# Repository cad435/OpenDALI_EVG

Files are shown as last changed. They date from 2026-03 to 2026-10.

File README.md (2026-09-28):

# OpenDALI_EVG

A completely open-source Proof of concept for a ultra low standby current **DALI-2-compatible** Electronic Control Gear (ECG/EVG) for controlling LEDs. Built around the **CH32V003** RISC-V microcontroller. Implements IEC 62386 — not certified by, affiliated with, or endorsed by the DALI Alliance (DiiA).

> [!WARNING]
> This project is a work in progress and not yet ready for production use. Hardware designs and firmware are subject to change.

> [!NOTE]
> **Trademark notice:** *DALI*, *DALI-2*, *D4i*, *DALI+* and *DiiA* are trademarks of the Digital Illumination Interface Alliance (DiiA). This project is an independent open-source implementation and compatible with the IEC 62386 standard. It is referred to as *DALI-2-compatible*, it has not undergone DiiA certification and may not be marketed as a DALI product.
> Use for educational purposes only!

<p align="center">
  WhatsApp Image 2026-07-07 at 23 02 12
</p>
<p align="center">
  WhatsApp Image 2026-07-07 at 23 02 12 (1)
</p>
<p align="center">
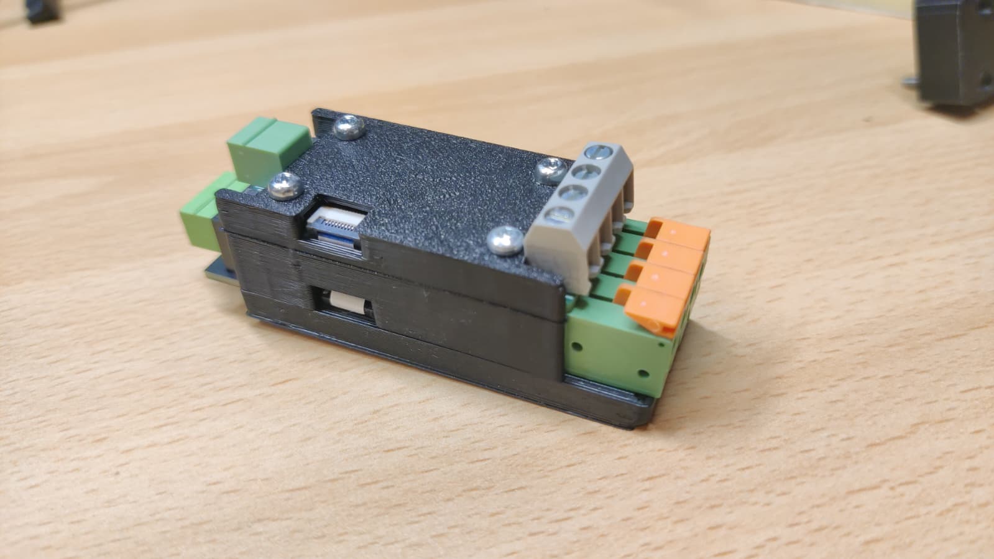
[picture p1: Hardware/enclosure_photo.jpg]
Assembled unit in its printed enclosure
  
</p>

## Overview

This project implements a DALI-2-compatible control gear device per **IEC 62386-101** (bus/protocol) and **IEC 62386-102** (control gear commands), including **DT8 colour control** (IEC 62386-209) for RGBW and colour temperature mixing.

Key highlights:
- Full DALI-2-compatible protocol stack in bare-metal C
- 4-channel PWM output (RGBW) at 20 kHz with 2400-step resolution
- WS2812/SK6812 addressable LED strip support (SPI+DMA, up to ~300 LEDs)
- Logarithmic dimming curve per IEC 62386-102
- 16 scenes, 16 groups, fade engine with configurable fade time/rate
- Full commissioning support (INITIALISE, RANDOMISE, SEARCHADDR, PROGRAM SHORT) — incl. spec-conformant DTR roles for memory bank reads (FW v0.3+)
- All configuration persisted to AT24C256 EEPROM (deferred-write, 5 s debounce)
- Bus-powered: the MCU runs entirely from the DALI bus (< 2 mA quiescent)
- Over-the-air firmware updates via DALI bus (IEC 62386-105 bootloader with Fletcher-16 payload check, auto-resume on fault)
- Verified interop with Mi-Boxer DALI controllers and OpenKNX GW-REG1-Dali gateway

## Project Structure

```
OpenDALI_EVG/
├── Firmware/           CH32V003 DALI slave firmware (PlatformIO project)
├── Bootloader/         IEC 62386-105 compatible DALI bootloader (1908 / 1920 B, I2C EEPROM staging)
├── EVG-Updater/        C# Avalonia tool (.NET 8) — GUI + CLI for firmware flash and bus scan
├── EVG-Flasher/        C# Avalonia app — first-time provisioning of blank chips via WCH-LinkE
├── Hardware/           PCB schematics, Gerbers, JLCPCB BOM/CPL (Controller V0.3 + two LoadBoards V0.1)
└── Simulations/        LTspice PHY and power supply simulations
```

### Firmware

The firmware is a standalone PlatformIO project targeting the CH32V003F4U6, built on [ch32v003fun](https://github.com/cnlohr/ch32v003fun). Supports 8 LED output modes selected via a single `EVG_MODE_xxx` define:

- **ONOFF**: PSU_CTRL switching only — no PWM, no timers
- **PWM modes**: SINGLE (1ch), CCT (2ch), RGB (3ch), RGBW (4ch) — TIM1 at 20 kHz, 2400-step resolution
- **Digital LED modes**: WS2812, SK6812_RGB, SK6812_RGBW — SPI1+DMA on PC6

See [Firmware/README.md](Firmware/README.md) for architecture, commands, and test documentation.

### Bootloader

IEC 62386-105 compatible firmware-over-DALI-bus bootloader (1908 / 1920 bytes, 99.4% of the CH32V003 boot area). Uses 32-bit forward frames for bulk data transfer (3 bytes/frame, ~2.5 min for a full firmware image). Firmware is staged in AT24C256 I2C EEPROM before committing to flash. Validates Block 0 GTIN + EVG mode ID, and verifies the Block 1 firmware payload with a Fletcher-16 checksum at FINISH. On checksum mismatch the BL auto-resumes the previous user firmware (no manual recovery needed). See [Bootloader/README.md](Bootloader/README.md).

### EVG-Updater

C# Avalonia application (.NET 8) — GUI + CLI for both **firmware flashing** (`flash <bin>`) and **bus discovery** (`scan`). The canonical update client. Talks to the OpenKNX GW-REG1-Dali gateway via WebSocket. See [EVG-Updater/README.md](EVG-Updater/README.md).

### EVG-Flasher

Avalonia desktop app for **blank** CH32V003 boards: bootloader to the boot area, option bytes, firmware, then a read-back check of the option bytes — in a loop, one chip after another. The configuration dropdown is fed from `Firmware/platformio.ini`, so a new `[env:...]` section appears without touching the app, and the strip modes get an extra LED-count field. See [EVG-Flasher/README.md](EVG-Flasher/README.md).

### Hardware

PCB designs (schematics, Gerbers, JLCPCB assembly files). See [Hardware/README.md](Hardware/README.md) for board descriptions and details.

- **Controller** — DALI-compatible PHY + CH32V003 MCU board
- **LoadBoard 250W RGBW** — 4-channel PWM LED driver + AC mains switching (ACST410 triac, MOC3043)
- **LoadBoard 250W Digital LED** — isolated single-wire output for WS2812/SK6812 strips, same AC mains switching

**Design goals:**
- **Ultra-low standby (~30 mW):** When LEDs are off, the triac disconnects the external PSU entirely from mains — eliminating its standby consumption. The Controller remains fully operational, powered solely from the DALI bus (< 2 mA).
- **Modular architecture:** The Controller is a standalone unit handling all communication and signal generation. LoadBoards are interchangeable and connect via a standardized FFC interface — swap them to match different power classes without changing the Controller.

### Simulations

LTspice simulations for the DALI-compatible PHY layer:
- **Phy_Non-Isolated.asc** — Bus-powered PHY with direct MCU connection
- **Phy_Isolated.asc** — Optocoupler-isolated PHY variant

## Hardware Platform

| Parameter | Value |
|---|---|
| MCU | CH32V003F4U6 (RISC-V, 48 MHz, 16 KB Flash, 2 KB RAM) |
| DALI-compatible Interface | Via PHY transceiver (PC3 RX, PC4 TX) |
| PWM Channels | 4 (RGBW via TIM1, partial remap 1) |
| Digital LED | WS2812/SK6812 via SPI1+DMA (same pin as PWM CH1, compile-time select) |
| Supply | Bus-powered from the DALI bus only (DC-DC converter) — MCU is always bus-powered |

See [Hardware/README.md](Hardware/README.md) for the full pin assignment table and board details.

## Status

Firmware is functional and verified with the **OpenKNX GW-REG1-Dali gateway** end-to-end. Tested operations include addressing (INITIALISE/RANDOMISE/COMPARE/PROGRAM SHORT), all 16-bit forward commands (level control, scenes, groups, fade), DT8 colour control (RGBW + Tc), bank 0 memory reads, and IEC 62386-105 firmware updates over the bus (with Fletcher-16 integrity check and auto-resume on fault).

Multi-vendor coexistence verified with Mi-Boxer DALI controllers on the same bus (2026-05-17).

## License

MIT

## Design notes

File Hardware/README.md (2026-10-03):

# Hardware

PCB designs for the OpenDALI_EVG project.

> Trademark notice — see [root README](../README.md): *DALI*, *DALI-2* etc. are DiiA trademarks; this project is an independent IEC 62386 implementation, not DiiA-certified.

## Boards

| Board | Description |
|---|---|
| [Controller](Controller/Readme.md) | DALI PHY + CH32V003, bus-powered. Pin assignment, J4 load-board interface, hardware validation. |
| [LoadBoard 250W RGBW](DALI_Load_250W_RGBW/Readme.md) | Mains switching and 4-channel PWM LED driver. Work in progress. |
| [LoadBoard 250W Digital LED](DALI_Load_250W_DigitalLED/Readme.md) | Mains switching and isolated single-wire output for WS2812/SK6812 strips. Work in progress. |

## Enclosure

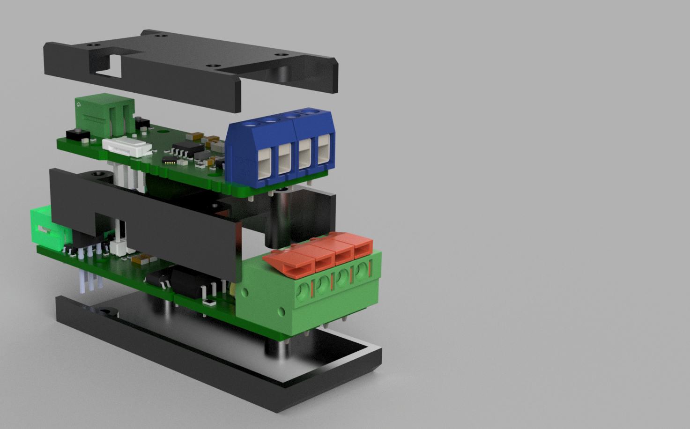
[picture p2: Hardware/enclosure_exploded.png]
Exploded view of the enclosure


3D-printable housing, as a Fusion 360 archive (`DALI_EVG.f3z`) and as a neutral
STEP export (`DALI_EVG.step`). One enclosure covers the Controller together with
any of the load boards above.

Ready-to-print parts are in [`stl/`](stl/) — the housing is a three-part
stack: `Bot`, `Mid` and `Top`.

Eight **M2.5 x 10 mm** screws hold the stack together, four from each side.

> **⚠ Mains safety:** fit the screws on the load-board side only with the
> enclosure part in place, so the plastic sits between screw head and board
> and only the thread passes through the PCB. A screw head resting directly on
> the load board brings an accessible metal part too close to the mains copper:
> the reinforced insulation required by IEC 60664-1 is then no longer met.

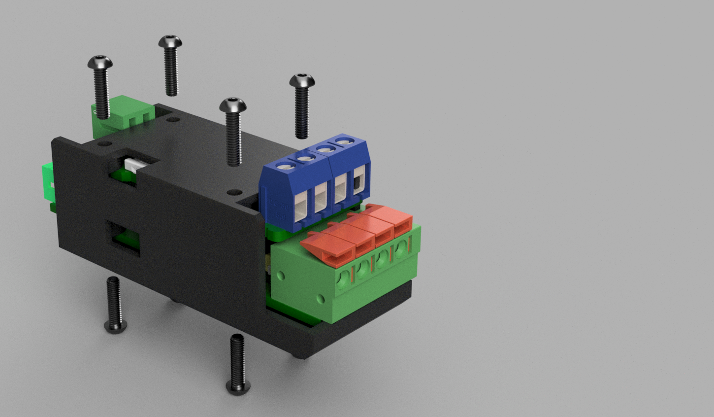
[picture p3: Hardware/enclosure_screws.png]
Screw positions on the assembled enclosure


Assembled unit in its printed enclosure

Controller and load board are linked by a **10-pin FFC, 0.5 mm pitch, 25-50 mm,
reverse** — contacts on opposite sides at the two ends. A same-side cable
does not work: at one end its contacts face away from the connector and
never touch it.

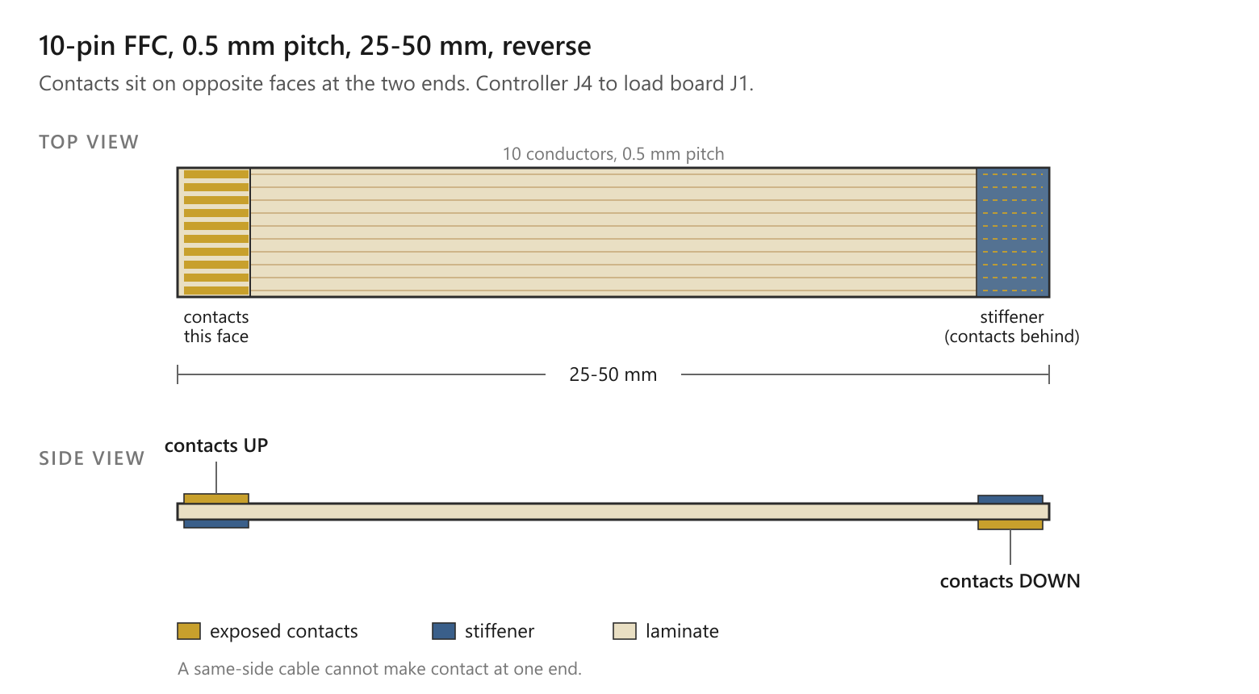
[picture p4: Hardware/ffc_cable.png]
10-pin reverse FFC cable


## Manufacturing

The Gerber files are ready for upload to any PCB manufacturer. The JLCPCB files (BOM + CPL) allow direct ordering with SMT assembly through [JLCPCB](https://jlcpcb.com/).

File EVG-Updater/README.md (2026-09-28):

# DALI-bus Firmware Updater

<p align="center">

</p>

C# desktop application ([Avalonia](https://avaloniaui.net/)) for updating and inspecting OpenDALI EVG devices via the DALI bus, using an OpenKNX GW-REG1-Dali gateway.

Run without arguments for the GUI; every subcommand below also works headless, so scripted flashing is unaffected by the UI.

Implements the IEC 62386-105 firmware update protocol over 32-bit DALI forward frames, plus a read-only bus scan that probes shorts 0..63 and reads bank 0 identity.

> Trademark notice — see [root README](../README.md): *DALI*, *DALI-2* etc. are DiiA trademarks; this project is an independent IEC 62386 implementation, not DiiA-certified. Educational purposes only

## Requirements

- .NET 8.0 SDK
- OpenKNX GW-REG1-Dali gateway on the network
- Target device running OpenDALI EVG firmware with IEC 62386-105 bootloader in boot area

## Build

```bash
dotnet build EVG_Updater.slnx
```

## Usage

```
EVG_Updater <command> [options]
```

Commands:

| Command | Purpose |
|---|---|
| `flash <firmware.bin>` | Flash a firmware image to an EVG via DALI bus |
| `scan` | Probe the DALI bus and list discovered gear |
| *(no args)* | Launch the graphical interface |

Run `EVG_Updater <command> --help` for per-command details.

### GUI Mode

Run without arguments to launch the graphical interface:

```bash
EVG_Updater.exe
```

The GUI provides:
- Gateway IP configuration (default: 192.168.178.131)
- Bus scan with sortable device grid (Short / Random / GTIN / Mode / DT / FW / HW / Updatable)
- Firmware .bin file selection
- DALI short address (0-63)
- GTIN and EVG Mode ID for Block 0 validation
- **Override mode check** — announces the mode the device currently reports,
  taken from the scan, instead of the Mode ID field. This is what lets one of
  our EVGs be reflashed to a *different* mode: the bootloader validates against
  the mode the running firmware wrote, and the new firmware writes its own on
  first boot. "Update All" already works this way and ignores the setting.
- Progress bar and scrollable log output

### `flash` — Firmware Update

```bash
EVG_Updater.exe flash firmware.bin [options]
```

Options:

| Option | Default | Description |
|---|---|---|
| `--ip <address>` | 192.168.178.131 | Gateway IP address |
| `--addr <0-63>` | 0 | DALI short address of target device |
| `--gtin <hex>` | 3452334E0CAD | 6-byte GTIN in hex (must match device EEPROM) |
| `--mode <1-8>` | 5 (RGBW) | EVG mode ID (must match device EEPROM) |
| `--help`, `-h` | | Show usage help |

Exit codes:
- `0` — Success
- `1` — Argument or connection error
- `2` — Firmware update failed

Examples:

```bash
# Update device at address 0 with default settings
EVG_Updater.exe flash firmware.bin

# Update device at address 5, RGB mode
EVG_Updater.exe flash firmware.bin --addr 5 --mode 4

# Use a different gateway
EVG_Updater.exe flash firmware.bin --ip 10.0.0.50

# Build and flash in one command (from Firmware/ directory)
pio run && ../EVG-Updater/EVG_Updater.exe flash .pio/build/EVG_RGBW/firmware.bin
```

### `scan` — Bus Discovery

Probes every short address 0..63 with `QUERY GEAR PRESENT`, then for each
responding gear reads bank 0 (GTIN, FW/HW versions, EVG mode via serial
field) and the 24-bit random address. Read-only — never modifies addressing
or any persistent state.

```bash
EVG_Updater.exe scan [options]
```

Options:

| Option | Default | Description |
|---|---|---|
| `--ip <address>` | 192.168.178.131 | Gateway IP address |
| `--ours-gtin <hex>` | 3452334E0CAD | GTIN to flag as updatable in the Updatable column |
| `--quiet`, `-q` | | Suppress progress log, print only the result table |
| `--help`, `-h` | | Show usage help |

Output mirrors the GUI grid columns: **Short, Random, GTIN, Mode, DT, FW, HW, Updatable**.

Example (quiet mode for scripting):

```bash
$ EVG_Updater.exe scan --quiet
Short  Random    GTIN          Mode  DT     FW   HW   Updatable
-----  --------  ------------  ----  -----  ---  ---  ---------
0      0xCAF8CB  3452334E0CAD  RGBW  DT8    0.2  0.1  yes
1      0x93D441  3452334E0CAD  RGBW  DT8    0.2  0.1  yes
2      0xFE7CCA  —             ?     multi  —    —    no
```

Underlying DALI sequence (IEC 62386-102 Ed 2.0 §11.x cmd 197): `QUERY GEAR PRESENT`
on each short, then once globally `DTR1 ← 0` (bank 0) and `DTR0 ← 0x03` (GTIN start)
via the special commands `0xC3` / `0xA3`, then per gear 18× `READ MEMORY LOCATION`
to walk bank 0 offsets 0x03..0x14 (post-increment of DTR0 is gear-local, so back-to-back
reads on the same gear walk the bank without re-setting DTR0), plus `QUERY DEVICE TYPE`
and `QUERY RANDOM ADDRESS (H/M/L)` per gear.

Devices that don't implement bank 0 (some non-conformant third-party gear like Mi-Boxer)
appear with `—` / `?` in the bank-0-derived columns but still get their `Random` and
device-type info from the dedicated queries.

`DaliBusScanner.cs` has a `READ_INTER_FRAME_DELAY_MS` constant (default `0`, well-tested
since the FW back-to-back-drop fix). Bump it to 100 ms as a workaround if you somehow
encounter a regression where scan results look shifted.

## EVG Mode IDs

| ID | Mode | Description |
|----|---|---|
| 1 | ONOFF | Relay/switch output |
| 2 | SINGLE | Single-channel PWM |
| 3 | CCT | 2-channel warm/cool white |
| 4 | RGB | 3-channel RGB PWM |
| 5 | RGBW | 4-channel RGBW PWM |
| 6 | WS2812 | Addressable LED strip (GRB) |
| 7 | SK6812_RGB | Addressable LED strip (GRB) |
| 8 | SK6812_RGBW | Addressable LED strip (GRBW) |

## Update Protocol (IEC 62386-105)

The update runs in 4 phases:

1. **Enter Bootloader** — Send QUERY FW UPDATE FEATURES (verify device supports updates), then START FW TRANSFER (config repeat, 2× within 100 ms). Device responds YES and resets into bootloader.

2. **Block 0 Validation** — Send BEGIN BLOCK 0 followed by TRANSFER BLOCK DATA frames containing GTIN, device key (EVG mode ID), and the pre-computed Fletcher-16 of the firmware payload at offsets `0x2C` / `0x2D`. The bootloader validates GTIN + mode against EEPROM identity. Updater polls `QUERY BLOCK FAULT` once at the end of this phase — that's the only window where the BL's `blockFault` flag can reflect a Block-0 fault (BEGIN BLOCK 1 wipes it).

3. **Firmware Transfer** — Send BEGIN BLOCK 1, then TRANSFER BLOCK DATA frames (3 firmware bytes per frame, ~3,600 frames for ~11 KB firmware). Data is staged in AT24C256 EEPROM (starting at 0x0080). **No mid-transfer polls** — they're structurally dead (BL's `blockFault` flag can only be set during Block-0 reception or at FINISH, never during Block-1 reception; payload integrity is verified inside the FINISH handler).

4. **Commit** — Send FINISH FW UPDATE (config repeat). The bootloader compares its accumulated Fletcher-16 against the expected value from Block 0:
   - Match: `flush_to_eeprom()` + `copy_eeprom_to_flash()` + auto-reboot into new firmware. Bus stays silent → updater sees `null` timeout → `SUCCESS`.
   - Mismatch: BL sends `0xFF` (= YES, "not done"), then auto-reboots into the existing firmware (flash untouched). Updater receives `0xFF` → reports `FAILED: Fletcher mismatch, re-run flash`.

## Project Structure

```
EVG-Updater/
├── EVG_Updater.slnx             Solution file (open in Visual Studio)
├── README.md                     This file
└── EVG_Updater/
    ├── EVG_Updater.csproj       .NET 8.0 Avalonia project
    ├── Program.cs                Entry point — subcommand dispatch (GUI / flash / scan)
    ├── App.axaml(.cs)            Avalonia application, themes, DataGrid style
    ├── Views/MainWindow.axaml    GUI layout
    ├── ViewModels/MainViewModel  GUI state, commands, bus orchestration
    ├── Models/DeviceRow.cs       one scan result as a grid row
    ├── DaliGateway.cs            WebSocket client (background reader + in-flight pacing semaphore)
    ├── DaliBootloader.cs         IEC 62386-105 protocol state machine (4-phase update)
    └── DaliBusScanner.cs         Read-only bus scan (shorts 0..63, bank 0, random address)
```

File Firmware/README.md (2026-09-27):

# DALI-2-compatible EVG Firmware

DALI-2-compatible control gear (slave) firmware for the **CH32V003F4U6** RISC-V microcontroller, built on [cnlohr's ch32fun](https://github.com/cnlohr/ch32v003fun) framework. Drives up to 4 PWM channels (RGBW) with full IEC 62386 protocol support, DT8 colour control, and EEPROM persistence.

> Trademark notice — see [root README](../README.md): *DALI*, *DALI-2* etc. are DiiA trademarks; this project is an independent IEC 62386 implementation, not DiiA-certified.

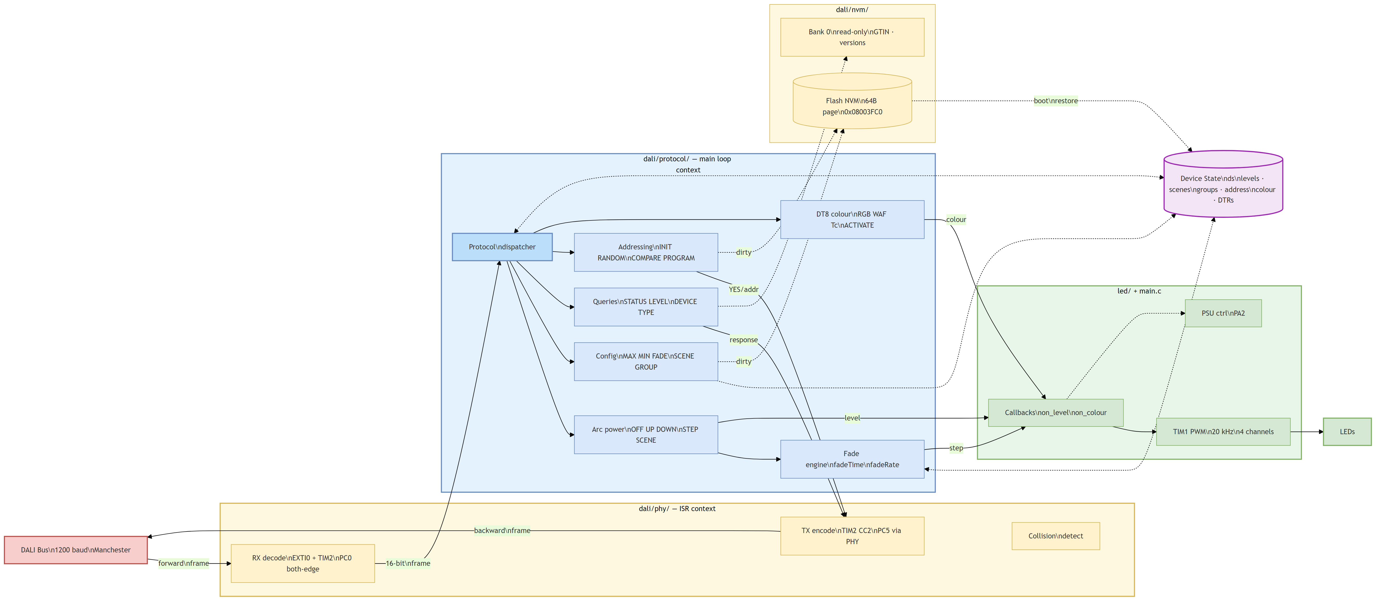
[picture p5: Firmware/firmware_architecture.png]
Firmware Architecture


## EVG Modes

The firmware supports 8 LED output modes, selected via a single `EVG_MODE_xxx` define in `hardware.h` (or `-DEVG_MODE_xxx` compiler flag). All internal configuration (DALI device type, channel count, driver, DT8 features) is derived automatically.

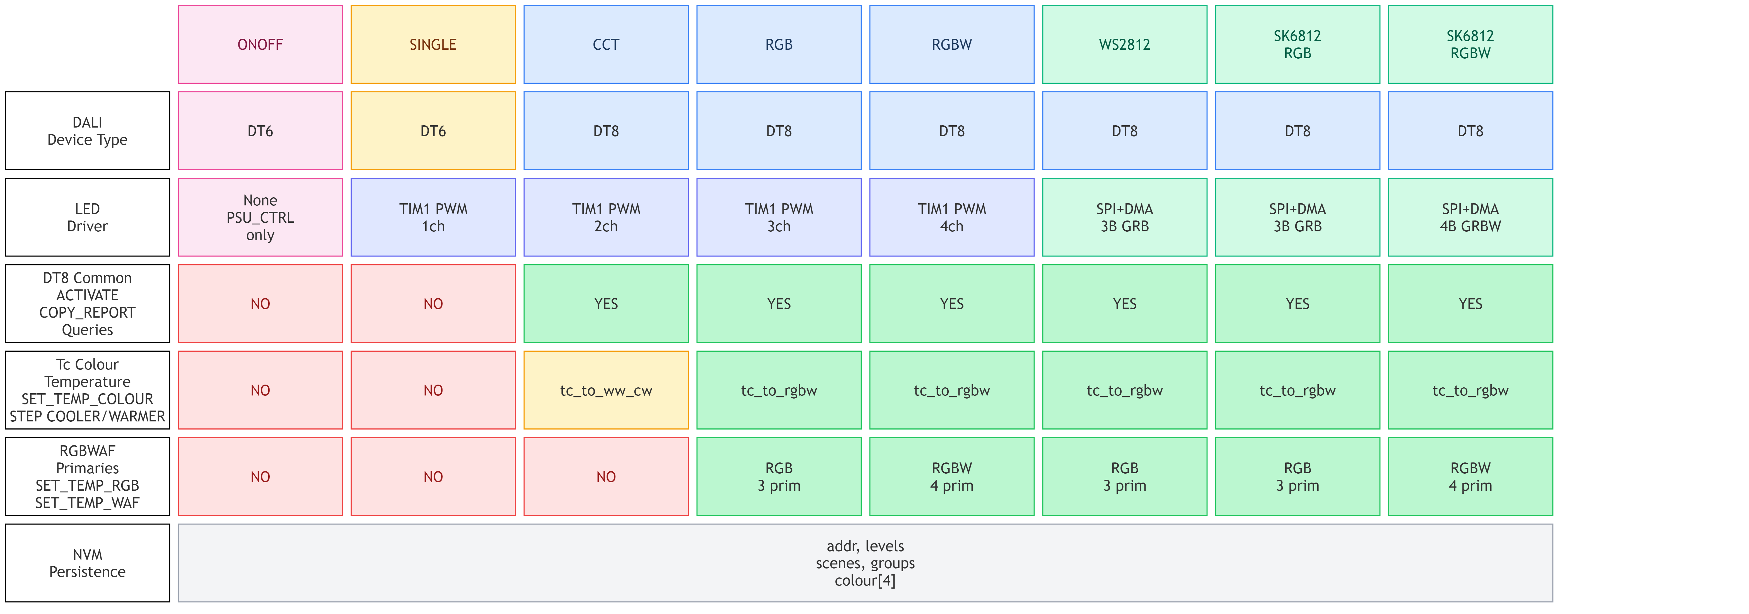
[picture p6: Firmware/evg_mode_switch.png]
EVG Mode Feature Matrix


| Mode | DT | Channels | Driver | Tc | Primary |
|---|-----|---|---|-----|---|
| `EVG_MODE_ONOFF` | 6 | 0 | PSU_CTRL only | - | - |
| `EVG_MODE_SINGLE` | 6 | 1 PWM | TIM1 | - | - |
| `EVG_MODE_CCT` | 8 | 2 PWM | TIM1 | yes | no |
| `EVG_MODE_RGB` | 8 | 3 PWM | TIM1 | yes | yes |
| `EVG_MODE_RGBW` | 8 | 4 PWM | TIM1 | yes | yes |
| `EVG_MODE_WS2812` | 8 | 3 (GRB) | SPI+DMA | yes | yes |
| `EVG_MODE_SK6812_RGB` | 8 | 3 (GRB) | SPI+DMA | yes | yes |
| `EVG_MODE_SK6812_RGBW` | 8 | 4 (GRBW) | SPI+DMA | yes | yes |

Default: `EVG_MODE_RGBW`. ONOFF mode compiles out all LED drivers, log table, and TIM1 — only PSU_CTRL (PA2) switches on/off. PHY_MIN = 254 (any non-zero arc level → full on). SINGLE mode compiles out all DT8 code.

## Features

- **IEC 62386-101** — Manchester-encoded physical layer at 1200 baud with DALI PHY transceiver, bus collision detection
- **IEC 62386-102** — Full DALI protocol: addressing, arc power, fading, scenes, groups, configuration
- **IEC 62386-209 (DT8)** — RGBW colour control with colour temperature (Tc) support
- **Logarithmic dimming** — IEC 62386-102 compliant 254-step lookup table
- **Flash persistence** — All configuration survives power cycles (deferred write with 5s debounce)
- **On/off mode** — PSU_CTRL-only relay/switch output, no timers or PWM
- **20 kHz PWM** — 4 channels via TIM1 with 2400-step resolution (11.2 bit); dynamic frequency shift to 6.67 kHz at deep dimming levels (keeps every pulse ≥ 250 ns for the isolator/gate-driver chain, duty unchanged; engages only while every channel is ≤ 3.75 % duty to avoid audible MLCC whine) plus a 250 ns minimum-pulse failsafe clamp
- **WS2812/SK6812 support** — Alternative digital LED output via SPI1+DMA on PC6. The core must not sleep during a transfer (`__WFI()` stalls SPI/DMA on this part), so `led_driver_busy()` guards the sleep condition; strip data is re-sent every `LED_REFRESH_MS` (default 1 s) purely as glitch recovery.

## What Works

| Area | Status |
|---|---|
| Forward frame RX (16-bit and 32-bit Manchester decode) | Working |
| Backward frame TX (8-bit Manchester encode) | Working |
| Short address, group, and broadcast addressing | Working |
| Full addressing protocol (INITIALISE, RANDOMISE, SEARCHADDR, PROGRAM) | Working |
| Arc power commands (DAPC, OFF, UP/DOWN, STEP, RECALL, SCENE) | Working |
| Fade engine (fadeTime + fadeRate + extended fade time) | Working |
| Configuration commands (42-128) with config repeat validation | Working |
| All standard queries (144-199) | Working |
| READ MEMORY LOCATION (cmd 197) → Memory Bank 0 (read-only gear info) | Working — spec-conformant DTR roles since v0.3 (DTR1=bank, DTR0=offset post-inc, DTR2=look-ahead) per IEC 62386-102:2009 §11.x cmd 197 |
| Structured frame type (`dali_frame_t` with FORWARD/BACKWARD/ERROR/COLLISION/ECHO flags) | Working |
| TX echo / collision detection (via DALI PHY) | Working |
| Status byte (resetState, powerCycleSeen, lampOn, fadeRunning) | Working |
| 16 scenes, 16 groups | Working |
| DT8 RGBW colour control (SET TEMP RGB/WAF, ACTIVATE) | Working |
| DT8 colour temperature with Tc-to-RGBW conversion (2700K-6500K) | Working |
| DT8 queries (247-252) | Working |
| NVM persistence via I2C EEPROM (AT24C256, all config + colour + identity) | Working |
| PSU control output (PA2, auto on/off) | Working |
| WS2812/SK6812 digital LED strip output (SPI1+DMA) | Working — verified on hardware with a logic analyser (bit-exact frames on the wire) |
| DALI PHY transceiver mode (TX/RX with collision detection) | Working |
| IEC 62386-105 START FW TRANSFER (32-bit frame) → bootloader entry | Working |

## What Doesn't Work / Not Implemented

| Area | Reason |
|---|---|
| Memory bank 1 + write access | Read-only bank 0 only; writable banks not implemented |
| DALI-2 diagnostic queries (166-175) | Require hardware monitoring circuitry (current/voltage sensing) |
| CIE xy chromaticity | Requires per-LED spectral calibration |
| ENABLE DAPC SEQUENCE (cmd 9) | Rarely used, complex timing |
| Tc temperature limits (store/query) | Not yet implemented |
| controlGearFailure / lampFailure status bits | Require hardware monitoring (I2C ADC planned) |

## Hardware

CH32V003F4U6 (QFN20, 48 MHz, 16 KB Flash, 2 KB RAM) with DALI PHY transceiver. TIM1 Partial Remap 1 (`RM=01`) enables PC6 dual-use for both PWM and WS2812.

| Pin | Function | Peripheral | Notes |
|-----|---|---|---|
| PA1 | Boot button | GPIO input | Active low at reset → enter DALI bootloader (firmware also reroutes into BL when PA1 is held during NRST/SYSRESETREQ) |
| PA2 | PSU Control | GPIO output | HIGH = external PSU on, LOW = off |
| PC0 | LED3 / Blue PWM | TIM1_CH3 | 20 kHz, 2400-step |
| PC1 | I2C SDA | I2C1 | Reserved for AT24C256C EEPROM |
| PC2 | I2C SCL | I2C1 | Reserved for AT24C256C EEPROM |
| PC3 | DALI RX | EXTI3 | From PHY RX_OUT, both-edge interrupt |
| PC4 | DALI TX | GPIO output | To PHY TX_IN, Manchester encode |
| PC5 | SPI1 SCK → J4.3 | SPI1 | SPI clock to the load board (ribbon J4 pin 3); unused in direct-PWM modes |
| PC6 | LED1 / Red PWM **or** WS2812 | TIM1_CH1 / SPI1_MOSI | Dual-use: PWM or SPI+DMA (compile-time) |
| PC7 | LED2 / Green PWM | TIM1_CH2 | 20 kHz, 2400-step |
| PD0 | *(spare)* | — | Free GPIO (was USB D+ pull-up in old USB-BL prototype; current BL is DALI-only) |
| PD1 | SWDIO | SWD | Single-wire debug |
| PD2 | *(spare)* | — | Free GPIO |
| PD3 | LED4 / White PWM | TIM1_CH4 | 20 kHz, 2400-step |
| PD4 | *(spare)* | — | Free GPIO |
| PD5 | Debug UART TX | USART1_TX | 115200 baud |
| PD6 | Debug UART RX | USART1_RX | 115200 baud |
| PD7 | NRST | Reset | Hardware reset |

See [Hardware/README.md](../Hardware/README.md) for full board details.

## Build & Flash

```bash
pio run                    # Build
pio run -t upload          # Flash via PlatformIO
# or directly:
wlink flash .pio/build/EVG_RGBW/firmware.bin
```

## Provisioning Blank EVGs

First-time programming of a blank chip — bootloader, option bytes and firmware —
is done with [EVG-Flasher](../EVG-Flasher/README.md). It runs the four-step
sequence in a loop and picks the configuration from a dropdown that is fed by
this `platformio.ini`, so a new `[env:...]` section shows up there by itself.

Updating an **already commissioned** EVG happens over the DALI bus with
[EVG-Updater](../EVG-Updater/README.md) instead.

## Documentation

- [Commands_Implemented.md](Commands_Implemented.md) — Full command-by-command status table
- [firmware_architecture.mmd](firmware_architecture.mmd) — Mermaid source for architecture diagram
- [evg_mode_switch.mmd](evg_mode_switch.mmd) — Mermaid source for EVG mode feature matrix
- [test/](test/) — HIL test setup and test scripts

## License

MIT

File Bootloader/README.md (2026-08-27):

# DALI-bus Bootloader for CH32V003 — IEC 62386-105 Compatible

Firmware-over-DALI-bus bootloader using 32-bit forward frames as specified in IEC 62386-105:2020. Fits in the 1920-byte boot area. Receives firmware via the DALI bus protocol, stages it in an external I2C EEPROM, validates device identity via Block 0, then copies to internal flash.

**1,908 / 1,920 bytes (99.4%)** (PlatformIO build, optimised version adopted 2026-08-15) — interoperates with IEC 62386-105 compatible firmware-update masters.

> Trademark notice — see [root README](../README.md): *DALI*, *DALI-2* etc. are DiiA trademarks; this project is an independent IEC 62386 implementation, not DiiA-certified.

## How It Works

- 32-bit forward frame decoder at 1200 baud (IEC 62386-101, 7.4.3)
- Accepts IEC 62386-105 commands: START FW TRANSFER, BEGIN BLOCK, TRANSFER BLOCK DATA, FINISH FW UPDATE, RESTART FW, QUERY BLOCK FAULT, QUERY FW UPDATE RUNNING
- **Block 0 validation**: GTIN (6 bytes) and Device key byte 0 (EVG mode ID) are compared against values stored in EEPROM by the firmware. Mismatch → QUERY BLOCK FAULT returns YES → master aborts
- **Fletcher-16 integrity check**: Block 0 also carries a 2-byte Fletcher-16 of the firmware payload at positions `0x2C`/`0x2D`. The bootloader accumulates `fa`/`fb` over every received Block 1 firmware byte and compares against the expected value at FINISH. Mismatch → flash commit aborted, master sees BLOCK FAULT
- Block 1..n firmware data is extracted from the block structure (headers and trailing CRC skipped) and streamed to the I2C EEPROM staging area
- On FINISH FW UPDATE (no fault): EEPROM contents are copied to internal flash, then device auto-reboots into the new firmware (silent on the bus — master sees timeout)
- On FINISH FW UPDATE (Fletcher mismatch): BL sends `0xFF` (= YES, "not done") as an explicit fault signal, then auto-resumes the **existing** user firmware that's still untouched in flash. Master can detect the explicit fault and report `UPDATE FAILED` to the user. Added 2026-05-17 to eliminate the previous failure mode where the EVG appeared "dead" until manual power-cycle.
- Other DALI devices on the bus are **not affected** — 32-bit frames are silently ignored per IEC 62386-101

## Speed

3 firmware bytes per 32-bit frame (vs 1 byte per 2 frames in the original bootloader). Expected transfer time for 10 KB firmware: **~2.5 minutes**.

## Boot Entry

Two ways to enter bootloader mode:

1. **Software**: Firmware receives START FW TRANSFER (32-bit, device-addressed), responds YES, sets `FLASH->STATR` bit 14 via the WCH `SystemReset_StartMode` sequence, and resets. The bootloader checks bit 14 on startup and enters update mode if set. Bit 14 is cleared immediately after reading (one-shot).
2. **Hardware**: Hold **PA1 low** during reset. The bootloader enters update mode and responds YES to any subsequent START FW TRANSFER from the master.

If neither condition is met, the bootloader jumps directly to user code.

**Note**: RAM magic words do NOT survive PFIC system reset on CH32V003. The `FLASH->STATR` bit 14 approach is used.

## Protocol

Bootloader Protocol

### Phase 1 — Enter Bootloader (handled by firmware)

| Frame | Direction | Description |
|---|---|---|
| `[addr] [0xFB] [0x05] [0x00]` | Master → Device | QUERY FW UPDATE FEATURES (firmware responds 0x00) |
| `[addr] [0xFB] [0x00] [0x00]` ×2 | Master → Device | START FW TRANSFER (config repeat) |
| `0xFF` | Device → Master | YES — firmware ACKs, then resets into bootloader |

### Phase 2 — Block 0 Validation (handled by bootloader)

| Frame | Direction | Description |
|---|---|---|
| `[0xCB] [0x00] [0x00] [0x00]` | Master → Bootloader | BEGIN BLOCK 0 (info block) |
| `[0xBD] [d0] [d1] [d2]` ×21 | Master → Bootloader | Block 0 data — GTIN at pos 5-10, Device key at pos 0x2B validated against EEPROM; Fletcher-16 expected stored from pos 0x2C/0x2D |
| `[0xBF] [0xFB] [0x08] [0x00]` | Master → Bootloader | QUERY BLOCK FAULT — silence = OK, YES = GTIN/mode mismatch |

### Phase 3 — Firmware Data Transfer

| Frame | Direction | Description |
|---|---|---|
| `[0xCB] [blk_h] [blk_m] [blk_l]` | Master → Bootloader | BEGIN BLOCK 1..n (resets `blockFault` and Fletcher accumulator) |
| `[0xBD] [d0] [d1] [d2]` | Master → Bootloader | TRANSFER BLOCK DATA — 3 firmware bytes per frame, no response. Each firmware byte feeds `fa += d; fb += fa;` |
| `[0xBF] [0xFB] [0x08] [0x00]` | Master → Bootloader | QUERY BLOCK FAULT — silence = no fault |

Block 1..n: bytes 0-1 = data size (s), bytes 2-14 = header (skipped), bytes 15..s+14 = firmware data (stored to EEPROM staging area at 0x0080+), bytes s+15..s+16 = trailing CRC (skipped, bootloader uses Fletcher-16 over the firmware payload instead).

### Phase 4 — Commit

| Frame | Direction | Description |
|---|---|---|
| `[0xBF] [0xFB] [0x03] [0x00]` ×2 | Master → Bootloader | FINISH FW UPDATE (config repeat) — bootloader compares accumulated `fa`/`fb` against expected and rejects a zero-length transfer. If everything matches and no prior fault: erases the full 16 KB of user flash, copies EEPROM → flash (vector page last), re-computes Fletcher-16 **over the flash contents**, and auto-reboots. Any mismatch sets BLOCK FAULT and aborts without committing. |
| `[addr] [0xFB] [0x01] [0x00]` | Master → Bootloader | RESTART FW (if needed) — responds YES, reboots |

## Firmware Storage Path

CH32V003 flash cannot be erased and written while code is executing from the same flash region. The bootloader sits in the boot area at `0x1FFFF000`, so it can write to user-flash at `0x08000000` — but the incoming firmware bytes have to be buffered somewhere while we're still receiving them. RAM is only 2 KB, far too small for a 10 KB firmware image. Solution: stage everything in the external **AT24C256 I2C EEPROM** (32 KB), then commit to user-flash in one pass at the end.

```mermaid
%%{init: {'theme': 'base', 'themeVariables': {
  'primaryColor': '#dbeafe', 'primaryTextColor': '#1e3a5f', 'primaryBorderColor': '#3b82f6',
  'lineColor': '#1d4ed8', 'fontSize': '14px'
}}}%%
flowchart LR
    M[DALI Master] -- "DALI<br/>3 B/frame" --> BL["Bootloader<br/>page_buf 64 B RAM"]
    BL -- "I2C write<br/>every 64 B" --> EE[("AT24C256<br/>EEPROM staging<br/>0x0080+")]
    EE -- "I2C read +<br/>flash write<br/>(on FINISH)" --> UF[("User Flash<br/>0x08000000")]
```

**Power-loss robustness.** Up until `FINISH FW UPDATE` succeeds and `copy_eeprom_to_flash()` starts erasing pages, user flash is untouched — losing power simply means the existing firmware boots normally on the next power cycle and the master can retry.

The erase + copy phase is not atomic, but it is **guarded by a commit marker**: the vector page at offset 0 is written **last**, and boot only jumps to user code when `*(uint32_t*)0x08000000 != 0xFFFFFFFF`. A power loss anywhere mid-commit therefore leaves the vector page erased, and the next power-on lands back in the bootloader with the EEPROM staging still intact — re-run the update over the bus. No WCH-Link needed.

**Three safeguards on the commit path** (all added after the initial release):

1. **Read-back verify.** Fletcher-16 originally covered only the *received* DALI bytes; the EEPROM → I²C read-back → flash write path was unverified, so an I²C glitch or a failed write still produced a valid-looking commit marker and a device booting corrupt code. The checksum is now recomputed over the actual flash contents after the copy. On mismatch the vector page is erased again, `0xFF` is sent, and the device resets back into the bootloader for an immediate retry.
2. **Full 16 KB erase.** `NUM_PAGES` used to subtract the bootloader size from the user flash even though the bootloader lives in the *separate* boot area, so only the first 14,464 B were erased. Anything larger was programmed into pages that were never erased — silent corruption, with no warning from either side.
3. **Empty-update rejection.** `START` followed by `FINISH` with no data blocks passed the Fletcher check (0 == 0) and wiped the flash. `fw_total_size == 0` is now a fault.

**Why Fletcher-16 instead of full CRC.** Fletcher fits in ~12 bytes of code (two `uint8_t` accumulators with rolling sum-of-sums) and matches CRC-16-CCITT in detection probability for the random-error and burst-error patterns seen on a DALI bus. Real CRC-16/32 with table-free implementation costs ~50-70 bytes — too expensive for the 1920-byte boot area when it has to coexist with the existing GTIN/mode validation, EEPROM driver, flash programming, and Manchester RX/TX.

## EEPROM Layout

The AT24C256 EEPROM serves as both persistent config storage and firmware staging area. Layout is shared between firmware and bootloader (defined in `Firmware/src/eeprom/eeprom_layout.h`).

```
AT24C256 (32 KB = 0x0000–0x7FFF)
├── 0x0000–0x003F  Device identity (64 B)
│   ├── 0x0000  magic (4 B, "DALI" = 0x44414C49)
│   ├── 0x0004  GTIN (6 B, MSB first)
│   ├── 0x000A  EVG mode ID (1 B)
│   ├── 0x000B  HW version major/minor (2 B)
│   ├── 0x000D  FW version major/minor (2 B)
│   └── 0x000F  short_address (1 B)
├── 0x0040–0x007F  DALI config (64 B, same struct as dali_nvm_t)
└── 0x0080–0x7FFF  Firmware staging area (32,640 B)
```

The identity block is written by the firmware at every boot. The bootloader reads it to:
1. Determine the device's DALI short address (for START FW TRANSFER addressing)
2. Validate Block 0 GTIN and Device key against the device's identity

## Pin Usage

| Pin | Function | Notes |
|-----|---|---|
| PC1 | I2C SDA | AT24C256 EEPROM |
| PC2 | I2C SCL | AT24C256 EEPROM |
| PC3 | DALI RX | Input, floating (from PHY RX_OUT) |
| PC4 | DALI TX | Output, push-pull (to PHY TX_IN) |
| PA1 | Boot button | Input, pull-up, active low at reset |

## Prerequisites

The CH32V003 option bytes must be configured to boot from the bootloader area. Flash `configurebootloader.bin` once per chip using a WCH-LinkE programmer:

```
wlink flash configurebootloader.bin
```

## Testing & End-to-End Verification

The full chain — KNX bus → Gateway → DALI bus → bootloader → I2C EEPROM staging → user-flash commit → reboot — can be exercised and verified independently.

Brief recipe of the actual run that proved every step:

 - Pushed the new `firmware.bin` over DALI. The Uploader computes Fletcher-16 once on the host and embeds it in Block 0, then transfers ~3 600 BLOCK_DATA frames in ~2.5 minutes.
 - Flashed firmware came online (verified via boot-banner `Build:` timestamp on UART).
 - Dumped AT24C256 over UART, checked against the FW-Binary byte-for-byte. All ~11 KB firmware bytes matched, trailing region clean.

### Driving an update from a host PC

The `EVG-Updater` C# application is the canonical update client. It implements the full IEC 62386-105 sequence and pushes a `firmware.bin` over the gateway WebSocket API:

1. Pre-computes Fletcher-16 over the firmware payload and embeds it in Block 0 at positions `0x2C` / `0x2D`
2. Sends START FW TRANSFER → Block 0 (with GTIN, mode, Fletcher-expected) → polls QUERY BLOCK FAULT (catches GTIN/mode mismatch before pumping ~11 KB of payload) → Block 1 firmware bytes → FINISH FW UPDATE
3. Checks FINISH response — `0xFF` = explicit Fletcher fault from BL (commit aborted, EVG auto-resumed previous FW), `null`/timeout = success (EVG silently rebooted into new FW)

## Build

Requires PlatformIO's RISC-V toolchain (`riscv-wch-elf-gcc`). All dependencies (`ch32v003fun.h`, `libgcc.a`) are included in the `ch32v003fun/` subfolder.

Two equivalent build paths are supported:

**PlatformIO (recommended):**
```
pio run
```
Output: `.pio/build/dali_bootloader/firmware.bin`

The build uses no PIO framework — only the platform's bare-metal flag set (`_bare.py` auto-load). `src/bootloader.ld` and `src/startup.S` override PIO's defaults via `board_build.ldscript` and `build_src_filter`; `trim_link_flags.py` (a PIO `post:` hook) appends `-flto` and `-Wl,--print-memory-usage` to the link line and links the vendored `ch32v003fun/libgcc.a`.

**Legacy raw-GCC:**
Double-click `build.bat` or run from command line. Output: `dali_bootloader.bin` at the project root.

Both paths use the same toolchain, same sources, same linker script, same vendored libgcc.a. The PIO output is currently smaller than the build.bat output due to `-msmall-data-limit=0` (PIO default for CH32V0) vs `=8` (build.bat). Current PIO size: **1908 B of 1920 B** (99.4 %).

## Flash

`flash.bat` automatically picks up the PIO output if present, otherwise falls back to the legacy `dali_bootloader.bin`.

Or manually:
```
wlink flash --address 0x1FFFF000 .pio/build/dali_bootloader/firmware.bin
```

NOTE: `pio run -t upload` is **not** wired up — PIO's stock wch-link upload writes to the application area (0x08000000), not the bootloader area (0x1FFFF000). Use `flash.bat` or the manual `wlink` invocation above instead.

## Resource Usage

| Resource | Value |
|---|---|
| Flash | **1,908 B / 1,920 B (99.4%)** (PIO build, 2026-08-15; legacy build.bat numbers are stale until rebuilt) |
| RAM | ~150 B (stack + variables) |
| I2C | I2C1, 100 kHz, AT24C256 at address 0x50 |

## Important: TX Polarity (PHY Mode)

With a DALI PHY transceiver: **TX HIGH = bus active (mark), TX LOW = bus idle (space)**. The bootloader must initialize PC4 to LOW (idle) and use the correct Manchester encoding:
- `tx_active()` = GPIO HIGH = PHY pulls bus to 0V
- `tx_idle()` = GPIO LOW = PHY releases bus

The firmware's `dali_phy.c` uses the same convention (`BSHR` = active, `BCR` = idle).

## Files

Directory layout follows the PlatformIO convention (`src/` for compiled sources, `include/` for headers).

| File | Description |
|---|---|
| `platformio.ini` | PIO build config (no framework; uses `_bare.py` auto-load) |
| `trim_link_flags.py` | PIO `post:` hook — adds `-flto`, `-Wl,--print-memory-usage`, vendored libgcc to link |
| `build.bat` | Legacy raw-GCC build script (parallel path, kept for reference) |
| `flash.bat` | Flash bootloader to boot area via WCH-LinkE (picks PIO or legacy `.bin`) |
| `src/dali_bootloader.c` | Main bootloader source |
| `src/startup.S` | Minimal startup (vector table, stack init, BSS zero) |
| `src/bootloader.ld` | Linker script (boot area: 0x00000000, 1920 bytes) |
| `include/funconfig.h` | ch32v003fun config |
| `ch32v003fun/` | Vendored dependencies: `ch32v003fun.h` + `libgcc.a` |
| `dali_bootloader.bin` | Pre-built binary from build.bat (1,896 bytes) |
| `.pio/build/dali_bootloader/firmware.bin` | PIO build output (1,908 bytes, after `pio run`) |
| `configurebootloader.bin` | Option bytes configurator (run once per chip) |
| `bootloader_protocol.mmd` | Protocol sequence diagram (Mermaid source) |
| `bootloader_protocol.png` | Rendered protocol diagram |
| `archive/` | Backup of the verified-working production BL (source + binary) |

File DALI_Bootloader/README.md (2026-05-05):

# DALI Bootloader for CH32V003 — IEC 62386-105 Compatible

Firmware-over-DALI-bus bootloader using 32-bit forward frames as specified in IEC 62386-105:2020. Fits in the 1920-byte boot area. Receives firmware via standard DALI protocol, stages it in an external I2C EEPROM, validates device identity via Block 0, then copies to internal flash.

**~1876 / 1920 bytes (97.7%)** — compatible with standard DALI firmware update masters.

## How It Works

- 32-bit forward frame decoder at 1200 baud (IEC 62386-101, 7.4.3)
- Accepts IEC 62386-105 commands: START FW TRANSFER, BEGIN BLOCK, TRANSFER BLOCK DATA, FINISH FW UPDATE, RESTART FW, QUERY BLOCK FAULT, QUERY FW UPDATE RUNNING
- **Block 0 validation**: GTIN (6 bytes) and Device key byte 0 (EVG mode ID) are compared against values stored in EEPROM by the firmware. Mismatch → QUERY BLOCK FAULT returns YES → master aborts
- **Fletcher-16 integrity check**: Block 0 also carries a 2-byte Fletcher-16 of the firmware payload at positions `0x2C`/`0x2D`. The bootloader accumulates `fa`/`fb` over every received Block 1 firmware byte and compares against the expected value at FINISH. Mismatch → flash commit aborted, master sees BLOCK FAULT
- Block 1..n firmware data is extracted from the block structure (headers and trailing CRC skipped) and streamed to the I2C EEPROM staging area
- On FINISH FW UPDATE (if no fault): EEPROM contents are copied to internal flash, then device auto-reboots
- Other DALI devices on the bus are **not affected** — 32-bit frames are silently ignored per IEC 62386-101

## Speed

3 firmware bytes per 32-bit frame (vs 1 byte per 2 frames in the original bootloader). Expected transfer time for 10 KB firmware: **~2.5 minutes**.

## Boot Entry

Two ways to enter bootloader mode:

1. **Software**: Firmware receives START FW TRANSFER (32-bit, device-addressed), responds YES, sets `FLASH->STATR` bit 14 via the WCH `SystemReset_StartMode` sequence, and resets. The bootloader checks bit 14 on startup and enters update mode if set. Bit 14 is cleared immediately after reading (one-shot).
2. **Hardware**: Hold **PA1 low** during reset. The bootloader enters update mode and responds YES to any subsequent START FW TRANSFER from the master.

If neither condition is met, the bootloader jumps directly to user code.

**Note**: RAM magic words do NOT survive PFIC system reset on CH32V003. The `FLASH->STATR` bit 14 approach is used.

## Protocol

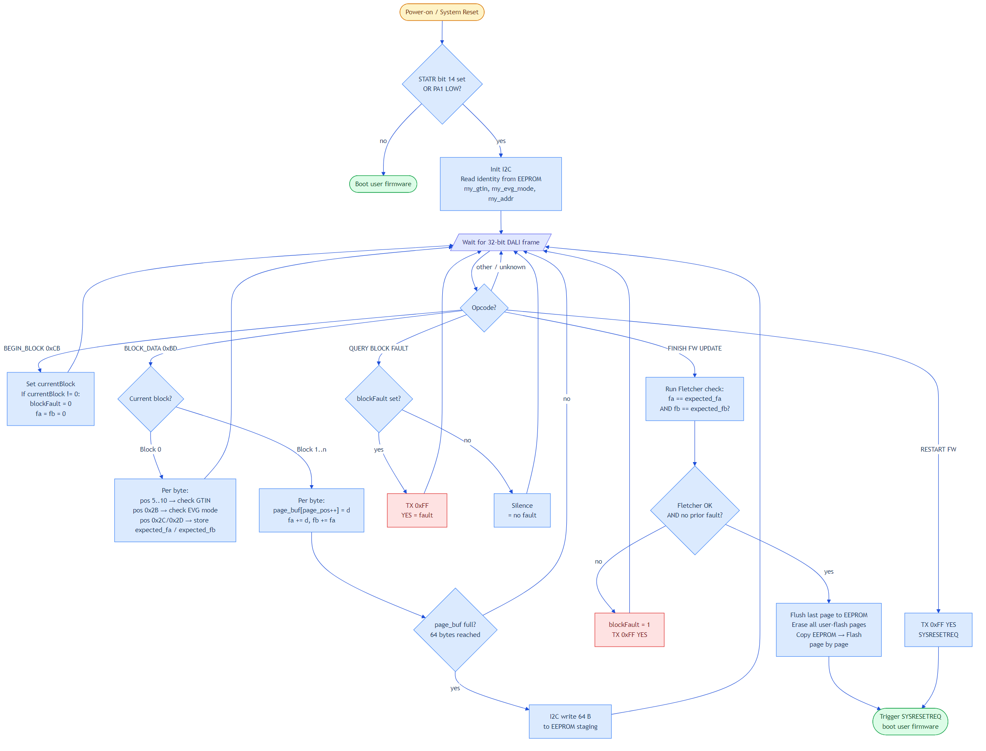
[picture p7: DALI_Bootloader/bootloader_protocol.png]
Bootloader Protocol


### Phase 1 — Enter Bootloader (handled by firmware)

| Frame | Direction | Description |
|---|---|---|
| `[addr] [0xFB] [0x05] [0x00]` | Master → Device | QUERY FW UPDATE FEATURES (firmware responds 0x00) |
| `[addr] [0xFB] [0x00] [0x00]` ×2 | Master → Device | START FW TRANSFER (config repeat) |
| `0xFF` | Device → Master | YES — firmware ACKs, then resets into bootloader |

### Phase 2 — Block 0 Validation (handled by bootloader)

| Frame | Direction | Description |
|---|---|---|
| `[0xCB] [0x00] [0x00] [0x00]` | Master → Bootloader | BEGIN BLOCK 0 (info block) |
| `[0xBD] [d0] [d1] [d2]` ×21 | Master → Bootloader | Block 0 data — GTIN at pos 5-10, Device key at pos 0x2B validated against EEPROM; Fletcher-16 expected stored from pos 0x2C/0x2D |
| `[0xBF] [0xFB] [0x08] [0x00]` | Master → Bootloader | QUERY BLOCK FAULT — silence = OK, YES = GTIN/mode mismatch |

### Phase 3 — Firmware Data Transfer

| Frame | Direction | Description |
|---|---|---|
| `[0xCB] [blk_h] [blk_m] [blk_l]` | Master → Bootloader | BEGIN BLOCK 1..n (resets `blockFault` and Fletcher accumulator) |
| `[0xBD] [d0] [d1] [d2]` | Master → Bootloader | TRANSFER BLOCK DATA — 3 firmware bytes per frame, no response. Each firmware byte feeds `fa += d; fb += fa;` |
| `[0xBF] [0xFB] [0x08] [0x00]` | Master → Bootloader | QUERY BLOCK FAULT — silence = no fault |

Block 1..n: bytes 0-1 = data size (s), bytes 2-14 = header (skipped), bytes 15..s+14 = firmware data (stored to EEPROM staging area at 0x0080+), bytes s+15..s+16 = trailing CRC (skipped, bootloader uses Fletcher-16 over the firmware payload instead).

### Phase 4 — Commit

| Frame | Direction | Description |
|---|---|---|
| `[0xBF] [0xFB] [0x03] [0x00]` ×2 | Master → Bootloader | FINISH FW UPDATE (config repeat) — bootloader compares accumulated `fa`/`fb` against expected. If both match and no prior fault: erases user-flash pages, copies EEPROM → flash, auto-reboots. Mismatch sets BLOCK FAULT and aborts. |
| `[addr] [0xFB] [0x01] [0x00]` | Master → Bootloader | RESTART FW (if needed) — responds YES, reboots |

## Firmware Storage Path

CH32V003 flash cannot be erased and written while code is executing from the same flash region. The bootloader sits in the boot area at `0x1FFFF000`, so it can write to user-flash at `0x08000000` — but the incoming firmware bytes have to be buffered somewhere while we're still receiving them. RAM is only 2 KB, far too small for a 10 KB firmware image. Solution: stage everything in the external **AT24C256 I2C EEPROM** (32 KB), then commit to user-flash in one pass at the end.

```mermaid
%%{init: {'theme': 'base', 'themeVariables': {
  'primaryColor': '#dbeafe', 'primaryTextColor': '#1e3a5f', 'primaryBorderColor': '#3b82f6',
  'lineColor': '#1d4ed8', 'fontSize': '14px'
}}}%%
flowchart LR
    M[DALI Master] -- "DALI<br/>3 B/frame" --> BL["Bootloader<br/>page_buf 64 B RAM"]
    BL -- "I2C write<br/>every 64 B" --> EE[("AT24C256<br/>EEPROM staging<br/>0x0080+")]
    EE -- "I2C read +<br/>flash write<br/>(on FINISH)" --> UF[("User Flash<br/>0x08000000")]
```

**Power-loss robustness.** Up until `FINISH FW UPDATE` succeeds and `copy_eeprom_to_flash()` starts erasing pages, user flash is untouched — losing power simply means the existing firmware boots normally on the next power cycle and the master can retry. The erase + copy phase is **not** atomic: a power loss during this window can leave user flash partially erased and the device unbootable, requiring re-flashing via WCH-Link. Master operations (sending Block 0 + Block 1 + final QUERY BLOCK FAULT) finish before any flash erase, so the at-risk window is limited to the final ~1-2 seconds of the update.

**Why Fletcher-16 instead of full CRC.** Fletcher fits in ~12 bytes of code (two `uint8_t` accumulators with rolling sum-of-sums) and matches CRC-16-CCITT in detection probability for the random-error and burst-error patterns seen on a DALI bus. Real CRC-16/32 with table-free implementation costs ~50-70 bytes — too expensive for the 1920-byte boot area when it has to coexist with the existing GTIN/mode validation, EEPROM driver, flash programming, and Manchester RX/TX.

## EEPROM Layout

The AT24C256 EEPROM serves as both persistent config storage and firmware staging area. Layout is shared between firmware and bootloader (defined in `Firmware/src/eeprom/eeprom_layout.h`).

```
AT24C256 (32 KB = 0x0000–0x7FFF)
├── 0x0000–0x003F  Device identity (64 B)
│   ├── 0x0000  magic (4 B, "DALI" = 0x44414C49)
│   ├── 0x0004  GTIN (6 B, MSB first)
│   ├── 0x000A  EVG mode ID (1 B)
│   ├── 0x000B  HW version major/minor (2 B)
│   ├── 0x000D  FW version major/minor (2 B)
│   └── 0x000F  short_address (1 B)
├── 0x0040–0x007F  DALI config (64 B, same struct as dali_nvm_t)
└── 0x0080–0x7FFF  Firmware staging area (32,640 B)
```

The identity block is written by the firmware at every boot. The bootloader reads it to:
1. Determine the device's DALI short address (for START FW TRANSFER addressing)
2. Validate Block 0 GTIN and Device key against the device's identity

## Pin Usage

| Pin | Function | Notes |
|-----|---|---|
| PC1 | I2C SDA | AT24C256 EEPROM |
| PC2 | I2C SCL | AT24C256 EEPROM |
| PC3 | DALI RX | Input, floating (from PHY RX_OUT) |
| PC4 | DALI TX | Output, push-pull (to PHY TX_IN) |
| PA1 | Boot button | Input, pull-up, active low at reset |

## Prerequisites

The CH32V003 option bytes must be configured to boot from the bootloader area. Flash `configurebootloader.bin` once per chip using a WCH-LinkE programmer:

```
wlink flash configurebootloader.bin
```

## Testing & End-to-End Verification

The full chain — KNX bus → Gateway → DALI bus → bootloader → I2C EEPROM staging → user-flash commit → reboot — can be exercised and verified independently.

Brief recipe of the actual run that proved every step:

 - Pushed the new `firmware.bin` over DALI. The Uploader computes Fletcher-16 once on the host and embeds it in Block 0, then transfers ~3 600 BLOCK_DATA frames in ~3 minutes. Mid-transfer health-check via QUERY BLOCK FAULT every 500 frames.
 - Flashed Firmware came online.
 - Dumped AT24C256 over UART, checked against the FW-Binary byte-for-byte. All 10 772 firmware bytes matched, trailing region clean.

### Driving an update from a host PC

The Host-Updater Application implements the full IEC 62386-105 sequence and pushes a `firmware.bin` over the gateway WebSocket API:

1. Pre-computes Fletcher-16 over the firmware payload and embeds it in Block 0 at positions `0x2C`/`0x2D`
2. Sends START FW TRANSFER → Block 0 (with GTIN, mode, Fletcher-expected) → Block 1 firmware bytes → FINISH
3. **Polls QUERY BLOCK FAULT every 500 frames** during Phase C — if the bootloader reports a fault mid-transfer, the script aborts early instead of pumping bytes into a doomed transfer

After a successful run, the device auto-reboots into the new firmware.

## Build

Requires PlatformIO's RISC-V toolchain (`riscv-wch-elf-gcc`). All dependencies (`ch32v003fun.h`, `libgcc.a`) are included in the `ch32v003fun/` subfolder.

Double-click `build.bat` or run from command line.

## Flash

```
wlink flash --address 0x1FFFF000 dali_bootloader.bin
```

## Resource Usage

| Resource | Value |
|---|---|
| Flash | 1,908 B / 1,920 B (99.4%) |
| RAM | ~150 B (stack + variables) |
| I2C | I2C1, 100 kHz, AT24C256 at address 0x50 |

## Important: TX Polarity (PHY Mode)

With a DALI PHY transceiver: **TX HIGH = bus active (mark), TX LOW = bus idle (space)**. The bootloader must initialize PC4 to LOW (idle) and use the correct Manchester encoding:
- `tx_active()` = GPIO HIGH = PHY pulls bus to 0V
- `tx_idle()` = GPIO LOW = PHY releases bus

The firmware's `dali_phy.c` uses the same convention (`BSHR` = active, `BCR` = idle).

## Files

| File | Description |
|---|---|
| `dali_bootloader.c` | Main bootloader source |
| `startup.S` | Minimal startup (vector table, stack init, BSS zero) |
| `funconfig.h` | ch32v003fun config |
| `build.bat` | Build script using PlatformIO toolchain |
| `bootloader.ld` | Linker script (boot area: 0x00000000, 1920 bytes) |
| `ch32v003fun/` | Dependencies: `ch32v003fun.h` + `libgcc.a` |
| `dali_bootloader.bin` | Pre-built binary (~1876 bytes) |
| `configurebootloader.bin` | Option bytes configurator (run once per chip) |
| `flash.bat` | Flash bootloader to boot area via WCH-LinkE |
| `bootloader_protocol.mmd` | Protocol sequence diagram (Mermaid source) |
| `bootloader_protocol.png` | Rendered protocol diagram |

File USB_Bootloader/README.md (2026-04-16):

# USB Bootloader

> **WARNING: Do NOT connect USB while the EVG is connected to a DALI bus or mains power.**
> The USB data lines share GPIO pins with the microcontroller and are not galvanically isolated.
> Only use USB for firmware updates on a standalone board that is not integrated into a system.
> Connecting USB while the EVG is on a DALI bus risks damage to both the USB host and the EVG.

USB HID bootloader for the CH32V003, based on [cnlohr's ch32v003fun-usb-bootloader](https://github.com/cnlohr/ch32v003fun/tree/master/bootloader). Allows firmware updates over USB without a dedicated programmer after initial setup.

The bootloader source (`src/`) is not included in this repository. Clone it from cnlohr's repo if you need to rebuild.

## Pin Configuration

| Function | Pin | Notes |
|---|-----|---|
| USB D+ | PD4 | |
| USB D- | PD2 | |
| USB D+ Pull-Up (DPU) | PD0 | Directly driven by bootloader |
| Boot Button | PA1 | Pull low during reset to enter bootloader |

## Boot Behaviour

- On power-up, the chip enters the bootloader (option bytes set to boot-from-bootloader)
- If the boot button (PA1) is **not** held low, the bootloader immediately jumps to user code
- If the boot button **is** held low, the bootloader stays active and enumerates as USB HID device (`VID:1209 PID:B003`)

## Initial Setup (requires WCH-LinkE programmer)

This only needs to be done once per chip.

1. Connect the WCH-LinkE programmer
2. Run `flash.bat`

This flashes two things in sequence:
1. **configurebootloader.bin** — a small program that sets the option bytes to boot-from-bootloader mode, then halts
2. **bootloader.bin** — the actual USB bootloader, written to the 1920-byte boot area at `0x1FFFF000`

## Rebuilding (optional)

Build with `src/bootloader/make_win.bat`. The key configuration:

<bootloader.c>
```
#define DISABLE_BOOTLOAD

#define BOOTLOADER_BTN_PORT A
#define BOOTLOADER_BTN_PIN 1
#define BOOTLOADER_BTN_TRIG_LEVEL 0

#define BOOTLOADER_TIMEOUT_PWR 0
```

<usb_config.h>
```
#define USB_PORT D
#define USB_PIN_DP 4
#define USB_PIN_DM 2

#define USB_PIN_DPU 0
```

Size: 1908 / 1920 bytes (99.38%).

## Flashing User Firmware via USB

After the bootloader is installed, firmware updates no longer require a programmer:

1. Hold the boot button and power-cycle (or reset) the device
2. The device enumerates as USB HID
3. Flash using [minichlink](https://github.com/cnlohr/ch32v003fun/tree/master/minichlink): `minichlink -w firmware.bin flash`

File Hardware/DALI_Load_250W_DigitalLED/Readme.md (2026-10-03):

# LoadBoard 250W Digital LED



Addressable-LED driver and AC power switching board for WS2812 / SK6812 strips. Connects to the Controller via a 10-pin FFC cable (0.5 mm pitch, 25-50 mm, reverse) and provides:
- Mains switching for controlling the LED AC/DC power supply
- Power limits for the connected PSU: **max 1.2 A continuous** (without airflow), **max 3 A continuous** (with active airflow over the triac)
- One galvanically isolated single-wire data output
- **Strip supply 5 V … 24 V**, passed through from the PSU

Same AC stage as the [LoadBoard 250W RGBW](../DALI_Load_250W_RGBW/Readme.md). Firmware side: `EVG_MODE_WS2812`, `EVG_MODE_SK6812_RGB` or `EVG_MODE_SK6812_RGBW`.

## Controller signals

**Only `PWM_CH1` carries payload** — it is the single-wire data line (`PWM_CH1/D_LED/MOSI`, J4 pin 10, Controller PC6). Apart from that the board taps just `GND` (pin 1), `+3V3-PRI` (pin 2, supplies the isolator's input side) and `PSU-CTRL` (pin 6, switches the mains stage).

The remaining six — `SCK`, `SDA`, `SCL` and `PWM_CH2` … `PWM_CH4` — reach the connector but are left unconnected on this board. They stay available for a future revision.

## Connectors

| Ref | Type | Function |
|-----|---|---|
| J1 | FFC 0.5 mm, 10-pin | Controller interface (Controller J4). `+3V3-PRI` here is the Controller's `+3V3-D`; `GND` is common to both. |
| P1 | KF142R-5.08, 4-pin | Mains in / switched mains out to the LED PSU |
| P7 | 1x4 header | DC input from the LED PSU (`PSU+` / `GND-SEC`) |
| P2 | KF2EDGR-3.81, 3-pin | LED strip: `PSU+`, `DATA`, `GND-SEC` |

> **⚠ Mains safety:** only screw this board into the enclosure with the housing part in place — the screw head must rest on plastic, never directly on the PCB. See [Enclosure](../README.md#enclosure).

## Top label

Print [`DALI_LOAD_DigitalLED_V0.1-TopLabel.png`](DALI_LOAD_DigitalLED_V0.1-TopLabel.png) at 100 %, cut on the marks and clamp the 40 x 24 mm plate under the four M2.5 screws on the enclosure top — the hole pattern is 33.15 x 17 mm.

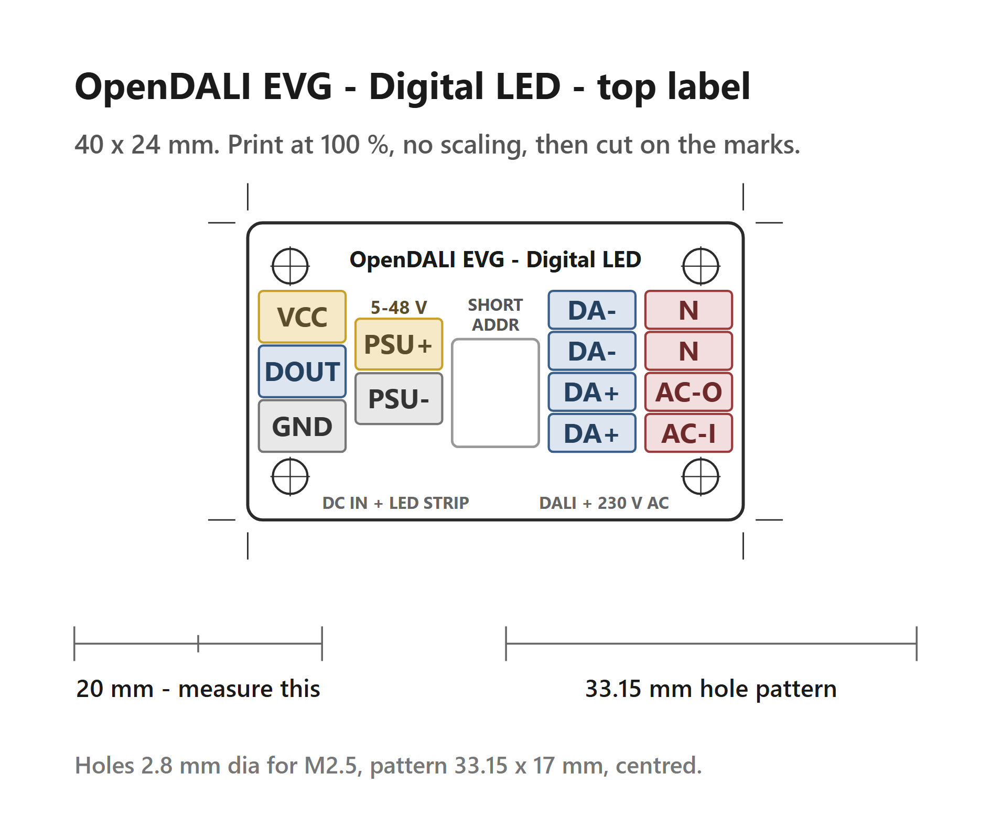
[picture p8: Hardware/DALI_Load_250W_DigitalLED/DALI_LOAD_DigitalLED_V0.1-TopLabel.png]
Top label


## Strip supply

> ## `PSU+` = 5 V … 24 V
>
> `PSU+` is passed straight through from P7 to the strip connector, so **the strip runs at the PSU voltage — pick the PSU to match the strip.**

A local buck (ME3116) derives the 5 V that supplies the isolator's output side. It
still starts at `PSU+` = 5 V and delivers 4.44 V there — above the 3.5 V the strip
needs on its data line, so the whole input range is covered without an assembly
variant.

## Isolation

The data line crosses the barrier through a π110M30 single-channel digital isolator (3 kVrms) — input side powered from the controller's 3.3 V rail, output side from the local 5 V. Neither I²C nor a reverse channel crosses the barrier.

With the LED PSU off, the isolator's output side is unpowered and its output goes high-impedance. The π110M30 is the **Default Low** variant, so an absent input drives the strip line low (strip idle) rather than high.

An isolated 5 V rail (B0505S) is fed back from the LED side to the bus side, taking the opto-triac's LED current off the DALI bus in steady state.

> **⚠ Not fully IEC 62386 compliant:** as on the RGBW board, the bus draw briefly exceeds the 2 mA budget during each off→on transition, until the feedback rail takes over.

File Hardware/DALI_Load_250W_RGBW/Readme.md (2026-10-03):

# LoadBoard 250W RGBW

LED driver and AC power switching board. Connects to the Controller via a 10-pin FFC cable (0.5 mm pitch, 25-50 mm, reverse) and provides:
- Mains switching for controlling the LED AC/DC Powersupply
- Power limits for the connected PSU: **max 1.2 A continuous** (without airflow), **max 3 A continuous** (with active airflow over the triac)
- 4-Channel PWM LED Driver (RGBW)

> **⚠ Work in progress.** This board is still under development.
>
> **MOC gate-drive supply — solved via power-ORing + power-feedback:** the MOC is bootstrapped from the DALI bus at turn-on, then taken over by an isolated 5 V rail fed back from the LED-side supply (B0505S) once the PSU is up → the bus is offloaded in steady state.
>
> **⚠ Not fully IEC 62386 compliant:** during the off→on transition the bus draw briefly exceeds the 2 mA budget (~4.1 mA) until the feedback rail takes over. Transient only, at each turn-on.

> **⚠ Mains safety:** only screw this board into the enclosure with the housing part in place — the screw head must rest on plastic, never directly on the PCB. See [Enclosure](../README.md#enclosure).

## Top label

Print [`DALI_Load_250W_RGBW_V0.3-TopLabel.png`](DALI_Load_250W_RGBW_V0.3-TopLabel.png) at 100 %, cut on the marks and clamp the 40 x 24 mm plate under the four M2.5 screws on the enclosure top — the hole pattern is 33.15 x 17 mm.

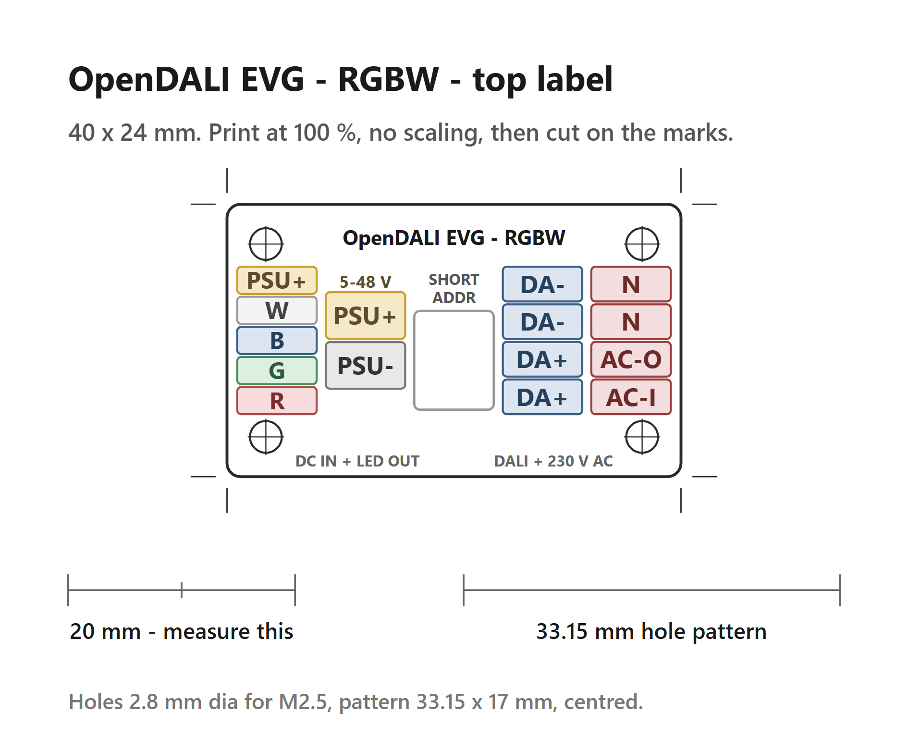
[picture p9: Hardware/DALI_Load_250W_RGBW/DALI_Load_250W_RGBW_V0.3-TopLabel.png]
Top label


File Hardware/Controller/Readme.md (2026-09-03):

# Controller



 

The DALI PHY and microcontroller board. Handles all DALI-bus communication (IEC 62386-101/102 compatible), protocol processing, and generates the digital PWM/LED control signals. Built around the CH32V003F4U6 RISC-V microcontroller (20-pin QFN, 48 MHz, 16 KB Flash, 2 KB RAM).

The PHY transceiver converts between the DALI bus voltage levels (0/16V) and the MCU's 3.3V logic. See [`Simulations/`](../../Simulations/) for LTspice reference designs (isolated and non-isolated variants).

## Pin Assignment, CH32V003F4U6

| Pin | Function | Direction | Peripheral | Notes |
|-----|---|---|---|---|
| PA1 | Boot button | Input | GPIO | Active low at reset → enter DALI bootloader (also routed through firmware's `boot_button_check()` on NRST/SYSRESETREQ) |
| PA2 | PSU Control | Output | GPIO | HIGH = external PSU on, LOW = off |
| PC0 | LED3 / Blue PWM | Output | TIM1_CH3 | 20 kHz, 2400-step (11.2 bit) |
| PC1 | I2C SDA | Bidir | I2C1 | AT24C256C EEPROM (persistence + firmware staging) |
| PC2 | I2C SCL | Output | I2C1 | AT24C256C EEPROM |
| PC3 | DALI RX | Input | EXTI3 | From PHY RX_OUT, both-edge interrupt |
| PC4 | DALI TX | Output | GPIO | To PHY TX_IN, Manchester encode |
| PC5 | SPI1 SCK → J4.3 | Output | SPI1 | SPI clock to the load board (ribbon J4 pin 3). Idle/unused in direct-PWM LED modes; driven only when a digital (SPI) load board is used. *(Was previously documented as "spare" — it is physically routed to the connector.)* |
| PC6 | LED1 / Red PWM **or** WS2812 data | Output | TIM1_CH1 / SPI1_MOSI | Dual-use: PWM in analog modes, SPI+DMA in digital LED modes |
| PC7 | LED2 / Green PWM | Output | TIM1_CH2 | 20 kHz, 2400-step (11.2 bit) |
| PD0 | *(spare)* | — | — | Free GPIO |
| PD1 | SWDIO | Bidir | SWD | Single-wire debug (active during programming) |
| PD2 | *(spare)* | — | — | Free GPIO |
| PD3 | LED4 / White PWM | Output | TIM1_CH4 | 20 kHz, 2400-step (11.2 bit) |
| PD4 | *(spare)* | — | — | Free GPIO |
| PD5 | Debug UART TX | Output | USART1_TX | 115200 baud, via WCH-LinkE bridge |
| PD6 | Debug UART RX | Input | USART1_RX | 115200 baud, available for debug input |
| PD7 | NRST | Input | Reset | Active low hardware reset |

**Digital LED output** (WS2812/SK6812 modes): SPI1_MOSI on PC6 at 3 MHz, DMA-driven. Same physical pin as TIM1_CH1 — selected at compile time via `EVG_MODE_xxx`.

> **⚠ Galvanic isolation is MANDATORY.** AC-mains switching of the 250 W load board was tested on real hardware: the LED-power domain **must be galvanically isolated** from the DALI/MCU domain. The isolation barrier lives on the **load board**. The J4 ribbon connector is the controller↔load-board interface that feeds the isolator's input side.

## J4 — Load-board interface (10-pin FFC, 0.5 mm pitch)

Pins 9 and 10 are dual-function (PWM **or** SPI), selected by the controller's `EVG_MODE` at compile time — so the same connector drives either a direct-PWM load board or a digital (SPI) load board with no controller hardware change:

| Pin | Net | MCU pin | Function |
|-----|-----|---|---|
| 1 | `GND` | — | Controller-domain ground (DALI/MCU side; isolated from LED domain on the load board) |
| 2 | `+3V3-D` | — | 3.3 V controller-domain supply (feeds the isolator input side VCC1 in Route A) |
| 3 | `SCK` | PC5 | SPI1 clock (digital load board) |
| 4 | `SDA` | PC1 | I²C data (shared EEPROM bus; load-board diagnostics option) |
| 5 | `SCL` | PC2 | I²C clock |
| 6 | `PSU-CTRL` | PA2 | LED AC/DC PSU enable — HIGH = on (also used as AUX-MCU power-cycle / bootloader entry in Route B) |
| 7 | `PWM_CH4` | PD3 | White PWM (free in SPI mode) |
| 8 | `PWM_CH3` | PC0 | Blue PWM (free in SPI mode) |
| 9 | `PWM_CH2 / MISO` | PC7 | Green PWM **or** SPI MISO (load-board → controller, e.g. diagnostics) |
| 10 | `PWM_CH1 / D_LED / MOSI` | PC6 | Red PWM **or** WS2812/SK6812 data **or** SPI MOSI |
| M ×2 | `GND` | — | Connector mounting / shield tabs |

The connector is deliberately over-provisioned, because **one controller is meant to serve many generations of load board.** Each load board taps only the signals it needs, and the firmware selects the matching mode at compile time via `EVG_MODE` — so adopting a new load-board design is a recompile, not a controller respin. Power (`+3V3-D`, `GND`) and the `PSU-CTRL` enable line are always present; what varies from board to board is *how the colour and level data is actuated.*

**I²C (`SDA`/`SCL`) is always routed**, shared with the controller's on-board EEPROM bus. It is held in reserve for a future diagnostic/measurement channel (LED current, temperature, fault feedback) or an I²C PWM/LED expander.

> ⚠ **One caveat on isolating I²C.** I²C is *bidirectional*, so taking it across the galvanic barrier requires a bidirectional I²C isolator — those are typically mA class parts which might crash the 2mA current budget.

For the actuation itself, each load board picks **one** of three paths:

1. **Direct PWM** — the four 20 kHz channels (CH1…CH4) drive the load-side gate drivers straight through the isolator. The simplest option, but it needs a fast enough isolator so that even the shortest dimming pulses survive the barrier intact. Tested is the π160M30 from 2Pai-Semi. Implemented by the [LoadBoard 250W RGBW](../DALI_Load_250W_RGBW/Readme.md).
2. **Addressable LED (WS2812 / SK6812)** — a single-wire data stream on the CH1/MOSI pin, generated by SPI1 + DMA. Implemented by the [LoadBoard 250W Digital LED](../DALI_Load_250W_DigitalLED/Readme.md).
3. **SPI to a load-side companion MCU** — the unidirectional SPI lines isolate cleanly with a cheap **µA** digital isolator. A second MCU on the load board, powered locally from the LED PSU, acts as an **SPI slave**: it receives colour/level commands and handles everything downstream itself — optional diagnostics returned over MISO. A slow and inexpensive isolator suffices, and the bus-side channel count stays minimal.

*Example SPI mapping* — a 6-channel isolator (e.g. 2Pai π161U3x, 5 forward + 1 reverse), reusing the otherwise-PWM pins:

| Dir | Signal | J4 | MCU |
|-----|---|----|-----|
| → | MOSI | 10 | PC6 |
| → | SCK | 3 | PC5 |
| → | NCS | 8 | PC0 |
| → | PSU-CTRL | 6 | PA2 |
| → | BL-Enable | 7 | PD3 |
| ← | MISO | 9 | PC7 |

> Note: the π161U3x (U-Grade) limits the SPI-Speed to 150kHz. In case of availability issues the higher grades (M/E) are also OK. 

**Firmware updates** happen over the DALI bus itself via the IEC 62386-105 bootloader at `0x1FFFF000`. PA1 held low at reset routes into the bootloader (works for POR, NRST, and SYSRESETREQ thanks to the firmware-side `boot_button_check()`). PD1 (SWDIO) is the recovery path via WCH-LinkE for chips that have lost their flash content entirely.

## Hardware Validation

| Test | Target | Result | Evidence |
|---|---|---|---|
| DALI RX Manchester waveform | Clean edges, correct timing | **PASS** — 3.7V swing, sharp edges, correct 1200 baud timing | See below |
| C24 voltage under sustained DALI traffic | > 12.5V | **PASS** — 14.40V min / 14.84V max (0.44V drop at 16V supply, 32 fps) | See below |
| 3.3V rail stability under sustained traffic | Stable within CH32V003 spec (2.7–5.5V) | **PASS** — 3.42V min / 3.63V max (20mV additional ripple = noise only) | See below |
| Current consumption (firmware running) | < 2 mA | **PASS** — 1.69 mA (169mV over 100R shunt) | — |

**Note**: Waveform-Images are from an LeCroy LT264 with a custom visualisation. You looking at real measured waveforms.

##### DALI RX Waveform

Oscilloscope capture of the raw Manchester-encoded signal on PC3 (DALI RX, via PHY transceiver). C1 is the raw 16V DALI Signal, C2 is the signal after the receiver on PC3.
lecroy-2026-05-22T19-55-04

##### C24 Voltage Stability

Voltage across C24 (DALI bus power supply decoupling) while rapidly sending DALI commands over an extended period. The voltage must remain above **12.5V** to ensure the circuit works at the lowest allowed DALI bus voltage (9.5V).

**Calculation:** The DC-DC converter requires a minimum of 5V input. The bridge rectifier drops ~1V (2 diodes). So C24 must stay above 6V for the converter to regulate. At the minimum DALI bus voltage of 9.5V, this allows a maximum voltage drop of 3.5V (9.5V - 6V). Our test supply runs at 16V, so the equivalent pass/fail threshold is 16V - 3.5V = **12.5V**. If C24 stays above 12.5V at 16V supply, it will stay above 6V at 9.5V supply. Note: this is a linear approximation — actual energy stored in C24 scales with V², so the real margin at 9.5V will be slightly worse. Best estimate for now until tested at actual minimum bus voltage.

**Measurement procedure:** DALI EVG firmware (RGBW mode) running on the target. An OpenKNX DALI gateway sent continuous broadcast QUERY GEAR PRESENT (0xFF 0x91) frames at maximum bus rate (~32 frames/sec, 25ms spacing per IEC 62386-101) for 5 seconds (~160 frames total). Oscilloscope probe on C24, DC coupling, 2V/div, 50ms/div timebase, min/max measurement enabled.

**Result (2026-05-02):**
- Bus supply voltage: 16V
- Maximum at C24: **15.4V**
- Minimum at C24: **14.8V**
- Voltage drop: **0.6V** (well within 3.5V budget)
- **PASS** — extrapolated minimum at 9.5V bus: ~8.9V (above 6V threshold)

**3.3V rail (after buck converter):**
- No traffic: 3.63V max / 3.44V min
- Under sustained traffic (32 fps): 3.63V max / 3.42V min
- **Stable** — only 20mV additional ripple under load. CH32V003 operating range is 2.7–5.5V, so 3.42V is well within spec.

Note: All Channels have different V/div settings.<br>
C1: DALI bus, you can see sustained heavy traffic. C2: Voltage at Capacitor C24 (before the Buck). C3:. Voltage at 3.3V Rail after the Buck.
lecroy-2026-05-22T20-21-50

### Current Consumption

Total current draw of the Controller board with firmware running. Target: < 2 mA to stay within DALI bus power limits.

**Measurement (2026-05-02):** 100R shunt resistor in series with the supply. DALI EVG firmware (RGBW mode) running, bus idle, Bus Voltage 16V. Measured 169mV across the shunt → **1.69 mA**. Well within the 2 mA DALI bus power budget.

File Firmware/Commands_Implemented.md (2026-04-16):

# DALI Commands Implemented

DALI-2 control gear firmware for CH32V003F4U6 (ch32fun framework).
Implements IEC 62386-101, IEC 62386-102, and IEC 62386-209 (DT8).

## IEC 62386-101 — Physical Layer

| Feature | Status | Notes |
|---|---|---|
| Manchester encoding 1200 baud | Done | Te = 417 us, +/-30% acceptance window |
| Forward frame RX (16-bit) | Done | EXTI both-edge + TIM2 timestamping |
| Backward frame TX (8-bit) | Done | TIM2 output compare, settle 7-22 Te |
| Noise filter | Done | Edges < 200 us ignored |
| Idle timeout (frame complete) | Done | 5 Te, TIM2 CH4 output compare |
| PHY mode (default) | Done | Normal polarity for DALI transceiver (TX: HIGH=active, RX: HIGH=active) |
| DALI_NO_PHY mode | Done | Direct GPIO, inverted polarity (TX: LOW=active, RX: LOW=active). Optional, disabled by default. |
| Bus collision detection (TX echo check) | Done | TX ISR samples bus each Te via PHY readback, aborts on mismatch within 1 Te. Collision logged via `printf("COLLISION")` and flag readable via `dali_tx_consume_collision()`. Requires PHY (open-drain bus). |
| Structured frame type | Done | `dali_frame_t { data, size, flags, timestamp }` with FORWARD / BACKWARD / ERROR / COLLISION / ECHO flags (`dali_frame.h`) |

## IEC 62386-102 — Immediate Action Commands (0-15)

| Cmd | Name | Status | Notes |
|-----|---|---|---|
| 0 | OFF | Done | Instant to level 0, cancels fade |
| 1 | UP | Done | Fade up at fadeRate to maxLevel |
| 2 | DOWN | Done | Fade down at fadeRate to minLevel |
| 3 | STEP UP | Done | +1 level instant, 0 -> minLevel |
| 4 | STEP DOWN | Done | -1 level instant, minLevel -> 0 |
| 5 | RECALL MAX LEVEL | Done | Instant to maxLevel |
| 6 | RECALL MIN LEVEL | Done | Instant to minLevel |
| 7 | STEP DOWN AND OFF | Done | Step down, OFF at minLevel |
| 8 | ON AND STEP UP | Done | If OFF -> minLevel, else step up |
| 9 | ENABLE DAPC SEQUENCE | -- | Not implemented (rarely used) |
| 10-15 | Reserved | -- | |

## IEC 62386-102 — Scene Commands (16-31)

| Cmd | Name | Status | Notes |
|-----|---|---|---|
| 16-31 | GO TO SCENE 0-15 | Done | Recall with fadeTime, MASK ignored |

## IEC 62386-102 — Configuration Commands (32-128)

All config commands require config repeat (2x within 100 ms).

| Cmd | Name | Status | Notes |
|-----|---|---|---|
| 32 | RESET | Done | Restore Table 22 defaults, preserves short addr |
| 33 | STORE ACTUAL LEVEL IN DTR0 | Done | dtr0 = actualLevel |
| 34-41 | Reserved | -- | |
| 42 | STORE DTR AS MAX LEVEL | Done | Persisted to flash |
| 43 | STORE DTR AS MIN LEVEL | Done | Clamped to [1, maxLevel] (dimming) or forced 254 (ONOFF) |
| 44 | STORE DTR AS POWER ON LEVEL | Done | Applied at boot |
| 45 | STORE DTR AS SYSTEM FAILURE LEVEL | Done | Persisted to flash |
| 46 | STORE DTR AS FADE TIME | Done | Lower 4 bits, 0-15 |
| 47 | STORE DTR AS FADE RATE | Done | Lower 4 bits, 1-15 (0 reserved) |
| 48 | STORE DTR AS SHORT ADDRESS | Done | DTR0 = (addr<<1)\|1, or 0xFF to delete |
| 49-63 | Reserved | -- | |
| 64-79 | STORE DTR AS SCENE 0-15 | Done | Persisted to flash |
| 80-95 | REMOVE FROM SCENE 0-15 | Done | Sets scene to MASK (0xFF) |
| 96-111 | ADD TO GROUP 0-15 | Done | 16-bit membership bitmask |
| 112-127 | REMOVE FROM GROUP 0-15 | Done | |
| 128 | STORE DTR AS EXTENDED FADE TIME | Done | Bits [3:0]=base, [6:4]=mult, >0x4F resets to 0. Persisted. |

## IEC 62386-102 — Query Commands (144-199)

| Cmd | Name | Status | Response |
|-----|---|---|---|
| 144 | QUERY STATUS | Done | Status byte (see below) |
| 145 | QUERY CONTROL GEAR PRESENT | Done | Always YES (0xFF) |
| 146 | QUERY LAMP FAILURE | Done | No response (no HW monitoring) |
| 147 | QUERY LAMP POWER ON | Done | YES if actualLevel > 0 |
| 148 | QUERY LIMIT ERROR | Done | No response (no limit errors) |
| 149 | QUERY RESET STATE | Done | YES if all vars at defaults |
| 150 | QUERY MISSING SHORT ADDRESS | Done | YES if addr = 0xFF |
| 151 | QUERY VERSION NUMBER | Done | Returns 1 (DALI-1) |
| 152 | QUERY CONTENT DTR0 | Done | Returns DTR0 |
| 153 | QUERY DEVICE TYPE | Done | Returns 6 (DT6) or 8 (DT8), depending on EVG mode |
| 154 | QUERY PHYSICAL MINIMUM | Done | Returns 1 (dimming modes) or 254 (ONOFF mode) |
| 155 | QUERY CONTENT DTR1 | Done | Returns DTR1 |
| 156 | QUERY CONTENT DTR2 | Done | Returns DTR2 |
| 157 | QUERY POWER FAILURE | -- | DALI-2 only |
| 158-159 | Reserved | -- | |
| 160 | QUERY ACTUAL LEVEL | Done | 0-254 |
| 161 | QUERY MAX LEVEL | Done | |
| 162 | QUERY MIN LEVEL | Done | |
| 163 | QUERY POWER ON LEVEL | Done | |
| 164 | QUERY SYSTEM FAILURE LEVEL | Done | |
| 165 | QUERY FADE TIME / FADE RATE | Done | (fadeTime<<4) \| fadeRate |
| 166 | QUERY POSSIBLE OPERATING MODES | -- | DALI-2 diagnostic |
| 167 | QUERY FEATURES | -- | DALI-2 diagnostic |
| 168 | QUERY FAILURE STATUS | -- | DALI-2 diagnostic |
| 169 | QUERY SHORT CIRCUIT | -- | DALI-2 diagnostic |
| 170 | QUERY OPEN CIRCUIT | -- | DALI-2 diagnostic |
| 171 | QUERY LOAD DECREASE | -- | DALI-2 diagnostic |
| 172 | QUERY LOAD INCREASE | -- | DALI-2 diagnostic |
| 173 | QUERY INSULATION FAULT | -- | DALI-2 diagnostic |
| 174 | QUERY OUTPUT POWER ON | -- | DALI-2 diagnostic |
| 175 | QUERY THERMAL SHUTDOWN | -- | DALI-2 diagnostic |
| 176-191 | QUERY SCENE LEVEL 0-15 | Done | 0-254, 0xFF = MASK |
| 192-193 | Reserved | -- | |
| 194 | QUERY RANDOM ADDRESS H | Done | |
| 195 | QUERY RANDOM ADDRESS M | Done | |
| 196 | QUERY RANDOM ADDRESS L | Done | |
| 197 | READ MEMORY LOCATION | Done | Reads bank0[DTR1] when DTR2=0; mirrors value into DTR0; post-increments DTR1. Out-of-range / wrong bank: silent. |
| 198 | QUERY GROUPS 0-7 | Done | Bitmask |
| 199 | QUERY GROUPS 8-15 | Done | Bitmask |

### QUERY STATUS Byte (cmd 144)

| Bit | Name | Status | Description |
|-----|---|---|---|
| 0 | controlGearFailure | Always 0 | No HW fault monitoring |
| 1 | lampFailure | Always 0 | No HW lamp monitoring |
| 2 | lampOn | Done | 1 if actualLevel > 0 |
| 3 | limitError | Always 0 | Not tracked |
| 4 | fadeRunning | Done | 1 if fade in progress |
| 5 | resetState | Done | 1 after RESET, cleared on config change |
| 6 | missingShortAddress | Done | 1 if short_address = 0xFF |
| 7 | powerCycleSeen | Done | 1 after power-on, cleared by RESET |

## IEC 62386-102 — Special Commands

| Addr Byte | Name | Status | Notes |
|---|---|---|---|
| 0xA1 | TERMINATE | Done | Leave initialisation state |
| 0xA3 | DATA TRANSFER REGISTER (DTR0) | Done | Set DTR0 |
| 0xA5 | INITIALISE | Done | Config repeat, 15-min timeout |
| 0xA7 | RANDOMISE | Done | Config repeat, LCG from SysTick |
| 0xA9 | COMPARE | Done | random <= search -> YES |
| 0xAB | WITHDRAW | Done | random == search -> withdraw |
| 0xB1 | SEARCHADDRH | Done | Set search address high byte |
| 0xB3 | SEARCHADDRM | Done | Set search address mid byte |
| 0xB5 | SEARCHADDRL | Done | Set search address low byte |
| 0xB7 | PROGRAM SHORT ADDRESS | Done | Assign addr during init |
| 0xB9 | VERIFY SHORT ADDRESS | Done | YES if addr matches |
| 0xBB | QUERY SHORT ADDRESS | Done | Returns addr if random==search |
| 0xC1 | ENABLE DEVICE TYPE | Done | Consumed by next command |
| 0xC3 | DTR1 | Done | Set DTR1 |
| 0xC5 | DTR2 | Done | Set DTR2 |

## IEC 62386-102 — Addressing

| Mode | Status | Notes |
|---|---|---|
| Short address (0AAAAAA S) | Done | 0-63 |
| Group address (100GGGG S) | Done | 16 groups, bitmask |
| Broadcast (1111111 S) | Done | 0xFE arc, 0xFF command |
| MASK handling (0xFF) | Done | No action on arc power 0xFF |

## IEC 62386-102 — Protocol Features

| Feature | Status | Notes |
|---|---|---|
| Config repeat (100 ms window) | Done | Commands 32-128, INITIALISE, RANDOMISE |
| 15-minute initialisation timeout | Done | |
| Min/max level clamping | Done | All arc power paths |
| Logarithmic dimming curve | Done | IEC 62386-102 Table 16, 254-entry LUT |
| Fade engine (fadeTime) | Done | Arc power + scenes |
| Fade engine (fadeRate) | Done | UP/DOWN commands |
| Power-on level | Done | Applied from NVM at boot |
| Flash persistence (NVM) | Done | All config survives power cycle |
| DT8 colour persistence | Done | RGBW + Tc persisted in NVM |
| Deferred NVM write | Done | 5-second dirty timer |

## IEC 62386-209 — DT8 Colour Control

| Cmd | Name | Status | Notes |
|-----|---|---|---|
| 226 | ACTIVATE | Done | Commit temp colour -> actual, persisted |
| 231 | SET TEMPORARY COLOUR TEMPERATURE | Done | Mirek from DTR1:DTR0 |
| 232 | STEP COOLER | Done | -10 mirek (toward 6500K) |
| 233 | STEP WARMER | Done | +10 mirek (toward 2700K) |
| 235 | SET TEMPORARY RGB LEVEL | Done | R=DTR2, G=DTR1, B=DTR0 |
| 236 | SET TEMPORARY WAF LEVEL | Done | W=DTR2 (A, F ignored) |
| 238 | COPY REPORT TO TEMPORARY | Done | Copy actual -> temp |

### DT8 Query Commands

| Cmd | Name | Status | Response |
|-----|---|---|---|
| 247 | QUERY GEAR FEATURES | Done | 0x00 (no special features) |
| 248 | QUERY COLOUR STATUS | Done | Tc/RGBWAF active bits |
| 249 | QUERY COLOUR TYPE FEATURES | Done | Tc + Primary supported |
| 250 | QUERY COLOUR VALUE | Done | DTR0-dependent |
| 251 | QUERY RGBWAF CONTROL | Done | Active channel bitmask |
| 252 | QUERY ASSIGNED COLOUR | Done | 0xFF |

### DT8 Features

| Feature | Status | Notes |
|---|---|---|
| RGBW output (4 channels) | Done | TIM1 CH1-CH4 PWM |
| Tc -> RGBW conversion | Done | Linear interpolation 2700K-6500K |
| CIE xy chromaticity | -- | Requires spectral calibration |
| Tc limits (STORE/QUERY) | -- | Not implemented |
| Auto-calibration | -- | Not implemented |
| DT6 backward compatibility | Done | All channels equal when no DT8 colour set |
| Colour persistence in NVM | Done | RGBW + Tc survive power cycle |

## IEC 62386-102 — Memory Banks

| Bank | Access | Status | Notes |
|---|---|---|---|
| 0 | Read-only | Done | Gear identification (`dali_bank0.c`): GTIN, FW/HW versions, serial, 101/102/103 versions, logical-unit count. 27 bytes (last addr 0x1A). GTIN/serial are zero placeholders pending provisioning. |
| 1 | Read/write | -- | Luminaire data (rated power, colour info). Not implemented. |
| 2+ | Vendor-specific | -- | Not implemented. |

Read access via cmd 197 (READ MEMORY LOCATION) with DTR2 = bank, DTR1 = address.
Bank-write commands (ENABLE WRITE MEMORY, WRITE MEMORY LOCATION 0xC7/0xC9) are not implemented.

## Not Implemented

| Feature | Reason |
|---|---|
| ENABLE DAPC SEQUENCE (cmd 9) | Rarely used, complex timing |
| DALI-2 diagnostic queries (166-175) | Require HW monitoring circuitry |
| QUERY POWER FAILURE (157) | DALI-2, no HW monitoring |
| CIE xy chromaticity | Requires spectral calibration per LED |
| Tc temperature limits | Not implemented |
| Bus collision detection on direct GPIO (`DALI_NO_PHY`) | TX echo check cannot detect collisions on push-pull GPIO; use PHY mode (default) |
| Memory bank 1 + write access | Requires r/w storage strategy and lock/unlock state machine |
| Extended fade time | Done — used when fadeTime=0 (up to ~16 min fades) |

## Resource Usage

| Resource | RGBW | ONOFF |
|---|---|---|
| Flash | 9,668 B (59.0% of 16 KB) | — |
| RAM | 136 B (6.6% of 2 KB) | — |
| NVM page | 64 B at 0x08003FC0 (last flash page) |
| TIM1 | PWM (4 channels, 20 kHz) |
| TIM2 | DALI timing (1 MHz free-running) |
| EXTI0 | DALI RX (PC0, both edges) |
| SysTick | millis() (1 ms tick) |
| USART1 | Debug printf (PD5, 115200 baud) |

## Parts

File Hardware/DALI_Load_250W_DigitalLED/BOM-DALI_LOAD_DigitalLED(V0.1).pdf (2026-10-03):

Comment | Description | Designator | Footprint | Quantity
MOC3043 | Zero-Cross Triac Driver Output Optocoupler | A1 | DIP762W46P254L889H5 08Q6B | 1
B0505S | | A3 | B05_S-1WR3 | 1
100nF | Capacitor | C1, C4, C5 | C0402 | 3
22uF | Capacitor | C2, C3 | C0603 | 2
10uF/50V | Capacitor | C6, C7 | C1206 | 2
100nF/50V | Capacitor | C8 | C0402 | 1
ACST410-8BTR | TRIAC Alternistor -Snubberless, 600V, 4A DPAK | D1 | TO229P994X240-3N (DPAK) | 1
B5819W SL | Diode | D2, D3, D4 | SOD-123 | 3
0.8A | Fuse | F1 | FUSE-SMD_L10.3-W3.2 | 1
GZ1608D601TF | Ferrite_Bead | FB1 | 0603 | 1
ME3116 | 40-V, 600-mA High Efficiency Wide Input Voltage Range Buck Converter | IC1 | SOT95P280X110-6N (SOT23-6L) | 1
FFC 0.5mm 10Pin 90° | FFC 0.5mm 10P Bottom Connection C262659 | J1 | TE_1-1734592-0 | 1
NLCV32T-100K-PF (10uH) | 15uH | L1 | L1210 | 1
KF142R-5.08-4P | KF142R-5.08-4P | P1 | CONN-TH_4P-P5.08_KF142R-5.08-4P | 1
KF2EDGR-3.81-3Pin | KF2EDGR-3.81-3Pin | P2 | CONN-TH_3P-P3.81_KF2EDGR-3.81-3P | 1
4 Pin male | 4 Pin male | P7 | TE_826647-4 | 1
AO3400A | 30V N-Channel MOSFET | Q1 | SOT23 Normal | 1
51k | Resistor | R1 | R0603 | 1
15k | Resistor | R2 | R0603 | 1
10k | Resistor | R3 | 0402 | 1
270 | Resistor | R4 | R0603 | 1
150 | Resistor | R5 | R0603 | 1
100 | Resistor | R6 | R0603 | 1
390 | Resistor | R16 | R0603 | 1
1k | Resistor | R18 | 0402 | 1
100k | Resistor | R19 | 0402 | 1
pi110M30 | π110M30 | U5 | SOP8 | 1

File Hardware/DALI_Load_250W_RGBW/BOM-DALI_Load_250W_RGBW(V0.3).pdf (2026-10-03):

Comment | Description | Designator | Footprint | Quantity
MOC3043 | Zero-Cross Triac Driver Output Optocoupler | A1 | DIP762W46P254L889H5 08Q6B | 1
B0505S | | A2 | B05_S-1WR3 | 1
1uF | Capacitor | C1, C2, C3, C8 | C0402 | 4
100nF | Capacitor | C4, C5, C11 | C0402 | 3
10uF/50V | Capacitor | C12, C19 | C1206 | 2
100nF/50V | Capacitor | C16 | C0402 | 1
22uF | Capacitor | C17, C18 | C0603 | 2
ACST410-8BTR | TRIAC Alternistor -Snubberless, 600V, 4A DPAK | D1 | TO229P994X240-3N (DPAK) | 1
1N4148W | Diode | D2, D3, D4 | SOD-123 | 3
0.8A | Fuse | F1 | FUSE-SMD_L10.3-W3.2 | 1
GZ1608D601TF | Ferrite_Bead | FB1 | 0603 | 1
ME3116 | 60-V, 600-mA High Efficiency Wide Input Voltage Range Buck Converter | IC1 | SOT95P280X110-6N (SOT23-6L) | 1
FFC 0.5mm 10Pin 90° | FFC 0.5mm 10P Bottom Connection C262659 | J1 | TE_1-1734592-0 | 1
NLCV32T-100K-PF (10uH) | 15uH | L1 | L1210 | 1
KF142R-5.08-4P | KF142R-5.08-4P | P1 | CONN-TH_4P-P5.08_KF142R-5.08-4P | 1
KF2EDGR-3.81-5Pin | KF2EDGR-3.81-5Pin | P2 | CONN-TH_5P-P3.81_KF2EDGR-3.81-5P | 1
4 Pin male | 4 Pin male | P7 | TE_826647-4 | 1
AO3400A | 30V N-Channel MOSFET | Q1 | SOT23 Normal | 1
IRLU024N | N-HEXFET Power MOSFET | Q3, Q4, Q5, Q6 | TO228P680X240X837-3 (TO-251) | 4
10 | Resistor | R1, R2, R3, R7, R8, R9, R10, R17 | 0402 | 8
270 | Resistor | R4 | R0603 | 1
100 | Resistor | R6 | R0603 | 1
100k | Resistor | R12, R13, R14, R15, R19 | 0402 | 5
390 | Resistor | R16 | R0603 | 1
1k | Resistor | R18 | 0402 | 1
15k | Resistor | R20 | 0402 | 1
51k | Resistor | R46 | R0603 | 1
10k | Resistor | R47 | 0402 | 1
UCC27517DBVR | 4-A/4-A single-channel gate driver with 5-V UVLO and 13-ns prop delay in SOT-23 package | U1, U2, U3, U4 | SOT23-5 | 4
pi160M30 | π160M30 | U5 | SOIC127P600X180-16N SOP-16 | 1

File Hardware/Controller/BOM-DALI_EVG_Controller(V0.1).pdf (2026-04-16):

Comment | Description | Designator | Footprint | Quantity
100nF | Capacitor | C1, C3, C4, C11, C13, C14, C15 | C0402 | 7
10uF/50V | Capacitor | C12, C19 | C1206 | 2
100nF/50V | Capacitor | C16 | C0402 | 1
22uF | Capacitor | C17, C18 | C0603 | 2
1uF | Capacitor | C21 | C0603 | 1
220uF/50V | Polarized Capacitor (Axial) | C24 | CAPR-5mm | 1
18V | Zener | D1 | SOD-323 | 1
4.7V | Zener | D2 | SOD-323 | 1
MB10S | | D3 | SOIC245P670X290-4N | 1
BAV99 | Diode Array 1 Pair Series Connection Standard 100V 215mA (DC) Surface Mount TO-236-3, SC-59, SOT-23-3 | D4 | SOT23 | 1
B5819W SL | Diode | D6, D7, D9 | SOD-123 | 3
500mA | Fuse | F1, F2 | 1206 | 2
GZ1608D601TF | Ferrite_Bead | FB1 | 0603 | 1
LGS5145 | 60-V, 600-mA High Efficiency Wide Input Voltage Range Buck Converter | IC1 | SOT95P280X110-6N (SOT23-6L) | 1
C720477 | Tactile Switch | J2, J3 | TS-1088-AR02016 | 2
C262302 | FFC/FPC Connector 10 Position 0.5mm Pitch Single-side Contact/ Vertical Surface Mount | J4 | CONN-TH-10P_AFC11-S10ICC-00 | 1
CMI321609X100KT (10uH) | 15uH | L1 | L1210 | 1
KF2EDGR-3.81-4Pin | KF2EDGR-3.81-4Pin | P5 | CONN-TH_4P-P3.81_KF2EDGR-3.81-4P | 1
KF2EDGR-3.5-2Pin | KF2EDGR-3.5-2Pin | P6 | CONN-TH_2P-P3.50_KF2EDGR-3.5 | 1
Header | 4 Pin male | P7 | TE_826647-4 | 1
AO3400A | 30V N-Channel MOSFET | Q1 | SOT23 Normal | 1
AO3401A | 30V P-Channel MOSFET | Q2 | SOT23 Normal | 1
MMBT5401 | 60V, 600 mA, PNP switching transistor | Q3 | SOT23 Reverse | 1
MMBT5551 | NPN General Purpose Transistor | Q5 | SOT23 Reverse | 1
100k | Resistor | R1, R5, R31 | R0603 | 3
1 | Resistor | R2 | R0805 | 1
1k | Resistor | R3, R29 | 0402 | 2
100k | Resistor | R4 | 0402 | 1
22k | Resistor | R6 | R1206 | 1
10k | Resistor | R8, R9, R18, R23, R47 | 0402 | 5
0 | Resistor | R10 | R0603 | 1
27 | 0 | R19, R20 | 0402 | 2
1.5k | Resistor | R21 | R0603 | 1
10 | Resistor | R27, R41, R42 | R0603 | 3
1M | Resistor | R28 | R0603 | 1
4.7k | Resistor | R30 | R0603 | 1
8.2k | Resistor | R32 | R0603 | 1
18k | Resistor | R33 | R0603 | 1
33k | Resistor | R46 | R0603 | 1
CH32V003F4U6 | CPU Core:RISC-V CPU Maximum Speed:48MHz Program Storage Size:16KB Number of I/O:18 Applications:- | U1 | QFN-20_L3.0-W3.0-P0.40-TL-EP1.7 | 1
LMV331IDBVRG4 | Single General Purpose Low-Voltage Comparator 5-SOT-23 | U2 | SOT23-5 | 1
AT24C256C-SSHL-T | AT24C256C-SSHL-T | U3 | SOIC127P600X265-8N (SOIC-8) | 1

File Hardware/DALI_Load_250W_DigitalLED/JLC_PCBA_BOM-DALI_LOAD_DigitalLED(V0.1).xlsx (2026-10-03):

Comment | Description | Designator | Footprint | Quantity | JLCPCB Part #
MOC3043 | Zero-Cross Triac Driver Output Optocoupler | A1 | DIP762W46P254L889H508Q6B | 1
B0505S |  | A3 | B05_S-1WR3 | 1
100nF | Capacitor | C1, C4, C5 | C0402 | 3 | C307331
22uF | Capacitor | C2, C3 | C0603 | 2 | C59461
10uF/50V | Capacitor | C6, C7 | C1206 | 2 | C13585
100nF/50V | Capacitor | C8 | C0402 | 1 | C307331
ACST410-8BTR | TRIAC Alternistor - Snubberless, 600V, 4A DPAK | D1 | TO229P994X240-3N (DPAK) | 1
B5819W SL | Diode | D2, D3, D4 | SOD-123 | 3 | C8598
0.8A | Fuse | F1 | FUSE-SMD_L10.3-W3.2 | 1 | C53035203
GZ1608D601TF | Ferrite_Bead | FB1 | 0603 | 1 | C1002
ME3116 | 40-V, 600-mA High Efficiency Wide Input Voltage Range Buck Converter | IC1 | SOT95P280X110-6N (SOT23-6L) | 1
FFC 0.5mm 10Pin 90° | FFC 0.5mm 10P Bottom Connection C262659 | J1 | TE_1-1734592-0 | 1 | C262659
NLCV32T-100K-PF (10uH) | 15uH | L1 | L1210 | 1 | C107341
KF142R-5.08-4P | KF142R-5.08-4P | P1 | CONN-TH_4P-P5.08_KF142R-5.08-4P | 1
KF2EDGR-3.81-3Pin | KF2EDGR-3.81-3Pin | P2 | CONN-TH_3P-P3.81_KF2EDGR-3.81-3P | 1
4 Pin male | 4 Pin male | P7 | TE_826647-4 | 1
AO3400A | 30V N-Channel MOSFET | Q1 | SOT23 Normal | 1 | C20917
51k | Resistor | R1 | R0603 | 1 | C23196
15k | Resistor | R2 | R0603 | 1 | C22809
10k | Resistor | R3 | 0402 | 1 | C25744
270 | Resistor | R4 | R0603 | 1 | C22966
150 | Resistor | R5 | R0603 | 1 | C22808
100 | Resistor | R6 | R0603 | 1 | C22775
390 | Resistor | R16 | R0603 | 1 | C23151
1k | Resistor | R18 | 0402 | 1 | C11702
100k | Resistor | R19 | 0402 | 1 | C25741
pi110M30 | π110M30 | U5 | SOP8 | 1 | C970946

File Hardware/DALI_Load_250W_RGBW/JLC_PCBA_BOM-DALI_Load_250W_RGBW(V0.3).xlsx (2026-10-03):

Comment | Description | Designator | Footprint | Quantity | JLCPCB Part #
MOC3043 | Zero-Cross Triac Driver Output Optocoupler | A1 | DIP762W46P254L889H508Q6B | 1
B0505S |  | A2 | B05_S-1WR3 | 1
1uF | Capacitor | C1, C2, C3, C8 | C0402 | 4 | C52923
100nF | Capacitor | C4, C5, C11 | C0402 | 3 | C307331
10uF/50V | Capacitor | C12, C19 | C1206 | 2 | C13585
100nF/50V | Capacitor | C16 | C0402 | 1 | C307331
22uF | Capacitor | C17, C18 | C0603 | 2 | C59461
ACST410-8BTR | TRIAC Alternistor - Snubberless, 600V, 4A DPAK | D1 | TO229P994X240-3N (DPAK) | 1
1N4148W | Diode | D2, D3, D4 | SOD-123 | 3 | C81598
0.8A | Fuse | F1 | FUSE-SMD_L10.3-W3.2 | 1 | C53035203
GZ1608D601TF | Ferrite_Bead | FB1 | 0603 | 1 | C1002
ME3116 | 60-V, 600-mA High Efficiency Wide Input Voltage Range Buck Converter | IC1 | SOT95P280X110-6N (SOT23-6L) | 1
FFC 0.5mm 10Pin 90° | FFC 0.5mm 10P Bottom Connection C262659 | J1 | TE_1-1734592-0 | 1 | C262659
NLCV32T-100K-PF (10uH) | 15uH | L1 | L1210 | 1 | C107341
KF142R-5.08-4P | KF142R-5.08-4P | P1 | CONN-TH_4P-P5.08_KF142R-5.08-4P | 1
KF2EDGR-3.81-5Pin | KF2EDGR-3.81-5Pin | P2 | CONN-TH_5P-P3.81_KF2EDGR-3.81-5P | 1
4 Pin male | 4 Pin male | P7 | TE_826647-4 | 1
AO3400A | 30V N-Channel MOSFET | Q1 | SOT23 Normal | 1 | C20917
IRLU024N | N-HEXFET Power MOSFET | Q3, Q4, Q5, Q6 | TO228P680X240X837-3 (TO-251) | 4
10 | Resistor | R1, R2, R3, R7, R8, R9, R10, R17 | 0402 | 8 | C25077
270 | Resistor | R4 | R0603 | 1 | C22966
100 | Resistor | R6 | R0603 | 1 | C22775
100k | Resistor | R12, R13, R14, R15, R19 | 0402 | 5 | C25741
390 | Resistor | R16 | R0603 | 1 | C23151
1k | Resistor | R18 | 0402 | 1 | C11702
15k | Resistor | R20 | 0402 | 1 | C25756
51k | Resistor | R46 | R0603 | 1 | C23196
10k | Resistor | R47 | 0402 | 1 | C25744
UCC27517DBVR | 4-A/4-A single-channel gate driver with 5-V UVLO and 13-ns prop delay in SOT-23 package | U1, U2, U3, U4 | SOT23-5 | 4 | C20623191
pi160M30 | π160M30 | U5 | SOIC127P600X180-16N SOP-16 | 1 | C6807852

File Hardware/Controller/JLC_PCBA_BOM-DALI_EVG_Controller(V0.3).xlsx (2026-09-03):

Comment | Description | Designator | Footprint | Quantity
100nF | Capacitor | C1, C3, C4, C11, C13, C14, C15 | C0402 | 7
1nF | Capacitor | C6 | C0603 | 1
10uF/50V | Capacitor | C12, C19 | C1206 | 2
100nF/50V | Capacitor | C16 | C0402 | 1
22uF | Capacitor | C17, C18 | C0603 | 2
1uF | Capacitor | C21 | C0603 | 1
220uF/35V | Polarized Capacitor (Axial) | C24 | CAPR-5mm | 1
1N4148W | Diode | D1, D4 | SOD-123 | 2
MB10S |  | D3 | SOIC245P670X290-4N | 1
500mA | Fuse | F1, F2 | 1206 | 2
GZ1608D601TF | Ferrite_Bead | FB1, FB2, FB3 | 0603 | 3
LGS5145 | 60-V, 600-mA High Efficiency Wide Input Voltage Range Buck Converter | IC1 | SOT95P280X110-6N (SOT23-6L) | 1
C720477 | Tactile Switch | J2, J3 | TS-1088-AR02016 | 2
FFC 0.5mm 10Pin 90° | FFC 0.5mm 10P Bottom Connection C262659 | J4 | TE_1-1734592-0 | 1
Terminalblock X2 |  | J6, J7 | Terminalblock_X2_5mm | 2
CMI321609X100KT (10uH) | 15uH | L1 | L1210 | 1
KF2EDGR-3.5-2Pin | KF2EDGR-3.5-2Pin | P6 | CONN-TH_2P-P3.50_KF2EDGR-3.5 | 1
Header | 4 Pin male | P7 | TE_826647-4 | 1
AO3400A | 30V N-Channel MOSFET | Q1 | SOT23 Normal | 1
1 | Resistor | R2 | R0805 | 1
1k | Resistor | R3, R29 | 0402 | 2
100k | Resistor | R4 | 0402 | 1
10k | Resistor | R8, R9, R18, R23, R47 | 0402 | 5
15k | Resistor | R12 | 0402 | 1
10 | Resistor | R27 | R0603 | 1
470k | Resistor | R28 | R0603 | 1
4.7k | Resistor | R30 | R0603 | 1
100k | Resistor | R31 | R0603 | 1
8.2k | Resistor | R32 | R0603 | 1
18k | Resistor | R33 | R0603 | 1
33k | Resistor | R46 | R0603 | 1
CH32V003F4U6 | CPU Core:RISC-V CPU Maximum Speed:48MHz Program Storage Size:16KB Number of I/O:18 Applications:- | U1 | QFN-20_L3.0-W3.0-P0.40-TL-EP1.7 | 1
LMV331IDBVRG4 | Single General Purpose Low-Voltage Comparator 5-SOT-23 | U2 | SOT23-5 | 1
AT24C256C-SSHL-T | AT24C256C-SSHL-T | U3 | SOIC127P600X265-8N (SOIC-8) | 1

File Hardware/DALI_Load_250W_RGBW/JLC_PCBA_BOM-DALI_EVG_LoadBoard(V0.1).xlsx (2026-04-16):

Comment | Description | Value | Designator | Footprint | Quantity
MOC3043 | Zero-Cross Triac Driver Output Optocoupler |  | A1 | DIP762W46P254L889H508Q6B | 1
1uF/25V | Capacitor | 100nF | C1, C2, C3, C8 | C0603 | 4
10uF/25V | Capacitor | 100nF | C5, C6 | C0805 | 2
ACST410-8BTR | TRIAC Alternistor - Snubberless, 600V, 4A DPAK |  | D1 | TO229P994X240-3N (DPAK) | 1
BZT52C15S (15V) | Zener |  | D4 | SOD-323 | 1
1.5A | Fuse |  | F1 | 1808 Fuse / FUSE_0154004 | 1
FFC 0.5mm 10Pin 90° | FFC 0.5mm 10P Bottom Connection C262659 |  | J1 | TE_1-1734592-0 | 1
KF142R-5.08-4P | KF142R-5.08-4P |  | P1 | CONN-TH_4P-P5.08_KF142R-5.08-4P | 1
KF2EDGR-3.81-5Pin | KF2EDGR-3.81-5Pin |  | P2 | CONN-TH_5P-P3.81_KF2EDGR-3.81-5P | 1
4 Pin male | 4 Pin male |  | P7 | TE_826647-4 | 1
MMBT5551 | NPN General Purpose Transistor |  | Q2 | SOT23 | 1
IRLU024N | N-HEXFET Power MOSFET |  | Q3, Q4, Q5, Q6 | TO228P680X240X837-3 (TO-251) | 4
10 | Resistor |  | R1, R2, R3, R7, R8, R9, R10, R17 | R0603 | 8
390 | Resistor |  | R4, R16 | R1206 | 2
22k | Resistor |  | R5 | R0603 | 1
0 | Resistor |  | R6 | R1206 | 1
100k | Resistor |  | R11, R12, R13, R14, R15 | R0603 | 5
UCC27517DBVR | 4-A/4-A single-channel gate driver with 5-V UVLO and 13-ns prop delay in SOT-23 package |  | U1, U2, U3, U4 | SOT23-5 | 4

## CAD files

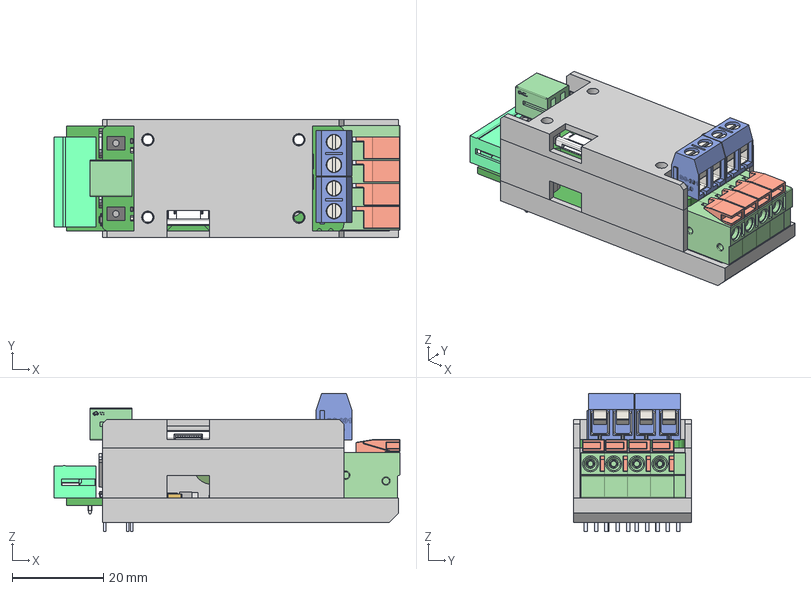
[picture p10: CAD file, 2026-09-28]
Hardware/DALI_EVG.step
75.9 x 26.0 x 30.4 mm

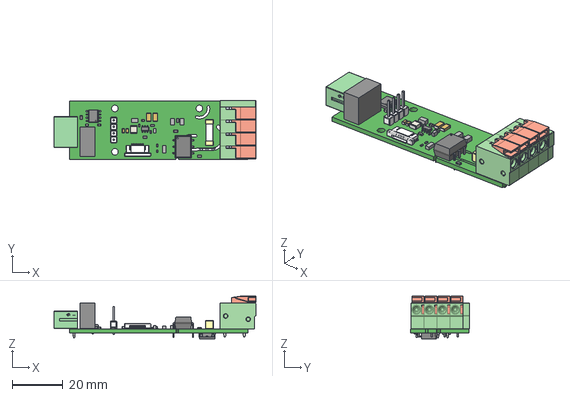
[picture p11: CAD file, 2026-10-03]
Hardware/DALI_Load_250W_DigitalLED/DALI_LOAD_DigitalLED(V0.1).step
79.2 x 23.1 x 16.8 mm

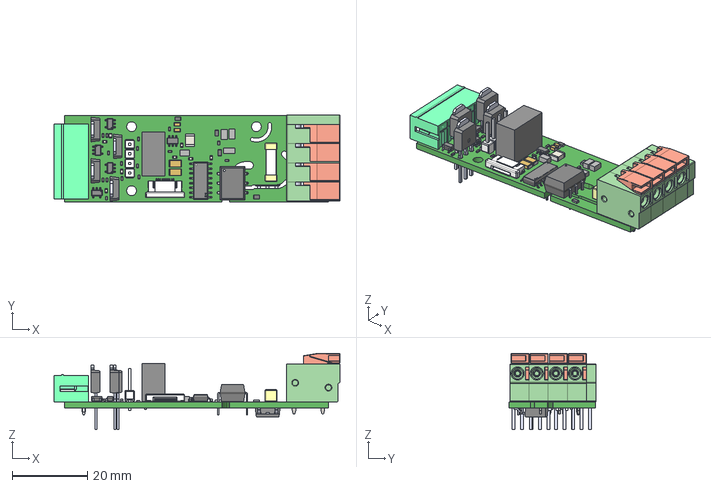
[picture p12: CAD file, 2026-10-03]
Hardware/DALI_Load_250W_RGBW/DALI_Load_250W_RGBW(V0.3).step
75.9 x 23.1 x 20.2 mm

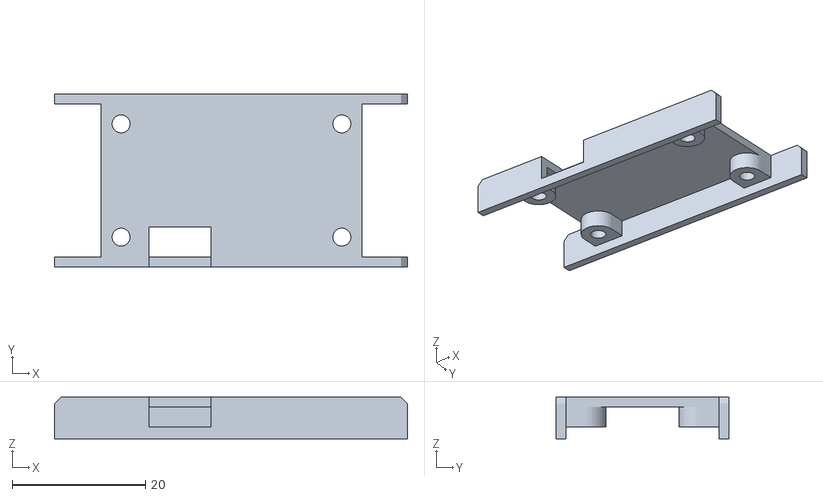
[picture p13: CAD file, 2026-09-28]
Hardware/stl/Top.stl
53.0 x 26.0 x 6.30

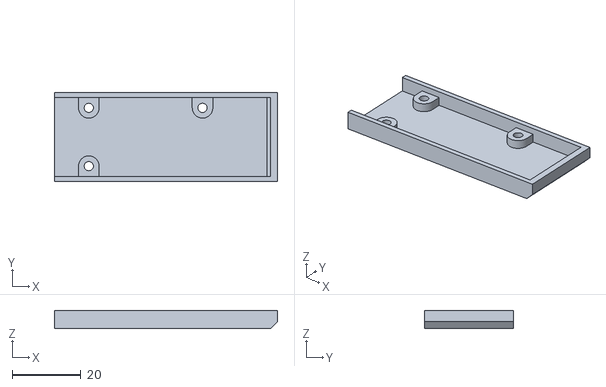
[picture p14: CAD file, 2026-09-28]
Hardware/stl/Bot.stl
65.0 x 26.0 x 5.30

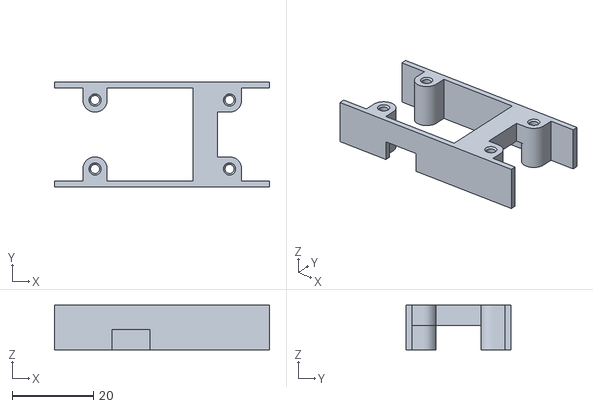
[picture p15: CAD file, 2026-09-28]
Hardware/stl/Mid.stl
53.0 x 26.0 x 11.0

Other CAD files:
Hardware/DALI_EVG.f3z
Hardware/DALI_Load_250W_DigitalLED/DALI_LOAD_DigitalLED(V0.1).x_t
Hardware/DALI_Load_250W_RGBW/DALI_Load_250W_RGBW(V0.3).x_t

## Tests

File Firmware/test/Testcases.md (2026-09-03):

# DALI EVG Test Cases (ch32fun Firmware)

## Hardware Setup

### Devices Under Test
| Device | MCU | Role | COM Port |
|---|-----|---|---|
| Raspberry Pi Pico | RP2040 (133 MHz) | DALI Master (bitbang) | COM9 |
| CH32V003F4U6 | RISC-V (48 MHz) | DALI Slave (control gear) | COM11 (debug serial) |

### Pin Connections
| Signal | Pico Pin | CH32V003 Pin | LA Channel | Notes |
|---|---|---|---|---|
| DALI Bus | GPIO17 (TX) | PC3 (RX) | D0 | Via DALI PHY transceiver |
| DALI Backward | GPIO16 (RX) | PC4 (TX) | D1 | Slave-to-master Manchester response via PHY |
| LED PWM 1 | — | PC6 (TIM1_CH1) | — | 20 kHz PWM (2400 steps) |
| LED PWM 2 | — | PC7 (TIM1_CH2) | — | 20 kHz PWM (2400 steps) |
| LED PWM 3 | — | PC0 (TIM1_CH3) | D7 | 20 kHz PWM (2400 steps) |
| LED PWM 4 | — | PD3 (TIM1_CH4) | — | 20 kHz PWM (2400 steps) |

> **Pinout note (updated 2026-06-07):** pins below reflect the current controller mapping (introduced with **V0.2**, unchanged in V0.3) (RX=PC3, TX=PC4, PWM=PC6/PC7/PC0/PD3, SCK=PC5). Earlier captures in this file were originally taken on the **V0.1** mapping (RX=PC0, TX=PC5, PWM=PD2/PA1/PC3/PC4); the measured values (duty %, timing, PASS/FAIL) are pin-agnostic and remain valid.
| Serial Debug | USB CDC | PD5 (USART1_TX) | — | 115200 baud |

### Logic Analyzer
- Saleae clone (fx2lafw driver)
- Sample rate: 500 kHz (max recommended for this LA)
- Tool: sigrok-cli

### Flashing
- Pico: `pio run -t upload` via picotool (USB)
- CH32V003: `wlink.exe flash firmware.bin` via WCH-LinkE

---

## Firmware Info

| Property | Value |
|---|---|
| Framework | ch32fun (cnlohr/ch32fun) |
| Flash usage | 9,668 B (59.0%) |
| RAM usage | 136 B (6.6%) |
| PWM channels | 4 (configurable via `PWM_NUM_CHANNELS` in hardware.h) |
| Dimming curve | IEC 62386-102 §9.3 logarithmic (254-entry LUT, 508 bytes) |
| Features | Forward RX, Backward TX, PWM (1-4ch), Fade engine, DTR0/1/2, DT8 RGBW+Tc, Short address, Groups, Scenes, Min/Max/PowerOn levels, Memory bank 0 (read-only), TX collision detection (PHY) |

---

## TC-01: Forward Frame RX (Manchester Decode)

**Objective:** Verify the slave correctly decodes 16-bit DALI forward frames.

**Script:** `Debug_Helpers/ch32fun_test.ps1`

**Procedure:**
1. Send `broadcast <level>` from Pico master (COM9)
2. Read slave serial output (COM11) for decoded level
3. Repeat for levels 0, 128, 254

**Expected:**
- Slave prints `LVL=<level> PWM=<log_value>` for each command
- 100% decode rate (no missed or corrupted frames)

**Results:**
| Command | Frame (hex) | Slave Output | Status |
|---|---|---|---|
| `broadcast 0` | 0xFE00 | LVL=0 PWM=0 | PASS |
| `broadcast 128` | 0xFE80 | LVL=128 PWM=131 | PASS |
| `broadcast 254` | 0xFEFE | LVL=254 PWM=4095 | PASS |

**LA Verification (D0):** 32 edges per forward frame = correct for 16-bit Manchester encoding (1 start bit + 16 data bits).

---

## TC-02: Backward Frame TX (Manchester Encode)

**Objective:** Verify the slave responds with 8-bit backward frames to query commands.

**Script:** `Debug_Helpers/ch32fun_test.ps1`

**Procedure:**
1. Set a known level via `broadcast <level>`
2. Send query commands via `querybc <cmd>` from Pico master
3. Verify master receives correct response values

**Results:**
| Query | Cmd | Expected | Received | Status |
|---|-----|---|---|---|
| QUERY ACTUAL LEVEL | 160 | 128 (after broadcast 128) | 128 (0x80) | PASS |
| QUERY ACTUAL LEVEL | 160 | 100 (after broadcast 100) | 100 (0x64) | PASS |
| QUERY STATUS | 144 | Lamp on + missing short | 0x44 | PASS |
| QUERY GEAR PRESENT | 145 | YES (0xFF) | 255 (0xFF) | PASS |
| QUERY MAX LEVEL | 161 | 254 | 254 (0xFE) | PASS |
| QUERY MIN LEVEL | 162 | 1 | 1 (0x01) | PASS |
| QUERY POWER ON LEVEL | 163 | 254 | 254 (0xFE) | PASS |

**LA Verification (D1):** 18 edges per backward frame = correct for 8-bit Manchester (1 start + 8 data + stop transitions).

---

## TC-03: PWM Duty Cycle Accuracy (Logarithmic Dimming)

**Objective:** Verify PWM output follows IEC 62386-102 §9.3 logarithmic dimming curve.

**Script:** `Debug_Helpers/dali_logdim_test.ps1`

**Dimming Curve:** `PWM = round(10^((level-1)*3/253 - 1) / 100 * 4095)`

**Procedure:**
1. Send `broadcast <level>` for various levels
2. Read slave serial for PWM value (from log lookup table)
3. Capture PWM signal on LA channel D7, measure duty cycle

**Results:**
| DALI Level | Expected PWM | Measured PWM | Expected Duty | Measured Duty | Status |
|---|---|---|---|---|---|
| 0 | 0 | 0 | 0% | 0.0% | PASS |
| 1 | 4 | 4 | 0.1% | 0.1% | PASS |
| 64 | 23 | 23 | 0.6% | 0.6% | PASS |
| 128 | 131 | 131 | 3.2% | 3.2% | PASS |
| 170 | 391 | 391 | 9.5% | 9.5% | PASS |
| 191 | 733 | 733 | 17.9% | 17.9% | PASS |
| 220 | 1618 | 1618 | 39.5% | 39.5% | PASS |
| 240 | 2794 | 2794 | 68.2% | 68.2% | PASS |
| 254 | 4095 | 4095 | 100% | 99.6% | PASS |

**Note:** All 4 channels (PC6, PC7, PC0, PD3) output the same duty cycle.

---

## TC-04: Manchester Signal Integrity (LA)

**Objective:** Verify forward and backward frame signals are clean and independent.

**Script:** `Debug_Helpers/ch32fun_la_test.ps1`

**Procedure:**
1. Send `broadcast 128` (no backward frame expected)
2. Capture D0 + D1 simultaneously
3. Verify D0 has Manchester edges, D1 has none
4. Send `querybc 160` (backward frame expected)
5. Capture D0 + D1 simultaneously
6. Verify both channels have Manchester edges

**Results:**
| Test | D0 Edges | D1 Edges | Status |
|---|---|---|---|
| Broadcast (no response) | 32 | 0 | PASS — signals independent |
| Query (with response) | 32 | 18 | PASS — backward frame present |

---

## TC-05: Timing Verification (IEC 62386-101)

**Objective:** Verify Manchester half-bit timing (Te) and backward frame settle time comply with IEC 62386-101.

**Script:** `Debug_Helpers/dali_timing_verify.ps1`

**IEC 62386-101 Requirements:**
- Te (half-bit period) = 416.67 µs ±10% (375–458 µs)
- Backward frame settle: 7–22 Te after forward frame ends

**Procedure:**
1. Send `querybc 160` from master
2. Capture D0 (forward) and D1 (backward) on LA
3. Measure edge-to-edge intervals for Te statistics
4. Measure gap between last D0 edge and first D1 edge for settle time

**Results:**
| Parameter | Spec | Measured | Status |
|---|---|---|---|
| Master TX Te (avg) | 416.67 µs ±10% | 417.4 µs | PASS |
| Master TX Te (range) | 375–458 µs | 416–420 µs | PASS |
| Slave TX Te (avg) | 416.67 µs ±10% | 415.2 µs | PASS |
| Slave TX Te (range) | 375–458 µs | 414–416 µs | PASS |
| Forward→Backward settle | 7–22 Te | 16 Te | PASS |
| Forward frame edges (D0) | 32 | 32 | PASS |
| Backward frame edges (D1) | 16–18 | 16 | PASS |

---

## TC-06: Short Address Assignment (DALI Addressing Protocol)

**Objective:** Verify the full DALI addressing protocol: INITIALISE, RANDOMISE, binary search (SEARCHADDR + COMPARE), PROGRAM SHORT ADDRESS, WITHDRAW, TERMINATE. Then verify the slave responds to commands addressed to its short address.

**Script:** `Debug_Helpers/ch32fun_assign_test.ps1`

**Procedure:**
1. Set a known level via `broadcast 128`
2. Run `assign 5` from master (performs full addressing sequence)
3. Verify INITIALISE accepted (slave prints `INIT ok`)
4. Verify RANDOMISE generated address (slave prints `RAND=XXXXXX`)
5. Verify binary search converges to exact random address (24 steps)
6. Verify PROGRAM SHORT succeeds (slave prints `PROG_SHORT=5`)
7. Verify query by short address returns correct level
8. Verify arc power by short address changes level
9. Verify broadcast still works after addressing

**Results:**
| Step | Expected | Actual | Status |
|---|---|---|---|
| INITIALISE 0xFF (x2) | Accepted (config repeat) | `INIT ok` | PASS |
| RANDOMISE (x2) | Random addr generated | `RAND=C27054` | PASS |
| Binary search (24 steps) | Find exact random address | Found 0xC27054 | PASS |
| PROGRAM SHORT ADDRESS 5 | Address stored | `PROG_SHORT=5` | PASS |
| WITHDRAW | Slave withdrawn | `WITHDRAW` | PASS |
| Master verify (query addr 5) | Response with level | Level=128 | PASS |
| `query 5 160` after assign | 128 | 128 (0x80) | PASS |
| `arc 5 200` (short addr) | Level changes to 200 | `LVL=200 PWM=1618` | PASS |
| `query 5 160` after arc | 200 | 200 (0xC8) | PASS |
| `broadcast 50` after assign | Level changes to 50 | `LVL=50 PWM=16` | PASS |
| `querybc 160` | 50 | 50 (0x32) | PASS |
| `query 5 160` after broadcast | 50 | 50 (0x32) | PASS |
| TERMINATE | Init state disabled | `TERM` | PASS |

---

## TC-07: DALI Spec Compliance Fixes

**Objective:** Verify IEC 62386-102 spec compliance for edge cases found during code review.

**Procedure:**
1. Test MASK (0xFF) direct arc power — must NOT change level
2. Test QUERY MISSING SHORT ADDRESS with/without assigned address

**Results:**
| Test | IEC Requirement | Expected | Actual | Status |
|---|---|---|---|---|
| `broadcast 255` (MASK) | No action (§9.5.1) | Level unchanged | Level unchanged | PASS |
| QUERY MISSING SHORT (no addr) | YES (0xFF) | 0xFF | 0xFF | PASS |
| QUERY MISSING SHORT (addr=5) | No response | Silence | Silence | PASS |

---

## TC-08: PWM Channel Configuration

**Objective:** Verify PWM output works on all 4 TIM1 channels when `PWM_NUM_CHANNELS = 4`.

**Procedure:**
1. Build with `PWM_NUM_CHANNELS = 4` (default)
2. Send `broadcast 128`
3. Measure PWM duty cycle on all 4 output pins

**Expected:** All channels output identical duty cycle.

| Channel | Pin | TIM1 Channel | Duty Cycle | Status |
|---|-----|---|---|---|
| CH1 | PC6 | TIM1_CH1 | 3.2% | PASS |
| CH2 | PC7 | TIM1_CH2 | 3.2% | PASS |
| CH3 | PC0 | TIM1_CH3 | 3.2% | PASS |
| CH4 | PD3 | TIM1_CH4 | 3.2% | PASS |

---

## TC-09: Fade Engine (IEC 62386-102 §9.5)

**Objective:** Verify fadeTime-based arc power fading, fadeRate-based UP/DOWN, STEP UP/DOWN, and DTR0/config commands.

**Procedure:**
1. Set DTR0 to 4 via `raw A304` (DALI_SPECIAL_DTR, data=4)
2. Send STORE DTR AS FADE TIME twice: `raw FF2E` × 2 within 100 ms (cmd 46, config repeat)
3. Verify: `querybc 165` returns 0x47 (fadeTime=4, fadeRate=7)
4. Send `broadcast 254` — should fade from 0 to 254 over ~2 seconds (fadeTime=4 → 2000 ms)
5. Send `broadcast 0` — should go OFF instantly (OFF is always instant)
6. Test UP: `raw FF01` (cmd 1) — should fade up at fadeRate=7
7. Test DOWN: `raw FF02` (cmd 2) — should fade down at fadeRate=7
8. Test STEP UP: `raw FF03` (cmd 3) — should increase level by 1 instantly
9. Test STEP DOWN: `raw FF04` (cmd 4) — should decrease level by 1 instantly
10. Verify QUERY STATUS bit 4 (fadeRunning) is set during fade: `querybc 144`
11. Verify QUERY DTR0: `querybc 152` returns 4
12. Verify QUERY DEVICE TYPE: `querybc 153` returns 8 (colour control)
13. Verify QUERY PHYS MIN: `querybc 154` returns 1

**Results:**
| Test | Expected | Actual | Status |
|---|---|---|---|
| STORE DTR AS FADE TIME | fadeTime=4 | — | — |
| QUERY FADE SPEEDS (165) | 0x47 | — | — |
| Arc 254 with fadeTime=4 | Fade over ~2 sec | — | — |
| OFF (cmd 0) | Instant to 0 | — | — |
| UP (cmd 1) | Fade up at fadeRate | — | — |
| DOWN (cmd 2) | Fade down at fadeRate | — | — |
| STEP UP (cmd 3) | Level +1 instant | — | — |
| STEP DOWN (cmd 4) | Level -1 instant | — | — |
| STATUS fadeRunning bit | Set during fade | — | — |
| QUERY DTR0 (152) | 4 | — | — |
| QUERY DEVICE TYPE (153) | 8 | — | — |
| QUERY PHYS MIN (154) | 1 | — | — |

---

## TC-10: DT8 Colour Control (IEC 62386-209)

**Objective:** Verify DT8 RGBW colour control: ENABLE_DT, SET_TEMP_RGB/WAF, ACTIVATE, colour temperature Tc, DT8 queries.

**Script:** `Debug_Helpers/ch32fun_dt8_test.ps1`

**DT8 Protocol Flow:**
```
1. Master: ENABLE_DT (0xC1), data=8    → slave stores enabled_device_type=8
2. Master: addr_byte, cmd (224-254)     → slave routes to DT8 handler
```

**Procedure:**
1. Verify QUERY DEVICE TYPE returns 8 (colour control)
2. Set DTR2=254, DTR1=0, DTR0=0 → ENABLE_DT 8 → SET_TEMP_RGB (235) → ENABLE_DT 8 → ACTIVATE (226)
   - Expected: CH1 (R) at full, CH2/CH3/CH4 at 0 — red only
3. Set DTR2=128 → ENABLE_DT 8 → SET_TEMP_WAF (236) → ENABLE_DT 8 → ACTIVATE (226)
   - Expected: CH4 (W) at half, CH1 (R) at full, CH2/CH3 at 0
4. ENABLE_DT 8 → QUERY_COLOUR_TYPE_FEATURES (249) → expect 0x06 (Tc + Primary)
5. ENABLE_DT 8 → QUERY_RGBWAF_CONTROL (251) → expect 0x0F (4 channels)
6. Set DTR0=64 → ENABLE_DT 8 → QUERY_COLOUR_VALUE (250) → expect 4 (num primaries)
7. Set DTR1=0, DTR0=154 (6500K mirek) → ENABLE_DT 8 → SET_TEMP_COLOUR_TEMPERATURE (231) → ENABLE_DT 8 → ACTIVATE → cool white
8. ENABLE_DT 8 → STEP_WARMER (233) → ENABLE_DT 8 → ACTIVATE → slightly warmer
9. DT6 backward compatibility: `broadcast 128` with colour set → all channels at half brightness with colour ratios preserved

**Results:**
| Test | Expected | Actual | Status |
|---|---|---|---|
| QUERY DEVICE TYPE (153) | 8 | — | — |
| SET_TEMP_RGB (red only) + ACTIVATE | R=254, G=0, B=0 | — | — |
| SET_TEMP_WAF (add W=128) + ACTIVATE | R=254, W=128 | — | — |
| QUERY_COLOUR_TYPE_FEATURES (249) | 0x06 | — | — |
| QUERY_RGBWAF_CONTROL (251) | 0x0F | — | — |
| QUERY_COLOUR_VALUE (250, DTR0=64) | 4 | — | — |
| SET_TEMP_COLOUR_TEMP (6500K) + ACTIVATE | Cool white | — | — |
| STEP_WARMER + ACTIVATE | Slightly warmer | — | — |
| broadcast 128 with colour | Scaled RGBW | — | — |

---

## TC-11: DALI-1/2 Compliance (Scenes, Groups, Min/Max, RESET)

**Objective:** Verify scene storage/recall, group addressing, min/max level clamping, power-on level, RESET, and new queries.

**Procedure:**

### Part A: Min/Max Level Clamping
1. Set DTR0=100 via `raw A364` → STORE DTR AS MAX LEVEL (42) × 2: `raw FF2A` × 2
2. Verify: `querybc 161` → 100 (maxLevel)
3. Send `broadcast 200` → should clamp to 100
4. Send `broadcast 50` → should be 50 (within range)
5. Set DTR0=20 → STORE DTR AS MIN LEVEL (43) × 2
6. Verify: `querybc 162` → 20 (minLevel)
7. Send `broadcast 10` → should clamp to 20
8. STEP DOWN from level 20 → should go to 0 (OFF)
9. STEP UP from 0 → should go to minLevel (20)
10. UP from 0 → should start at minLevel (20), fade to maxLevel (100)
11. DOWN → should stop at minLevel (20), never go to 0

### Part B: Scenes
1. Set DTR0=128 → STORE DTR AS SCENE 0 (64) × 2: `raw FF40` × 2
2. Set DTR0=200 → STORE DTR AS SCENE 1 (65) × 2: `raw FF41` × 2
3. Verify: QUERY SCENE LEVEL 0 (176) → 128
4. Verify: QUERY SCENE LEVEL 1 (177) → 200
5. Verify: QUERY SCENE LEVEL 2 (178) → 0xFF (MASK, not set)
6. Send GO TO SCENE 0 (cmd 16): `raw FF10` → level should change to 128
7. Send GO TO SCENE 1 (cmd 17): `raw FF11` → level should change to 200
8. REMOVE FROM SCENE 0 (80) × 2 → QUERY SCENE 0 → 0xFF
9. GO TO SCENE 0 → no action (MASK)

### Part C: Group Addressing
1. Assign short address 5 first (via INITIALISE + binary search)
2. ADD TO GROUP 3 (99) × 2: `raw 0B63` × 2 (short addr 5, cmd 99)
3. Verify: QUERY GROUPS 0-7 (198) → 0x08 (bit 3 set)
4. Send group 3 broadcast arc power: address byte 0x86 (100 0011 0) → level should change
5. Send group 3 command OFF: address byte 0x87 (100 0011 1), data 0x00 → OFF
6. REMOVE FROM GROUP 3 (115) × 2 → QUERY GROUPS 0-7 → 0x00
7. Group 3 command → no response (not member)

### Part D: RESET
1. Modify several variables (maxLevel, minLevel, fadeTime, scenes, groups)
2. Send RESET (32) × 2: `raw FF20` × 2
3. Verify all defaults restored:
   - QUERY ACTUAL LEVEL → 254
   - QUERY MAX LEVEL → 254
   - QUERY MIN LEVEL → 1
   - QUERY POWER ON LEVEL → 254
   - QUERY FADE SPEEDS → 0x07 (fadeTime=0, fadeRate=7)
   - QUERY SCENE 0 → 0xFF
   - QUERY GROUPS 0-7 → 0x00
4. Verify short address NOT cleared (still assigned)

### Part E: Power-On Level & System Failure Level
1. Set DTR0=100 → STORE DTR AS POWER ON LEVEL (44) × 2
2. Verify: QUERY POWER ON LEVEL (163) → 100
3. Set DTR0=50 → STORE DTR AS SYSTEM FAILURE LEVEL (45) × 2
4. Verify: QUERY SYS FAIL LEVEL (164) → 50

### Part F: DTR1/DTR2 Queries
1. Set DTR1=42 via `raw C32A`, DTR2=99 via `raw C563`
2. QUERY DTR1 (155) → 42
3. QUERY DTR2 (156) → 99

**Results:**
| Test | Expected | Actual | Status |
|---|---|---|---|
| MaxLevel clamp | Clamp to 100 | — | — |
| MinLevel clamp | Clamp to 20 | — | — |
| STEP DOWN from min | Goes to 0 | — | — |
| DOWN stops at min | Stops at 20 | — | — |
| Scene store + recall | Level changes | — | — |
| Scene remove + recall | No action | — | — |
| Group add + command | Responds | — | — |
| Group remove + command | No response | — | — |
| RESET defaults | All restored | — | — |
| RESET keeps short addr | Still assigned | — | — |
| Power-on level query | 100 | — | — |
| System failure query | 50 | — | — |
| DTR1/DTR2 queries | 42/99 | — | — |

---

## TC-12: Memory Bank 0 (READ MEMORY LOCATION)

**Objective:** Verify the read-only memory bank 0 returns the IEC 62386-102:2014 §4.3.10 layout via cmd 197 (READ MEMORY LOCATION) and that DTR1 post-increments correctly.

**Background:** Bank 0 identifies the gear: GTIN, FW/HW version, serial, 101/102/103 versions, logical-unit count. Master access is `DTR2 = bank, DTR1 = address, then cmd 197`. Each read post-increments DTR1 and mirrors the value into DTR0. Out-of-range / wrong-bank reads are silent (no backward frame).

**Procedure:**
1. Set DTR2 = 0 via `raw C500` (DALI_SPECIAL_DTR2)
2. Set DTR1 = 0 via `raw C300` (DALI_SPECIAL_DTR1)
3. Read 0x1B bytes via repeated `querybc 197` and verify each:

| DTR1 | Field | Expected (default build) |
|---|---|---|
| 0x00 | Last accessible loc in bank 0 | 0x1A |
| 0x01 | Reserved | 0xFF |
| 0x02 | Last accessible bank | 0x00 |
| 0x03..0x08 | GTIN (6 B, MSB first) | 0x00 0x00 0x00 0x00 0x00 0x00 (placeholder) |
| 0x09 | FW version major | `DALI_FW_VERSION_MAJOR` (default 1) |
| 0x0A | FW version minor | `DALI_FW_VERSION_MINOR` (default 0) |
| 0x0B..0x12 | Identification number (8 B) | 0x00 × 8 (placeholder) |
| 0x13 | HW version major | `DALI_HW_VERSION_MAJOR` (default 1) |
| 0x14 | HW version minor | `DALI_HW_VERSION_MINOR` (default 0) |
| 0x15 | IEC 62386-101 version | 0x08 (DALI-2) |
| 0x16 | IEC 62386-102 version | 0x08 (DALI-2) |
| 0x17 | IEC 62386-103 version | 0xFF (not control device) |
| 0x18 | Logical control device units | 0xFF |
| 0x19 | Logical control gear units | 0x01 |
| 0x1A | Index of this gear unit | 0x00 |

4. After the last successful read DTR1 should be 0x1B. Verify via `querybc 155` (QUERY DTR1) → 0x1B.
5. Send `querybc 197` again at DTR1 = 0x1B → expect **silence** (out-of-range, no backward frame).
6. Set DTR2 = 1 via `raw C501`, DTR1 = 0 via `raw C300`, send `querybc 197` → expect **silence** (bank 1 not implemented).
7. Verify QUERY DTR0 (152) returns the last value successfully read from bank 0 (= 0x00 for the index byte at 0x1A).

**Results:**
| Test | Expected | Actual | Status |
|---|---|---|---|
| Bank 0 byte 0x00 | 0x1A | — | — |
| Bank 0 byte 0x15 (101 version) | 0x08 | — | — |
| Bank 0 byte 0x16 (102 version) | 0x08 | — | — |
| Bank 0 byte 0x19 (gear units) | 0x01 | — | — |
| DTR1 post-increment after 27 reads | 0x1B | — | — |
| Read at DTR1 = 0x1B | Silent | — | — |
| Read at DTR2 = 1 | Silent | — | — |
| DTR0 mirrors last value | 0x00 | — | — |

**Notes:**
- GTIN and serial are zero placeholders. For production gear, override `DALI_GTIN_B0..5` and `DALI_SERIAL_B0..7` (in `hardware.h` or via `-D` flags) before flashing each unit.
- The byte layout in `dali_bank0.c` follows IEC 62386-102:2014 §4.3.10. A few field offsets shifted by one byte between -102:2009 and later editions; verify against the spec version your master expects.

---

## TC-13: TX Echo / Collision Detection (DALI PHY)

**Objective:** Verify `tx_collision_flag` is set when the bus level diverges from what the slave drove during a backward frame, and that the TX state machine releases the bus and aborts. Collision events are logged as `COLLISION` on the debug serial.

**Hardware requirement:** DALI PHY transceiver (open-drain, dominant-low bus) — the default firmware configuration. A second DALI device or test jig capable of pulling the bus active during the slave's backward frame is needed to provoke a collision.

**Procedure:**
1. Trigger a query that elicits a backward frame from the slave (e.g., `querybc 145` → expect 0xFF).
2. While the slave is mid-backward-frame, drive the bus dominant-low from a second device for ≥ 1 Te during a slot where the slave intends to drive idle (recessive).
3. Verify the slave's PC5 returns to idle (bus released) within 1 Te of the collision.
4. Read slave debug serial (COM11) — expect `COLLISION` printed once per event.
5. Re-issue the query — slave should respond normally (no latched error state).

**Results:**
| Test | Expected | Actual | Status |
|---|---|---|---|
| Bus released on collision | PC5 → idle within 1 Te | — | — |
| `COLLISION` printed on debug serial | Once per event | — | — |
| Subsequent query succeeds | Normal backward frame | — | — |

---

## Test Scripts Index

| Script | Purpose |
|---|---|
| `ch32fun_test.ps1` | Forward + backward + PWM test |
| `ch32fun_la_test.ps1` | LA signal verification |
| `ch32fun_assign_test.ps1` | Short address assignment with binary search |
| `ch32fun_dt8_test.ps1` | DT8 colour control (RGBW, Tc, queries) |
| `dali_timing_verify.ps1` | IEC 62386-101 timing compliance (Te, settle time) |
| `dali_logdim_test.ps1` | IEC 62386-102 logarithmic dimming verification |
| `dali_test.ps1` | Basic DALI forward frame communication test |
| `dali_dim_test.ps1` | Step through brightness levels (visual LED check) |
| `dali_blink.ps1` | 1 Hz blink via DALI broadcast (continuous) |
| `dali_query_test.ps1` | Test all DALI query commands (backward frames) |
| `dali_assign_test.ps1` | Short address assignment (Arduino firmware) |
| `la_dali_test.ps1` | LA capture of DALI + LED signals |
| `d0d1_check.ps1` | Verify D0/D1 signal independence |
| `la_pwm_check.ps1` | PWM duty cycle verification at 5 levels |
| `read_pico.ps1` | Read Pico serial output (COM9) |
| `read_ch32.ps1` | Read CH32 serial output (COM11) |
| `reset_and_read.ps1` | Reset CH32 via wlink + read serial |

---

## Known Issues

1. **First frame after reset** — Occasionally the very first DALI frame after power-up decodes incorrectly (e.g., 0x7E80 instead of 0xFE80). Subsequent frames are 100% correct.

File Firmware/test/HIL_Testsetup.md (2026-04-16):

# HIL Test Setup — DALI EVG (ch32fun)

## Overview

```
 PC
 ├── COM9  (Pico USB)  ── RP2040 DALI Master ──┐
 │                          GPIO17 (TX) ────100R────── PC0 (RX)   CH32V003 DALI EVG (DUT)
 │                          GPIO16 (RX) ────100R────── PC5 (TX)
 │                          GND ────────────────────── GND
 └── COM11 (WCH-Link)  ── CH32V003 serial debug (PD5 TX via WCH-Link UART)
                           + programming (SWD)
```

## Components

| Component | Details |
|---|---|
| **DALI Master** | Raspberry Pi Pico (RP2040), firmware: `DALI-Master/`, COM9 |
| **DALI Slave (DUT)** | CH32V003F4U6 WCH-Eval board, firmware: `Firmware/`, COM11 |
| **Programmer** | WCH-LinkE (CH32V305), provides SWD + UART + reset for CH32V003 |
| **Signal lines** | 2x 100R resistors on TX/RX lines (current limiting, no PHY) |
| **Logic Analyzer** | Saleae clone (fx2lafw), sigrok-cli at `N:\Programme\sigrok\sigrok-cli\sigrok-cli.exe`, 500 kHz single-ch / 100 kHz multi-ch (CSV bottleneck) |

## CH32V003F4U6 Pinout (TSSOP-20)

```
                        CH32V003F4U6 (TSSOP-20)
                     ┌────────┴────────┐
                     │                 │
     (USB D+)    PD4 │ 1            20 │ PD3    (USB D-)
     UART TX     PD5 │ 2            19 │ PD2    LED1 (R) TIM1_CH1
     (UART RX)   PD6 │ 3            18 │ PD1    SWDIO
     NRST        PD7 │ 4            17 │ PC7    Boot button (active low)
     LED2 (G)    PA1 │ 5            16 │ PC6    WS2812 data (SPI1_MOSI)
     PSU_CTRL    PA2 │ 6            15 │ PC5    DALI TX
     GND         VSS │ 7            14 │ PC4    LED4 (W) TIM1_CH4
     USB DPU     PD0 │ 8            13 │ PC3    LED3 (B) TIM1_CH3
     VDD     3.3/5V  │ 9            12 │ PC2    I2C1_SCL (reserved)
     DALI RX     PC0 │10            11 │ PC1    I2C1_SDA (reserved)
                     │                 │
                     └─────────────────┘

  External connections:
     PC0 (pin 10) ──100R── Pico GPIO17 (master TX)
     PC5 (pin 15) ──100R── Pico GPIO16 (master RX)
     PD5 (pin  2) ──────── WCH-LinkE UART bridge
     PD1 (pin 18) ──────── WCH-LinkE SWDIO

  Free GPIOs:  PD6 (+ PD3, PD4 when USB not in use)
  Clock:       48 MHz from internal 24 MHz HSI + PLL (no crystal)
```

## Pin Mapping

| Signal | Master (Pico) | Slave (CH32V003) | LA Channel | Notes |
|---|---|---|---|---|
| DALI TX→RX | GPIO17 | PC0 (EXTI0) | D0 | Master TX to slave RX, 100R series |
| DALI RX←TX | GPIO16 | PC5 (GPIO) | D1 | Slave backward frame to master RX, 100R series |
| LED PWM 1 (R) | -- | PD2 (TIM1_CH1) | D4 | 20 kHz PWM, 2400 steps |
| LED PWM 2 (G) | -- | PA1 (TIM1_CH2) | D5 | 20 kHz PWM, 2400 steps |
| LED PWM 3 (B) | -- | PC3 (TIM1_CH3) | D6 | 20 kHz PWM, 2400 steps |
| LED PWM 4 (W) | -- | PC4 (TIM1_CH4) | D7 | 20 kHz PWM, 2400 steps |
| PSU control | -- | PA2 (GPIO) | D3 | HIGH when any channel on |
| WS2812 data | -- | PC6 (SPI1_MOSI) | -- | Alt to PWM via `#define DIGITAL_LED_OUT` |
| Boot button | -- | PC7 (input, pull-up) | -- | Active low, enters bootloader |
| USB D+ | -- | PD4 | -- | USB bootloader only |
| USB D- | -- | PD3 | -- | USB bootloader only |
| USB DPU | -- | PD0 (output) | -- | USB D+ pull-up, driven by bootloader |
| I2C SDA | -- | PC1 (I2C1_SDA) | -- | Reserved for EEPROM |
| I2C SCL | -- | PC2 (I2C1_SCL) | -- | Reserved for EEPROM |
| GND | GND | GND | -- | Common ground required |
| Debug serial | -- | PD5 (USART1_TX) | -- | Via WCH-Link UART bridge, 115200 baud |

## GPIO Inversion (No PHY)

Direct GPIO-to-GPIO connection without DALI transceiver. The master firmware applies pad-level inversion for correct polarity:

```cpp
// In DALI-Master/include/hardware.h:
#define DALI_NO_PHY
```

Remove `#define DALI_NO_PHY` when switching to a real DALI bus with transceiver.

## Test Commands (via COM9 serial at 115200 baud)

```
broadcast <level>          Set all devices to level (0-254)
arc <addr> <level>         Set short address to level
on <addr>                  Recall max level
off <addr>                 Turn off
query <addr> <cmd>         Query command (waits for backward frame)
querybc <cmd>              Query broadcast command
scan                       Scan addresses 0-63
initialise <param>         INITIALISE (0=unaddressed, 0xFF=all)
randomise                  RANDOMISE
searchaddr <H> <M> <L>    Set search address
compare                    COMPARE (expect YES)
setaddr <addr>             PROGRAM SHORT ADDRESS
withdraw                   WITHDRAW
terminate                  TERMINATE
assign <addr>              Auto-assign address (single device)
raw <hex16>                Send raw 16-bit DALI frame
help                       Show all commands
```

## Flashing

```bash
# Pico (auto-detects COM9, reboots to BOOTSEL):
cd DALI-Master && pio run -t upload

# CH32V003 (via WCH-Link):
wlink.exe flash Firmware/.pio/build/genericCH32V003F4U6/firmware.bin

# CH32V003 (via DALI bus bootloader):
cd DALI_Bootloader && powershell -ExecutionPolicy Bypass -File dali_upload.ps1
```

## Firmware Info

| Property | Value |
|---|---|
| Framework | ch32fun (cnlohr/ch32fun) |
| Flash | 9,712 B (59.3% of 16 KB) |
| RAM | 136 B (6.6% of 2 KB) |
| Clock | 48 MHz (HSI + PLL) |
| PWM channels | 4 (configurable via `PWM_NUM_CHANNELS`) |
| Dimming curve | IEC 62386-102 §9.3 logarithmic |
| UART | 115200 baud on PD5 (printf via ch32fun UARTPRINTF) |
| NVM | Last 64-byte flash page (0x08003FC0), deferred 5s write |

## Helper Scripts (in `Debug_Helpers/`)

| Script | Purpose |
|---|---|
| `ch32fun_test.ps1` | Forward + backward + PWM test |
| `ch32fun_assign_test.ps1` | Short address assignment test |
| `ch32fun_compliance_test.ps1` | DALI-1/2 compliance (min/max, scenes, groups, RESET, DTR) |
| `ch32fun_nvm_test.ps1` | NVM flash persistence (config, reset via wlink, verify) |
| `ch32fun_newcmd_test.ps1` | New commands test (queries 146-149, status flags, cmd 48) |
| `ch32fun_dt8_test.ps1` | DT8 colour control (RGBW, Tc, queries) |
| `ch32fun_la_test.ps1` | LA signal verification |
| `dali_timing_verify.ps1` | IEC 62386-101 timing compliance |
| `dali_logdim_test.ps1` | IEC 62386-102 logarithmic dimming test |
| `la_channel_test.py` | LA channel self-test (all 8 channels) |
| `la_pwm_duty.ps1` | LA PWM duty cycle measurement (D4–D7, per-channel) |
| `la_pwm_test.ps1` | LA PWM edge detection (D4–D7, per-channel) |
| `read_pico.ps1` | Read Pico serial (COM9) |
| `read_ch32.ps1` | Read CH32 serial (COM11) |
| `reset_and_read.ps1` | Reset CH32 via wlink + read serial |

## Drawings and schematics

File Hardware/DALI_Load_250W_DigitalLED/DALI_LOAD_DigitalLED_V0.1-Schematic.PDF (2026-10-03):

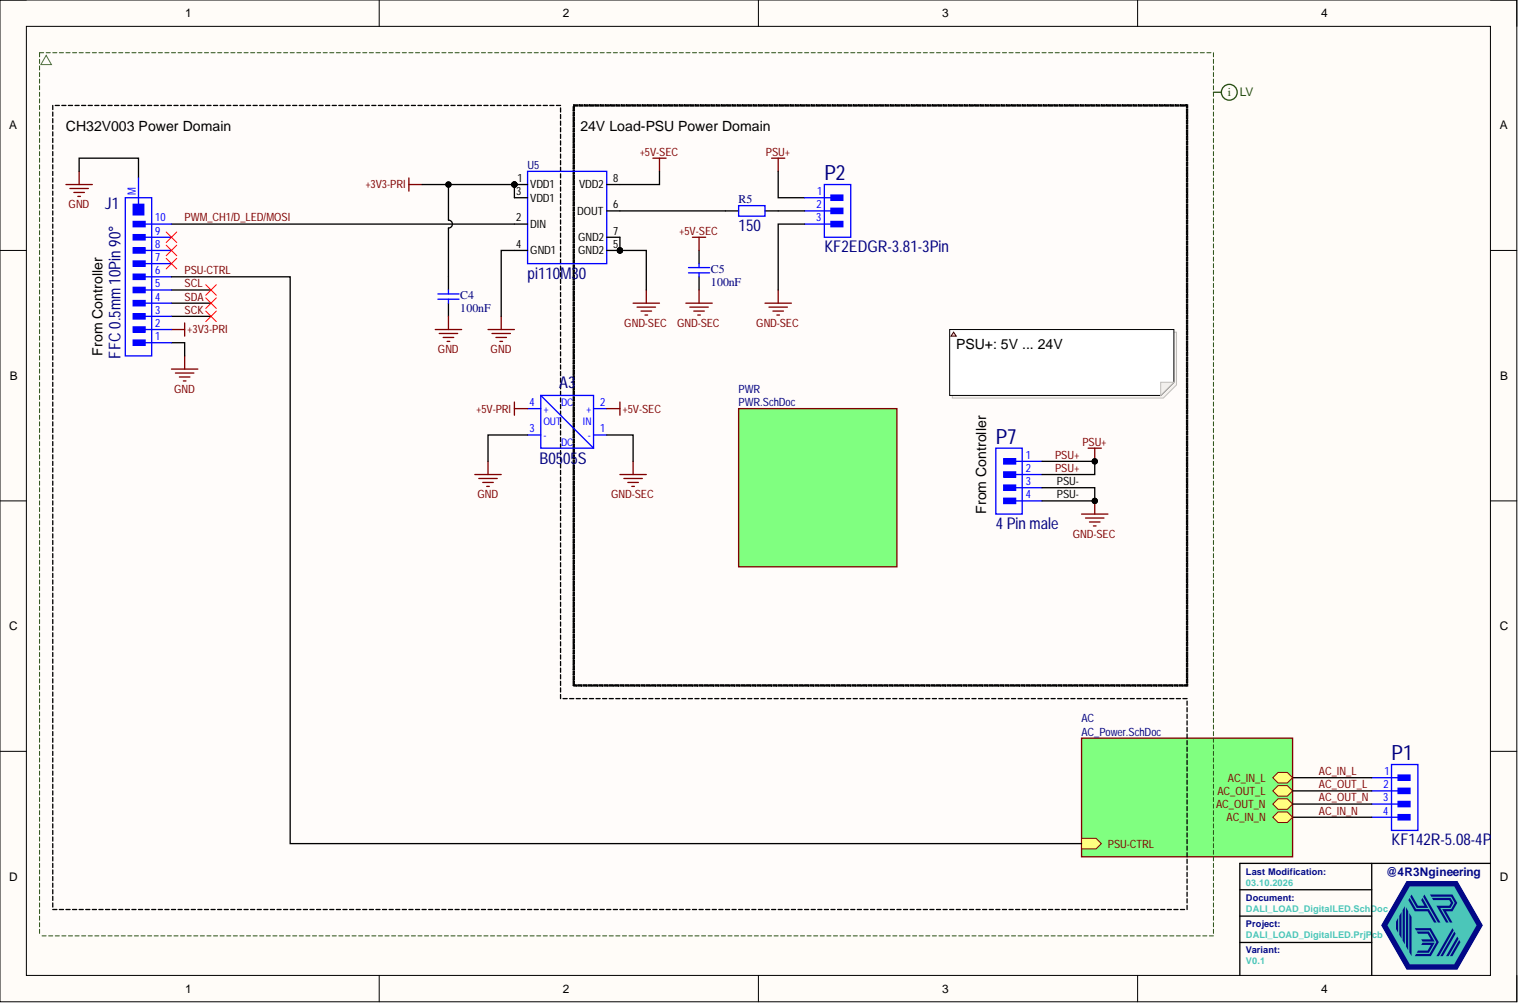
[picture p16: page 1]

VDD1 3

9 PSU-CTRL | GND1 4

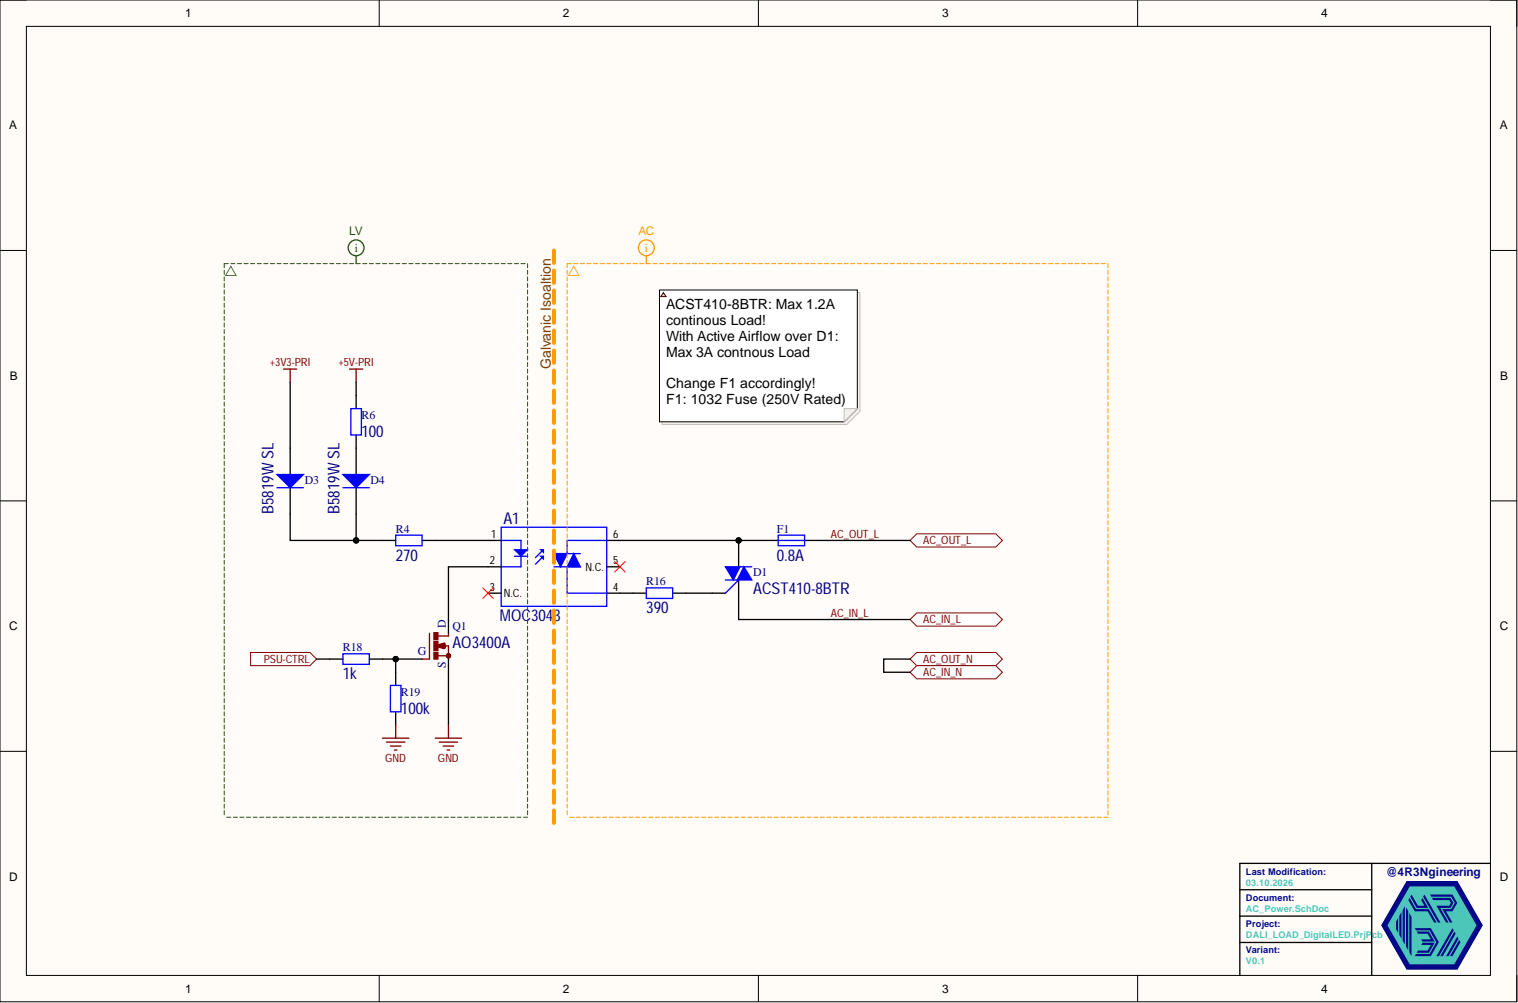
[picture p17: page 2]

Change F1 accordingly! F1: 1032 Fuse (250V Rated)

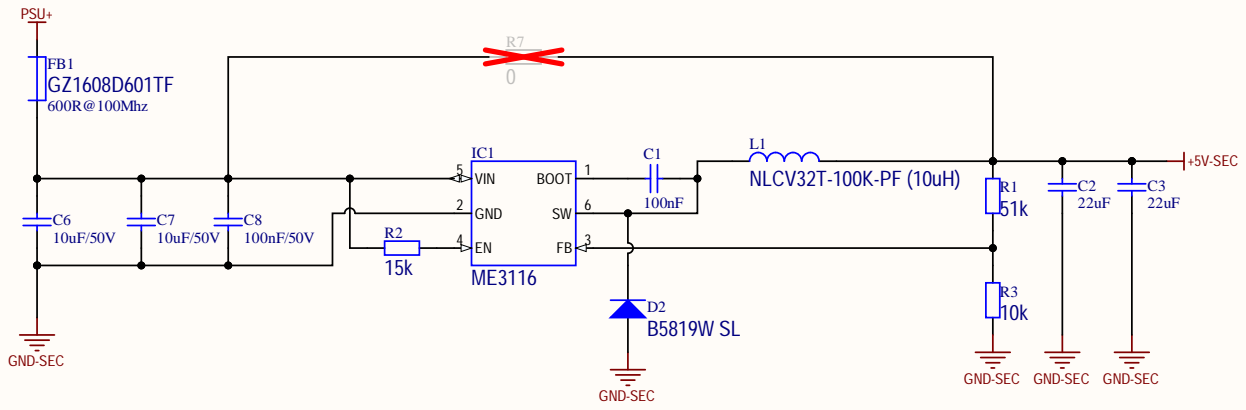
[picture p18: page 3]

IC1 | | L 1
VIN | SW FB | 1 3 EN

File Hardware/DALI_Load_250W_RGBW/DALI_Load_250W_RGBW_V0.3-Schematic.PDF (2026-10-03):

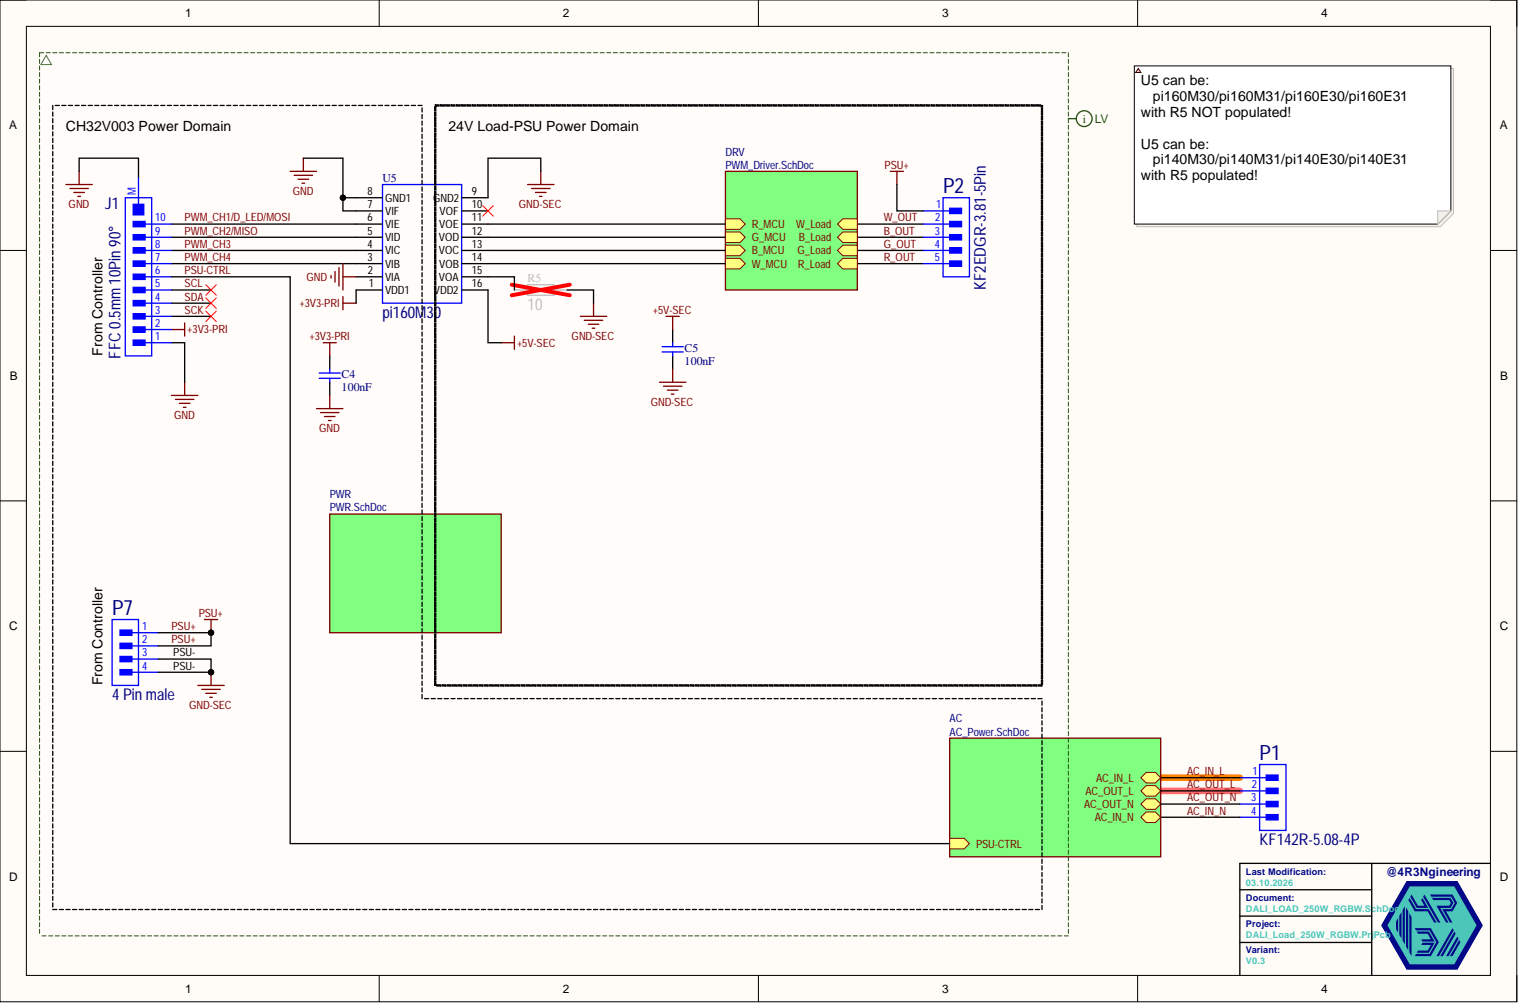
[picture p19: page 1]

PWM_C H 3 | G_O U T
PWM_C H 4 | R_O U T

From Controller

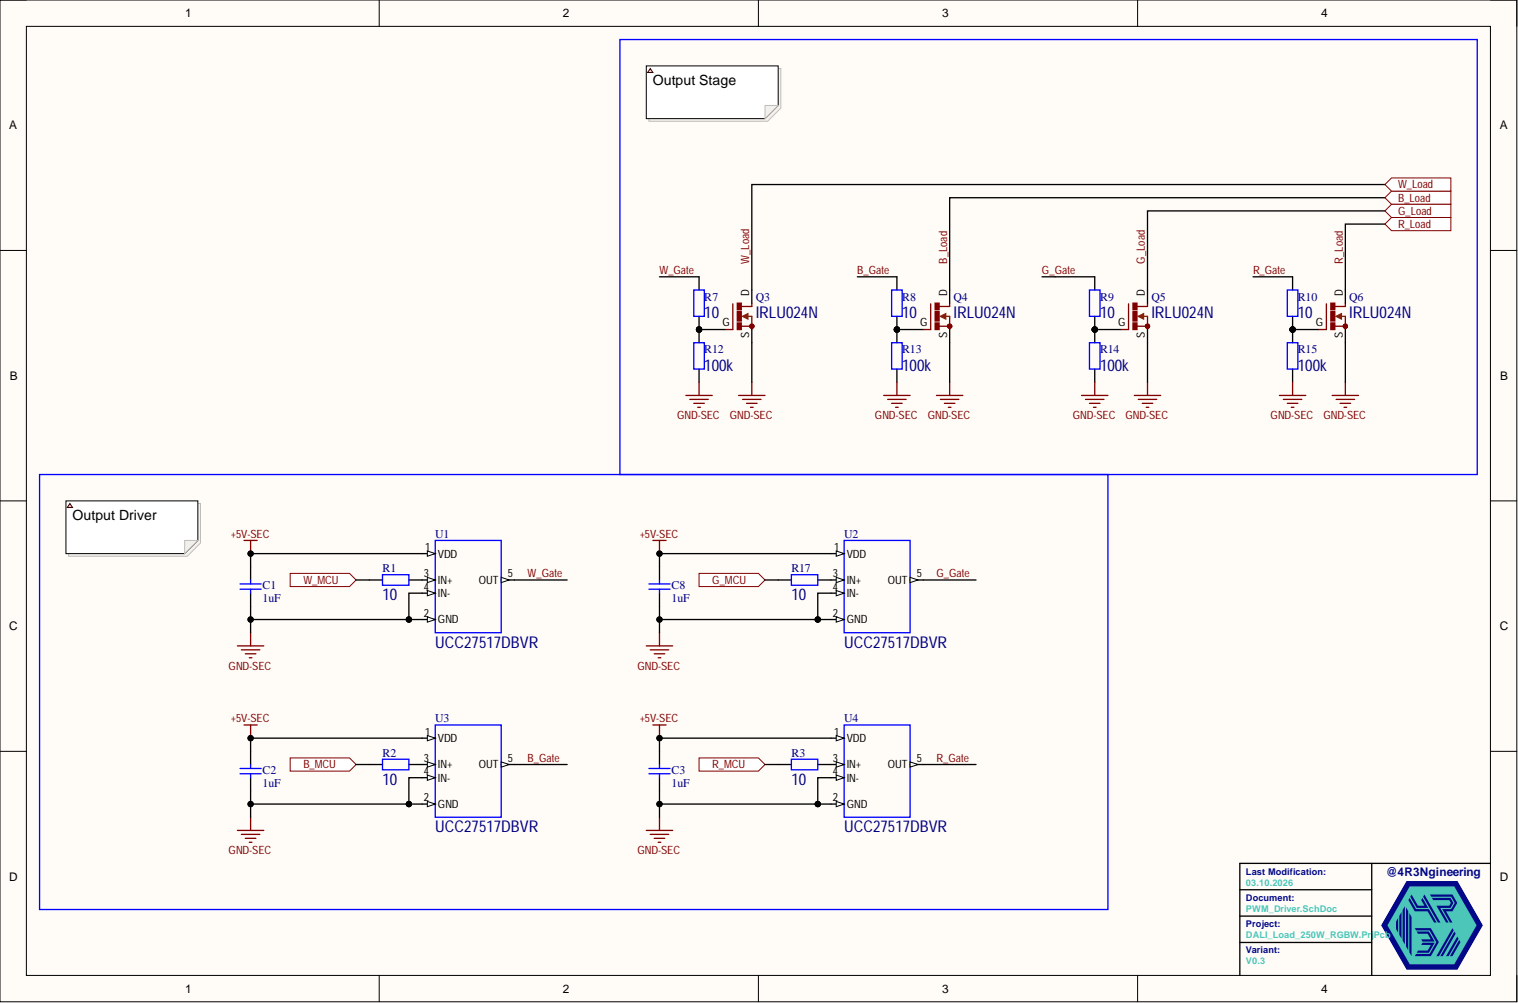
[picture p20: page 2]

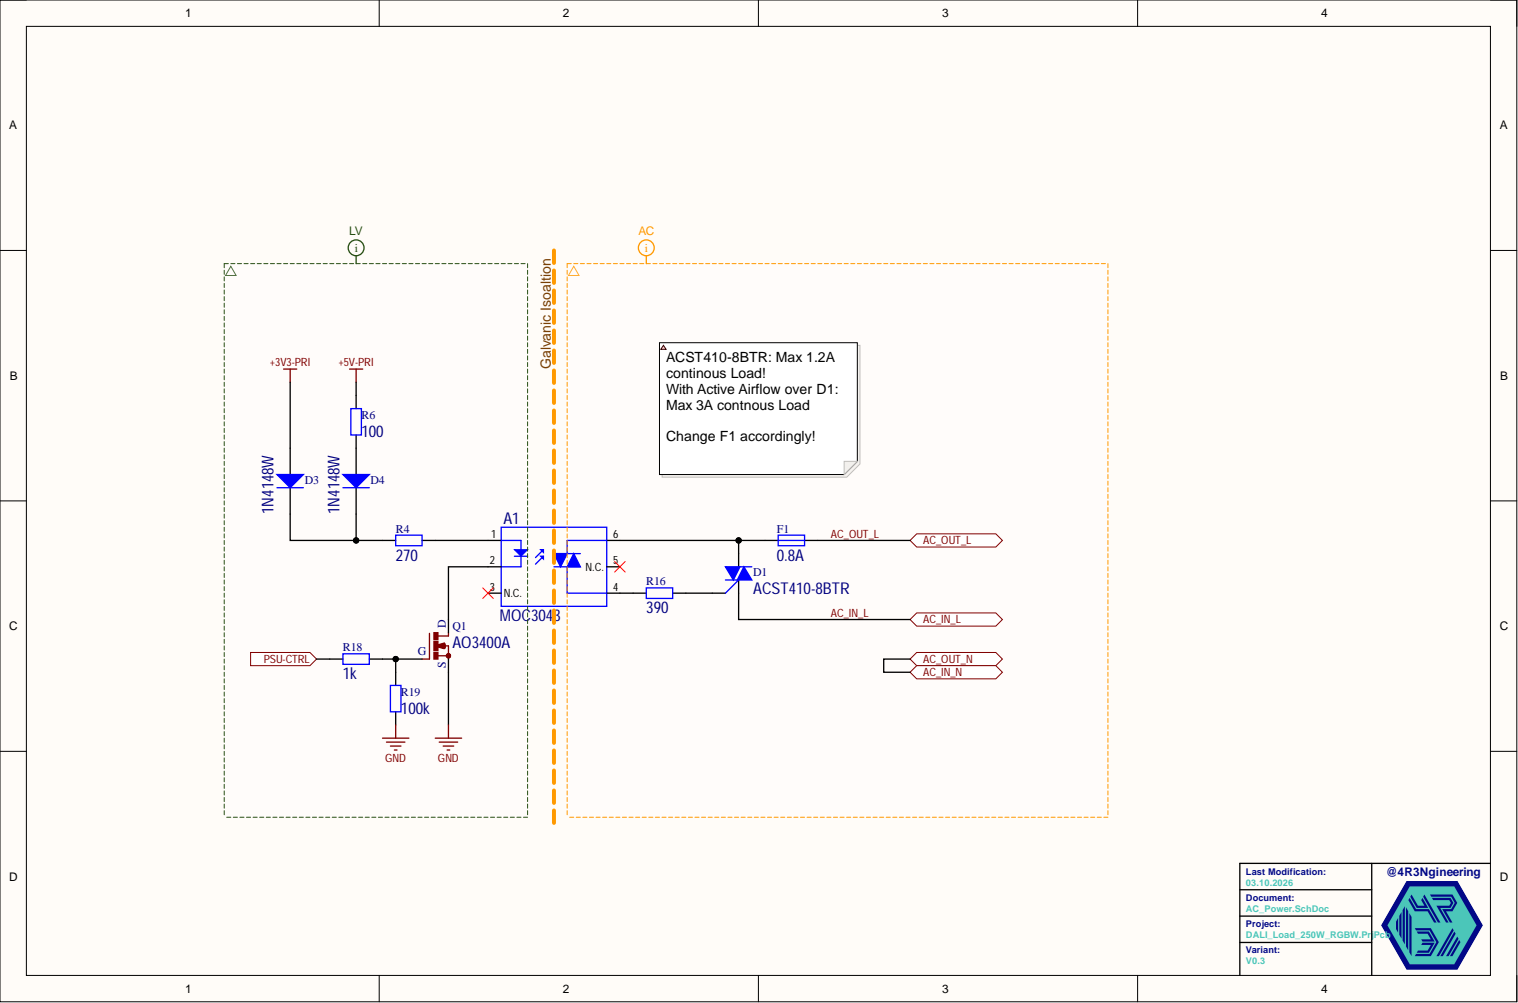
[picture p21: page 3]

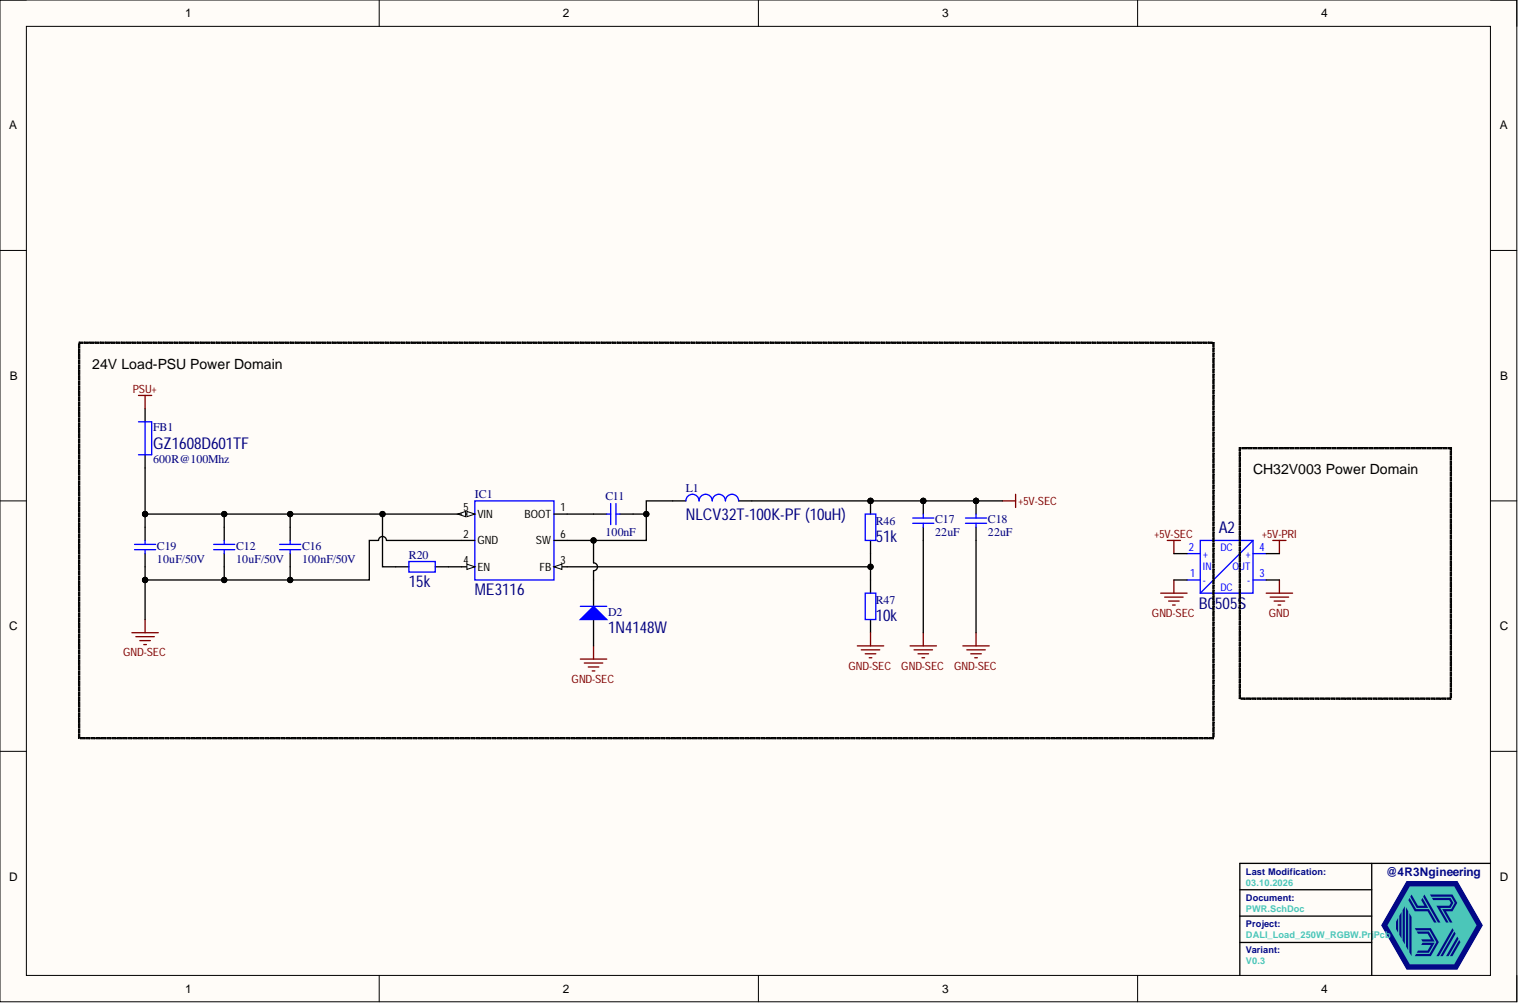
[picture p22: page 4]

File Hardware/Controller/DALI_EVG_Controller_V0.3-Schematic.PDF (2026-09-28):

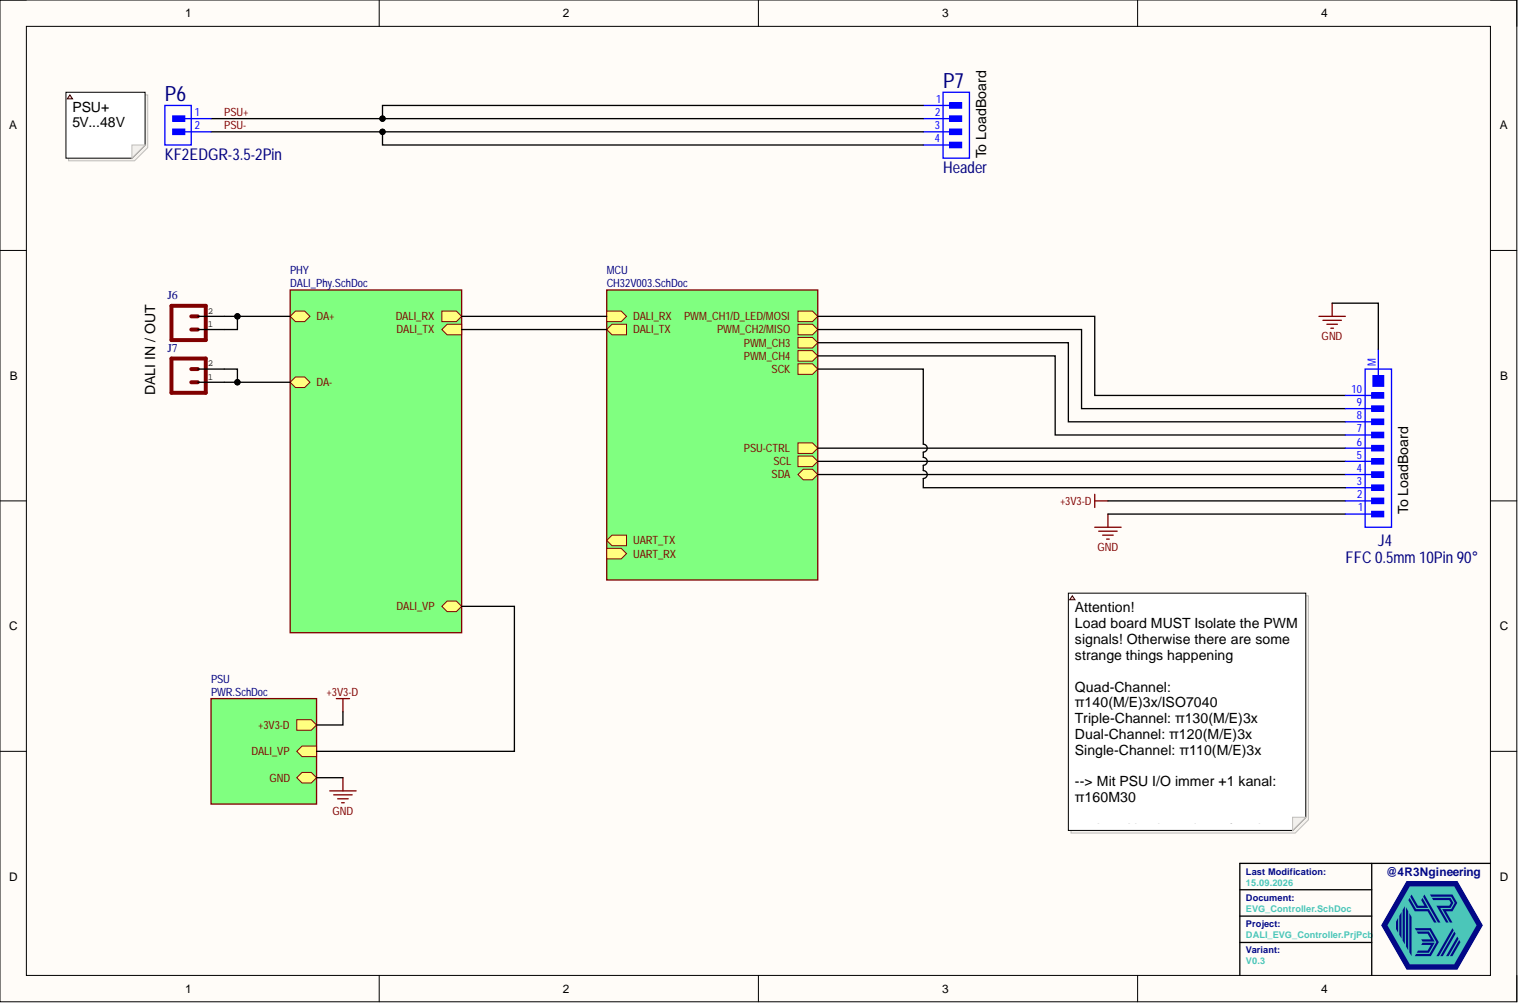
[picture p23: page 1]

Attention!
Load board MUS
signals! Otherwise there are some
strange things happening

Quad-Channel: π140(M/E)3x/ISO7040 Triple-Channel: π130(M/E

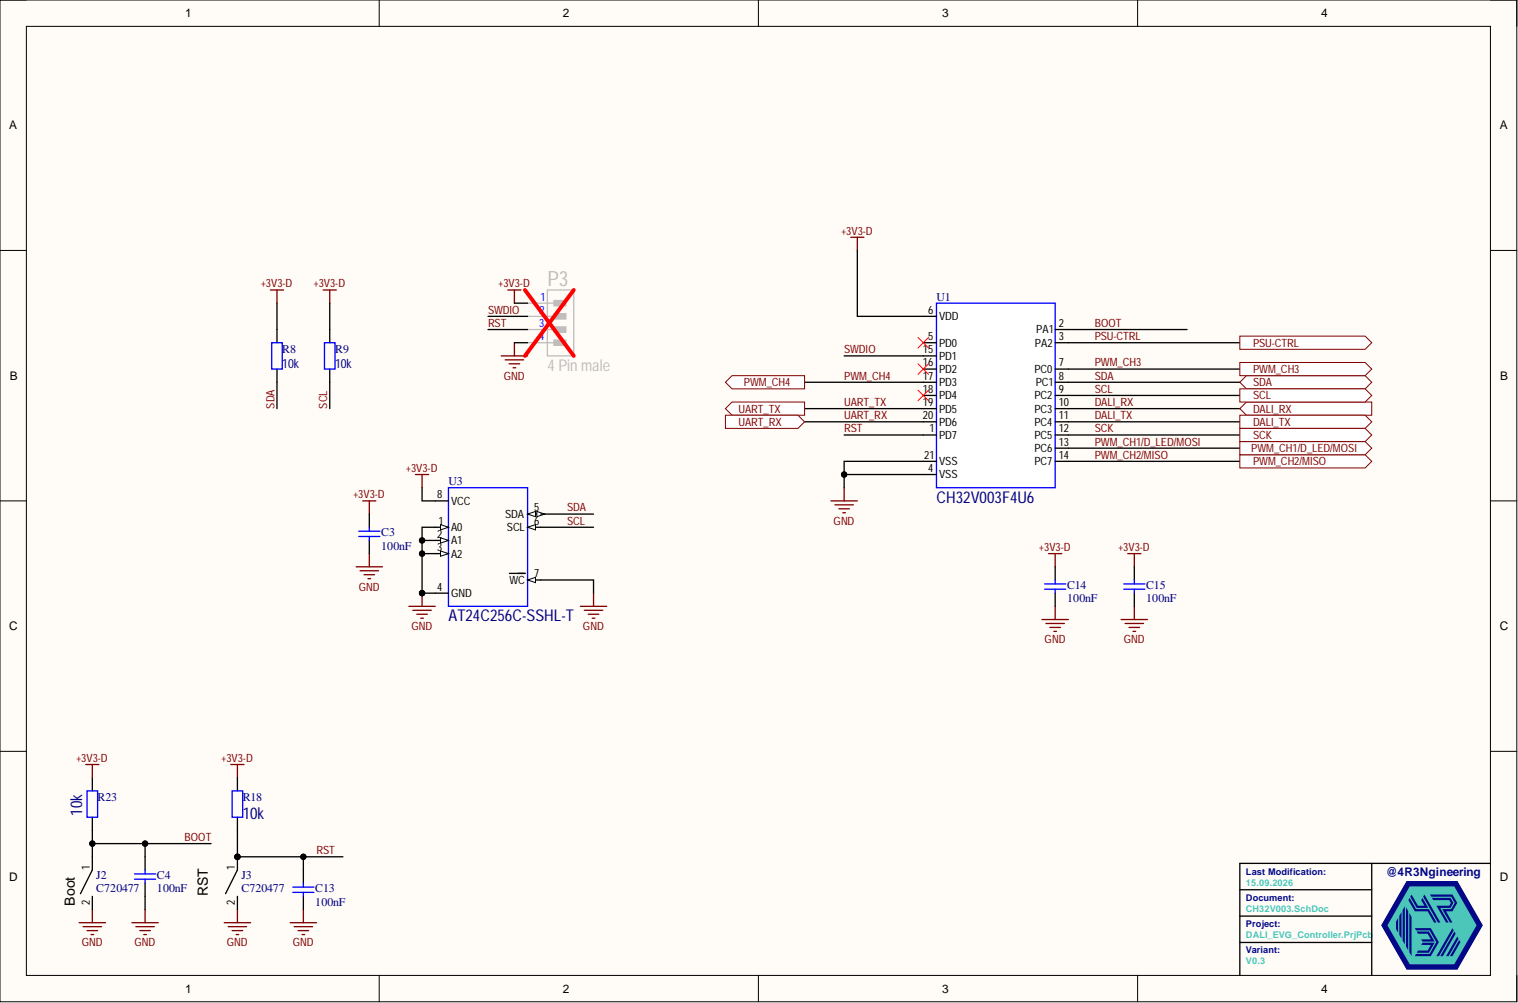
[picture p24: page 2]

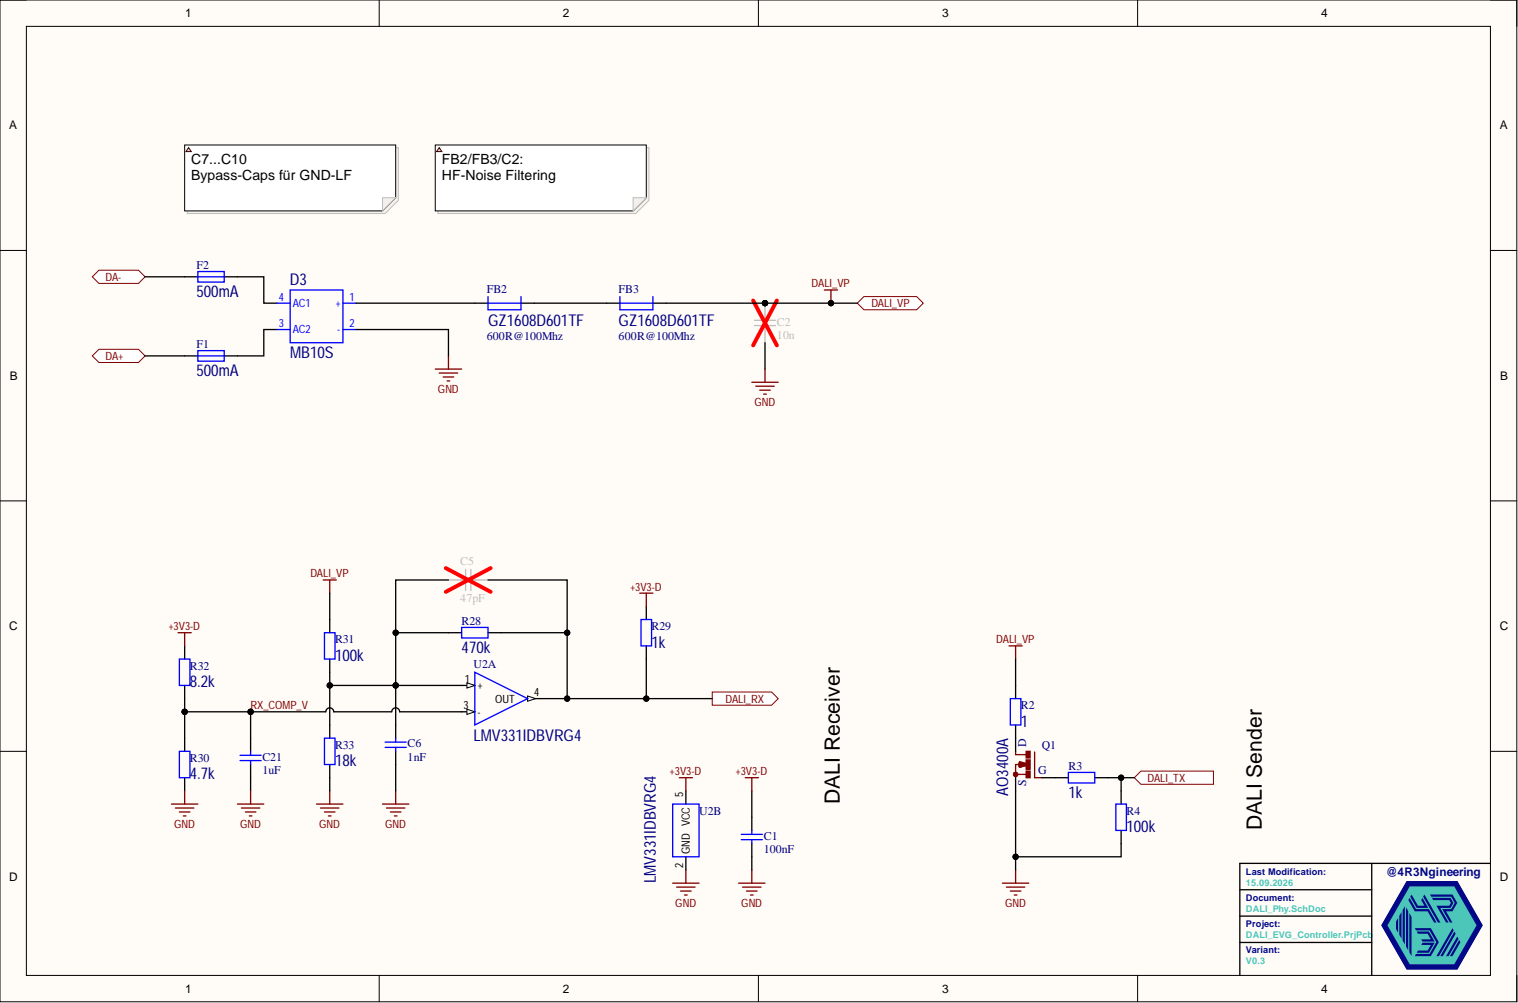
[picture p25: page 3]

Bypass-Caps für GND-LF

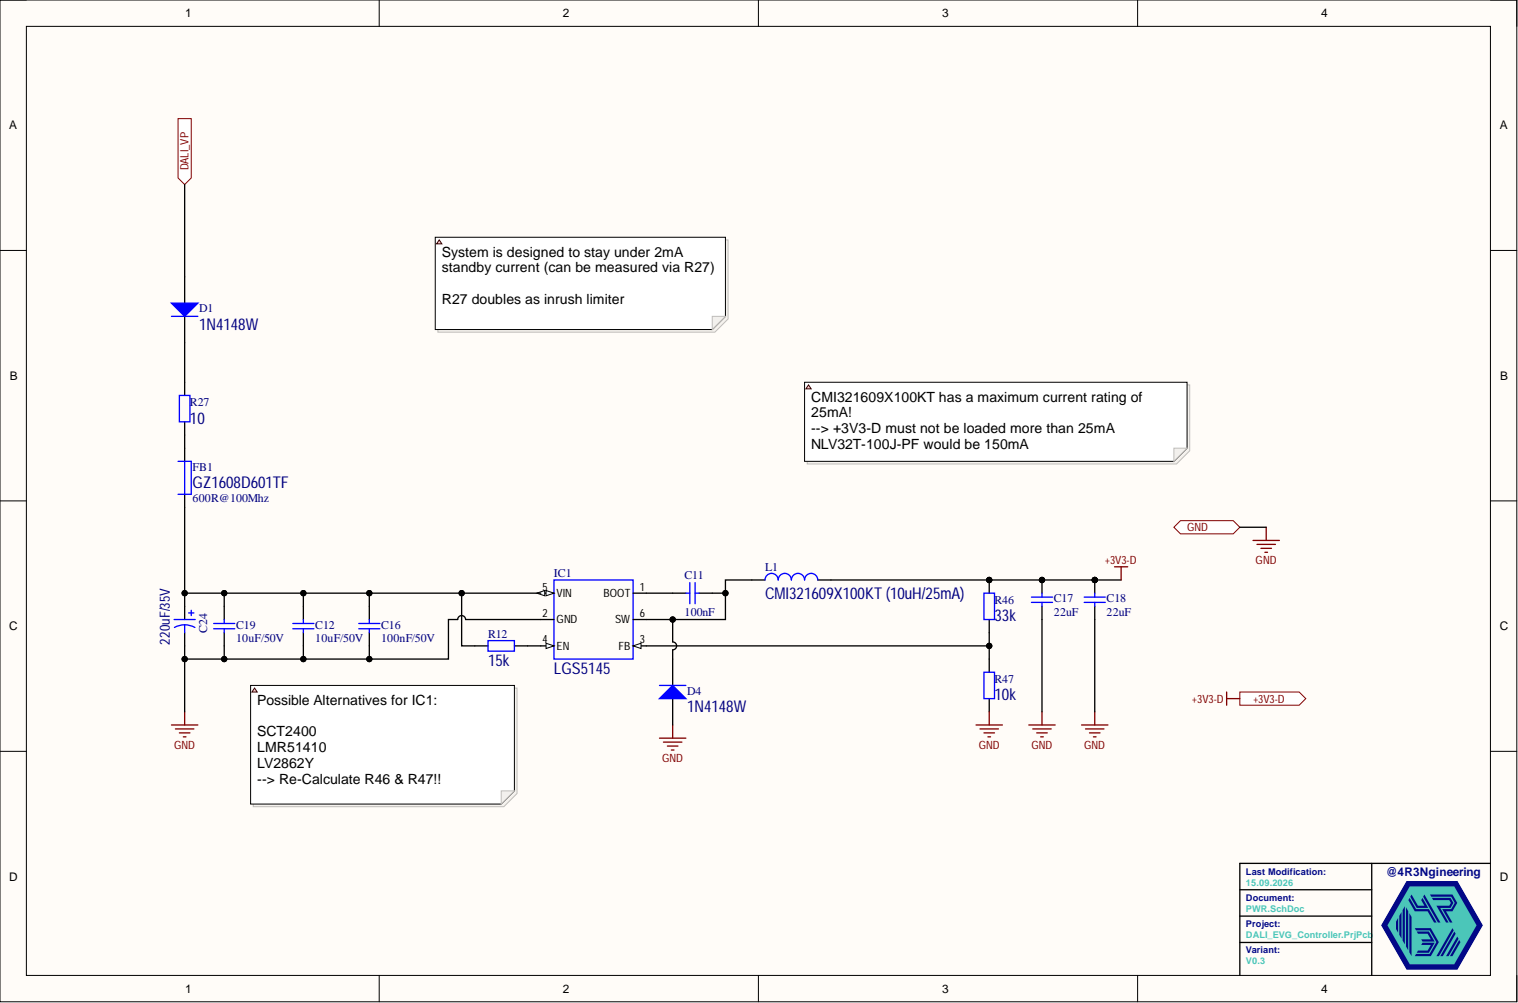
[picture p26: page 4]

System is designed to stay under 2m
standby cur

rent (can be measured via R27)

R27 doubles as inrush limiter

-> +3V3-D must not be loaded more than 25m

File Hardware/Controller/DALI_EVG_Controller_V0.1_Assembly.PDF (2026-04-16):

A

B

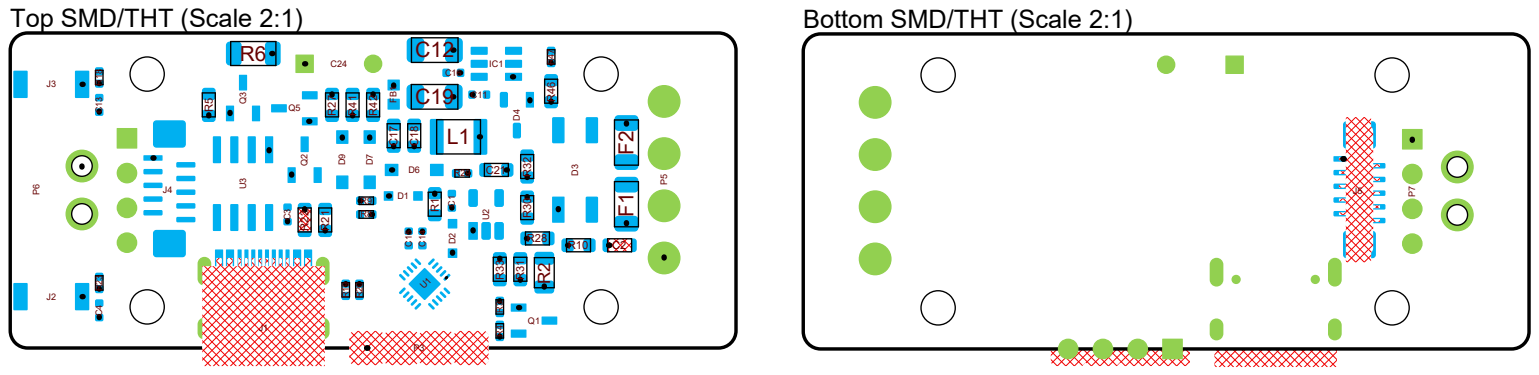
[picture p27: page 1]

Top SMD/THT (Scale 2:1)

Bottom SMD/THT (Scale 2:1)

1 | 1


1 | 1


1 | 1

# Realistic View


2 | 2
3 | 3
4 | 4
Last Modification: | @4R3Ngineering
12.04.2026
Document:
Board Assembly.PCBDwf

# Realistic View

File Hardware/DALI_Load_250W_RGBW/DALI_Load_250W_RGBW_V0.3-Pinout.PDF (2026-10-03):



View from Top side (Scale 2.7099:1)

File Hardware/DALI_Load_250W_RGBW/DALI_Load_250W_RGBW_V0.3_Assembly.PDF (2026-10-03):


Top SMD/THT (Scale 2:1) D1

Bottom SMD/THT (Scale 2:1)




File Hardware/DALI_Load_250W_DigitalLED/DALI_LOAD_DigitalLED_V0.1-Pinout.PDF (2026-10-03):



View from Top side (Scale 2.7099:1)

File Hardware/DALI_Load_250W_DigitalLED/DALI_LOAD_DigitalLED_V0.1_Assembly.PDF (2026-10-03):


Top SMD/THT (Scale 2:1) D1

Bottom SMD/THT (Scale 2:1)




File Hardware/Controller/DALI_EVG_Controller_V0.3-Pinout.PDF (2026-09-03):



View from Front side (Scale 4:1)

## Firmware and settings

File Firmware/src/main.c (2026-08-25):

/*
    main.c - DALI EVG firmware entry point (ch32fun framework)

    This file contains:
    - millis() implementation via SysTick (ch32fun has no built-in millis)
    - PSU control (PA2) for external power supply enable/disable
    - ISR wrappers for DALI RX (EXTI3) and TX/idle (TIM2 CH2/CH4)
    - Main loop calling dali_protocol_process(), dali_fade_tick(), nvm_tick()

    LED output is handled by led_driver.c, selected at compile time
    via EVG_MODE in hardware.h (PWM or WS2812/SK6812).

    Architecture:
    ┌──────────────────────────────────────────────────────────────────┐
    │  main loop                                                       │
    │  ┌──────────┐   ┌──────────────────┐   ┌────────────────────┐   │
    │  │ millis() │   │ dali_protocol    │   │ on_level() callback│   │
    │  │ SysTick  │   │ _process()       │──>│ led_driver_apply() │   │
    │  └──────────┘   └──────────────────┘   └────────────────────┘   │
    │                        ↑                                         │
    │  ISRs:                 │                                         │
    │  ┌─────────────────────┴──────────────────────────────────────┐  │
    │  │ EXTI7_0  → dali_isr_rx_edge()    (Manchester edge decode) │  │
    │  │ TIM2 CC2 → dali_isr_tx_tick()    (backward frame gen)     │  │
    │  │ TIM2 CC4 → dali_isr_idle_timeout() (frame-complete detect)│  │
    │  └───────────────────────────────────────────────────────────┘   │
    └──────────────────────────────────────────────────────────────────┘
*/

#include "ch32fun.h"
#include <stdio.h>
#include "config/hardware.h"
#include "logger.h"
#include "dali/phy/dali_phy.h"
#include "dali/protocol/dali_protocol.h"
#include "dali/protocol/dali_fade.h"
#include "dali/dali_state.h"
#include "dali/nvm/dali_nvm.h"
#include "eeprom/eeprom.h"
#include "led/led_driver.h"

/* LED re-send interval in ms; override with -DLED_REFRESH_MS=<n>.
 * Only the digital LED drivers actually re-send (PWM is a no-op), so this
 * is purely a recovery mechanism against electrical glitches — 1 s is
 * plenty and keeps the bus-powered device asleep far more of the time. */
#ifndef LED_REFRESH_MS
#define LED_REFRESH_MS 1000
#endif

/* ====================================================================
 * millis() — Millisecond counter via SysTick
 * ====================================================================
 * ch32fun does not provide a millis() function. We implement one using
 * the SysTick timer, which counts down from CMP to zero and generates
 * an interrupt on each underflow. At 48 MHz, CMP = 47999 gives a
 * precise 1 ms tick. The volatile counter is read by all modules via
 * the extern millis() declaration.
 * ==================================================================== */
static volatile uint32_t ms_ticks = 0;

/* SysTick ISR — fires every 1 ms, increments the global tick counter.
 * __attribute__((interrupt)) is required on CH32V003 for correct
 * RISC-V hardware stacking (mret vs ret).
 *
 * Without auto-reload, we must advance CMP by the period each tick
 * so the next compare match fires 1 ms later. The CNT register is
 * free-running (never resets), so CMP accumulates. */
void SysTick_Handler(void) __attribute__((interrupt));
void SysTick_Handler(void) {
    SysTick->SR = 0;        /* Clear the compare-match flag */
    SysTick->CMP += (FUNCONF_SYSTEM_CORE_CLOCK / 8 / 1000);  /* Next match in 6000 ticks */
    ms_ticks++;
}

/* Returns the number of milliseconds since boot. Wraps after ~49 days.
 * Thread-safe: 32-bit aligned read is atomic on RISC-V. */
uint32_t millis(void) {
    return ms_ticks;
}

/* Configure SysTick for 1 ms interrupts.
 * Uses auto-reload mode (STRE=1) with HCLK/8 source to stay compatible
 * with ch32fun's DelaySysTick/Delay_Ms which expects a free-running
 * HCLK/8 counter.
 *
 * CTLR bits: 0=STE(enable), 1=STIE(irq), 2=STCLK(0=HCLK/8), 3=STRE(auto-reload)
 * HCLK/8 = 6 MHz → CMP = 5999 for 1 ms period.
 *
 * NOTE: We must NOT set STCLK=1 (HCLK) here because FUNCONF_SYSTICK_USE_HCLK
 * is 0 (default), so Delay_Ms() computes tick counts assuming HCLK/8 = 6 MHz.
 * Setting STCLK=1 would make the counter run 8x faster than Delay_Ms expects.
 *
 * Auto-reload (STRE=1) is safe because CMP = 5999 and Delay_Ms(5) needs
 * only 30000 ticks which exceeds the CMP reload boundary. We must therefore
 * NOT use auto-reload — it would wrap CNT at 5999, breaking DelaySysTick
 * for any delay > 1 ms.
 *
 * Solution: Use HCLK/8 free-running counter (STRE=0, STCLK=0) with compare
 * interrupt. CNT counts 0→2^32, CMP triggers IRQ every 6000 ticks, but we
 * must update CMP each ISR to fire again (since no auto-reload).
 */
static void millis_init(void) {
    SysTick->CNT  = 0;
    SysTick->CMP  = (FUNCONF_SYSTEM_CORE_CLOCK / 8 / 1000) - 1;  /* 6MHz / 1000 - 1 = 5999 */
    SysTick->SR   = 0;             /* Clear pending flag */
    SysTick->CTLR = 0x3;           /* STE + STIE, HCLK/8, no auto-reload */
    NVIC_EnableIRQ(SysTick_IRQn);
}

/* ====================================================================
 * PSU Control — Enable/disable external power supply
 * ====================================================================
 * PA2 is a push-pull GPIO output that controls an external FET or relay
 * powering the LED driver stage. HIGH = PSU on, LOW = PSU off.
 * The PSU turns on when any DALI channel has a non-zero level, and
 * turns off immediately when all channels reach zero (no delay).
 * ==================================================================== */

/* Configure PA2 as push-pull output, initially LOW (PSU off). */
static void psu_ctrl_init(void) {
    RCC->APB2PCENR |= RCC_APB2Periph_GPIOA;    /* Enable GPIOA clock */
    /* Set PA2 to push-pull output, 10 MHz drive strength */
    PSU_CTRL_PORT->CFGLR = (PSU_CTRL_PORT->CFGLR & ~(0xF << (PSU_CTRL_PIN_N * 4)))
                         | ((GPIO_Speed_10MHz | GPIO_CNF_OUT_PP) << (PSU_CTRL_PIN_N * 4));
    PSU_CTRL_PORT->BCR = (1 << PSU_CTRL_PIN_N); /* BCR = bit clear → LOW */
}

/* Set PSU state. Uses atomic BSHR (bit set) / BCR (bit clear) registers
 * for glitch-free single-cycle GPIO writes. */
static inline void psu_ctrl_set(uint8_t on) {
    if (on)
        PSU_CTRL_PORT->BSHR = (1 << PSU_CTRL_PIN_N);   /* HIGH = PSU on */
    else
        PSU_CTRL_PORT->BCR  = (1 << PSU_CTRL_PIN_N);    /* LOW  = PSU off */
}

/* ====================================================================
 * USB Enumeration Pin — Deassert bootloader pull-up
 * ====================================================================
 * The USB bootloader drives PD0 HIGH to pull up USB D+ for host
 * enumeration. After jumping to firmware, we must deassert this
 * pull-up so the host doesn't see a phantom USB device.
 * Configure PD0 as input with pull-down (ODR=0 selects pull-down
 * when CNF=10 input-with-pull mode).
 * ==================================================================== */
static void usb_enum_init(void) {
    RCC->APB2PCENR |= RCC_APB2Periph_GPIOC;
    /* CNF=10 (input with pull-up/down), MODE=00 (input) = 0x8 */
    USB_ENUM_PORT->CFGLR = (USB_ENUM_PORT->CFGLR & ~(0xF << (USB_ENUM_PIN_N * 4)))
                         | (0x8 << (USB_ENUM_PIN_N * 4));
    USB_ENUM_PORT->BCR   = (1 << USB_ENUM_PIN_N);  /* ODR=0 → pull-down selected */
}

/* ====================================================================
 * DALI Arc Power Callback
 * ====================================================================
 * Called from dali_protocol_process() (main loop context) whenever the
 * DALI actual level changes — via DAPC, scenes, fade completion, OFF,
 * RECALL MAX/MIN, STEP UP/DOWN, etc.
 *
 * Responsibilities:
 * 1. Apply the new level + current colour to the LED driver (PWM or WS2812)
 * 2. Enable/disable the external PSU based on whether output is active
 * 3. Print debug output to serial (115200 baud on PD5)
 * ==================================================================== */
static void on_level(uint8_t level) {
    led_driver_apply(level, dali_protocol_get_colour_actual());
    uint8_t psu = (level > 0);
    psu_ctrl_set(psu);
    printf("LVL=%d PSU=%d\n", level, psu);
}

/* ====================================================================
 * DT8 Colour Callback
 * ====================================================================
 * Called from dali_protocol_process() when a DT8 ACTIVATE command
 * commits new colour values (RGBW channel levels or Tc conversion).
 * Recalculates LED output using the current arc level combined with
 * the new colour ratios. The arc level itself doesn't change here —
 * only the per-channel colour scaling is updated.
 * ==================================================================== */
static void on_colour(const uint8_t *levels, uint8_t count) {
    led_driver_apply(dali_protocol_get_actual_level(), dali_protocol_get_colour_actual());
    printf("CLR");
    for (uint8_t i = 0; i < count && i < 4; i++)
        printf(" %d", levels[i]);
    printf("\n");
}

/* ====================================================================
 * ISR Wrappers — Connect hardware interrupts to DALI PHY state machines
 * ====================================================================
 * CH32V003 has a shared EXTI7_0 handler for all EXTI lines 0-7.
 * We only use EXTI line 3 (PC3 = DALI RX pin).
 *
 * TIM2 has a single ISR for all channels. We check which channel
 * triggered (CC2 = TX tick, CC4 = idle timeout) and dispatch accordingly.
 * The flag is cleared by writing ~flag (inverted) to INTFR — this is
 * a CH32V003 quirk where INTFR bits are write-0-to-clear.
 * ==================================================================== */

/* EXTI line 3 — DALI RX edge on PC3 (via PHY transceiver).
 * Fires on every rising and falling edge of the DALI bus signal.
 * The PHY RX state machine timestamps each edge and decodes
 * Manchester-encoded forward frames (16-bit, 1200 baud). */
void EXTI7_0_IRQHandler(void) __attribute__((interrupt));
void EXTI7_0_IRQHandler(void) {
    EXTI->INTFR = DALI_RX_EXTI_LINE;   /* Clear EXTI pending flag */
    dali_isr_rx_edge();                 /* Run RX Manchester decoder */
}

/* TIM2 — DALI TX waveform generation + RX idle timeout detection.
 * Two output compare channels share this single ISR:
 *   CC2: TX Te tick — fires every 417 us during backward frame
 *         transmission, stepping the TX Manchester encoder state machine
 *   CC4: RX idle timeout — fires 5 Te (2085 us) after the last RX edge,
 *         signaling that the forward frame is complete (stop condition) */
void TIM2_IRQHandler(void) __attribute__((interrupt));
void TIM2_IRQHandler(void) {
    if (TIM2->INTFR & TIM_IT_CC2) {
        TIM2->INTFR = ~TIM_IT_CC2;     /* Clear CC2 flag (write-0-to-clear) */
        dali_isr_tx_tick();             /* Step TX Manchester encoder */
    }
    if (TIM2->INTFR & TIM_IT_CC4) {
        TIM2->INTFR = ~TIM_IT_CC4;     /* Clear CC4 flag */
        dali_isr_idle_timeout();        /* Signal frame complete to protocol layer */
    }
}

/* ====================================================================
 * Main Entry Point
 * ====================================================================
 * Initialization order matters — each step depends on the previous:
 *   1. SystemInit()      — PLL: 24 MHz HSI → 48 MHz, flash wait states
 *   2. funGpioInitAll()  — Enable all GPIO port clocks (ch32fun helper)
 *   3. usb_enum_init()   — Deassert USB D+ pull-up from bootloader
 *   4. millis_init()     — SysTick 1 ms tick (needed by DALI timeouts)
 *   5. psu_ctrl_init()   — PSU enable GPIO (PA2), initially off
 *   6. led_driver_init() — LED output (TIM1 PWM or SPI+DMA for WS2812)
 *   7. dali_phy_init()   — TIM2 + EXTI3 for DALI Manchester RX/TX
 *   8. callbacks         — Connect DALI level/colour changes to LED driver
 *   9. eeprom_init()     — Initialize I2C1 for AT24C256 EEPROM
 *  10. nvm_init()        — Load persisted config from EEPROM + write identity block
 *  11. dali_power_on()   — Apply power-on level (from NVM or default 254)
 * ==================================================================== */
/* ====================================================================
 * Boot button (PA1) → DALI bootloader software-trigger
 * ====================================================================
 * The CH32V003 only re-evaluates option byte START_MODE on power-on
 * reset; NRST and SYSRESETREQ keep the runtime FLASH STATR bit 14
 * value, so a HW-reset-button press alone never enters the BL.
 *
 * Workaround: at every firmware boot, sample PA1. If it reads LOW
 * (button held), set FLASH STATR bit 14 and trigger SYSRESETREQ —
 * the BL then runs on the next reset and stays in update mode
 * because the user is still holding the button when the BL samples
 * it 1 ms later.
 * ==================================================================== */
static void boot_button_check(void) {
    /* PA1 = input with pull-up/down (CFG nibble 0x8), pull-up via BSHR */
    GPIOA->CFGLR = (GPIOA->CFGLR & ~(0xFu << (1 * 4))) | (0x8u << (1 * 4));
    GPIOA->BSHR  = (1 << 1);
    /* Short settle for the line + any external debounce cap */
    Delay_Ms(2);

    if ((GPIOA->INDR >> 1) & 1)
        return;                 /* button NOT pressed → continue normal boot */

    /* User-visible feedback before the silent reset. */
    printf("\n[BOOT] PA1 held -> entering DALI bootloader\n");
    Delay_Ms(50);               /* flush UART before reset */

    /* WCH SystemReset_StartMode(Start_Mode_BOOT) — same sequence as the
     * DALI START FW TRANSFER handler in dali_protocol.c. Sets FLASH STATR
     * bit 14 and triggers SYSRESETREQ; the bootloader picks up the flag
     * and stays in update mode. */
    __disable_irq();
    FLASH->KEYR          = FLASH_KEY1;
    FLASH->KEYR          = FLASH_KEY2;
    FLASH->MODEKEYR      = FLASH_KEY1;
    FLASH->MODEKEYR      = FLASH_KEY2;
    FLASH->BOOT_MODEKEYR = FLASH_KEY1;
    FLASH->BOOT_MODEKEYR = FLASH_KEY2;
    FLASH->STATR &= ~(1 << 14);
    FLASH->STATR |=  (1 << 14);
    FLASH->CTLR = CR_LOCK_Set;
    PFIC->SCTLR = 1 << 31;
    while (1);
}

int main(void) {
    SystemInit();
    funGpioInitAll();

    boot_button_check();        /* if PA1 LOW → reset into bootloader */

    usb_enum_init();
    millis_init();
    psu_ctrl_init();
    led_driver_init();
    dali_phy_init();
    dali_protocol_set_arc_callback(on_level);
    dali_protocol_set_colour_callback(on_colour);
    eeprom_init();
    nvm_init();
    dali_protocol_power_on();

    /* Print boot message with mode info (visible on debug serial PD5) */
    if (ds.short_address <= 63)
        printf("ADDR=%d\n", ds.short_address);
    else
        printf("ADDR=none\n");
#ifdef ONOFF_MODE
    printf("DALI %s DT%d ON/OFF ready\n", EVG_MODE_NAME, DALI_DEVICE_TYPE);
#elif defined(DIGITAL_LED_OUT)
    printf("DALI %s DT%d %d LEDs ready\n", EVG_MODE_NAME, DALI_DEVICE_TYPE, WS2812_NUM_LEDS);
#else
    printf("DALI %s DT%d %dch PWM ready\n", EVG_MODE_NAME, DALI_DEVICE_TYPE, PWM_NUM_CHANNELS);
#endif
    printf("Build: " __DATE__ " " __TIME__ "\n");

    uint32_t led_refresh_ms = 0;    /* Timestamp for periodic LED refresh */

    /* ── Main loop ─────────────────────────────────────────────────
     * Non-blocking cooperative loop. Each function returns quickly:
     *   - dali_protocol_process(): check for received frame, dispatch
     *   - dali_fade_tick(): step fade by one level if interval elapsed
     *   - nvm_tick(): save dirty config to flash after 5s debounce
     * Between bus activity, the CPU sleeps via __WFI() to save power.
     * ──────────────────────────────────────────────────────────────── */
    while (1) {
        dali_protocol_process();    /* Dispatch any received DALI frame */
        dali_fade_tick();           /* Advance running fades (if any) */
        nvm_tick();                 /* Deferred flash write (5s after last change) */

        /* Log bus collisions detected by the PHY during backward frame TX.
         * The PHY samples the bus each Te and aborts if another device
         * is pulling the line active while we drove idle (IEC 62386-101 §8.2.4.4).
         * Only functional with a real DALI PHY transceiver (open-drain bus). */
        if (dali_phy_consume_collision())
            LOG_PHY("COLLISION");

        /* Periodically re-send LED data to recover from electrical glitches.
         * For PWM mode this is a no-op (TIM1 hardware maintains duty cycle).
         * For WS2812/SK6812 mode this re-streams the colour data via SPI+DMA. */
        uint32_t now = millis();
        if (now - led_refresh_ms >= LED_REFRESH_MS) {
            led_refresh_ms = now;
            led_driver_refresh();
        }

        /* Enter sleep (WFI) when the DALI bus is idle to save power.
         * Only sleep when:
         *   1. No backward frame is being transmitted (TX idle)
         *   2. No RX activity in the last 20 ms (no frame in progress)
         * SysTick (1 ms) or EXTI3 (next DALI edge) will wake the CPU.
         * Do NOT use Standby (SLEEPDEEP=1) — that stops TIM2 and breaks
         * DALI edge timing.
         *
         * Sleep also stalls SPI1/DMA: measured on hardware, a WS2812 frame
         * sent while the core sleeps advances only ~2 halfwords per SysTick
         * tick and freezes MOSI at its current level for ~977 us in between,
         * shredding the bit stream. Hence the led_driver_busy() guard. */
        if (dali_phy_is_tx_idle() && (millis() - dali_phy_last_rx_edge_ms() > 20)
            && !led_driver_busy()) {
            __WFI();
        }
    }
}

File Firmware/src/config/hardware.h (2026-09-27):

/*
    hardware.h - Pin assignments for DALI EVG on CH32V003F4U6 (ch32fun)

    Physical wiring (with DALI PHY transceiver):
    ┌─────────────┐       ┌──────────┐       ┌──────────────────┐
    │ DALI Master │──bus──│ DALI PHY │       │ CH32V003 Slave   │
    │             │       │  RX_OUT ─┼───────┤ PC3 (RX, EXTI3)  │
    │             │       │  TX_IN  ─┼───────┤ PC4 (TX, GPIO)   │
    │             │       │  GND ────┼───────┤ GND              │
    └─────────────┘       └──────────┘       │ PC6 (TIM1_CH1) ──┤── LED1 / WS2812
    TIM1 Partial Remap 1 (RM=01):            │ PC7 (TIM1_CH2) ──┤── LED2 (PWM)
      CH1=PC6  CH2=PC7  CH3=PC0  CH4=PD3     │ PC0 (TIM1_CH3) ──┤── LED3 (PWM)
                                             │ PD3 (TIM1_CH4) ──┤── LED4 (PWM)
    PC6 dual-use: TIM1_CH1 (PWM modes)       │ PA2 (GPIO) ──────┤── PSU_CTRL
                  SPI1_MOSI (WS2812 modes)   │ PC1 (I2C1_SDA) ──┤── (EEPROM)
                                             │ PC2 (I2C1_SCL) ──┤── (EEPROM)
                                             │ PC5 ─────────────┤── (spare)
                                             │ PD5 (USART1_TX) ─┤── Debug TX
                                             │ PD6 (USART1_RX) ─┤── Debug RX
                                              └──────────────────┘

    Bus polarity (with PHY transceiver):
    - TX: HIGH = pull bus active (mark), LOW = release bus (idle)
    - RX: HIGH = bus active (mark), LOW = bus idle (space)
    - Manchester bit 1: active→idle = HIGH→LOW
    - Manchester bit 0: idle→active = LOW→HIGH
    - Bus collision detection: PHY open-drain allows readback during TX
*/
#ifndef _HARDWARE_H
#define _HARDWARE_H

/* ── EVG Mode Selection ────────────────────────────────────────────
   Define ONE of the following to select the LED output mode.
   All other configuration (DALI device type, channel count, driver
   selection, DT8 colour features) is derived automatically.

   On/off mode (no PWM, no timer — PSU_CTRL pin only):
     EVG_MODE_ONOFF       — 1 channel, relay/switch output (DT6)

   PWM modes (TIM1, up to 4 channels):
     EVG_MODE_SINGLE      — 1 channel, single-colour LEDs (DT6)
     EVG_MODE_CCT         — 2 channels, warm/cool white Tc control (DT8)
     EVG_MODE_RGB         — 3 channels, RGB LEDs (DT8, Tc + primary)
     EVG_MODE_RGBW        — 4 channels, RGBW LEDs (DT8, Tc + primary)

   Addressable LED modes (SPI1+DMA on PC6):
     EVG_MODE_WS2812      — WS2812 strip, 3 bytes/LED GRB (DT8)
     EVG_MODE_SK6812_RGB  — SK6812 strip, 3 bytes/LED GRB (DT8)
     EVG_MODE_SK6812_RGBW — SK6812 strip, 4 bytes/LED GRBW (DT8)

   Can also be set via compiler flag: -DEVG_MODE_RGBW
   ──────────────────────────────────────────────────────────────────── */

/* Default mode — override via -DEVG_MODE_xxx compiler flag */
#if !defined(EVG_MODE_ONOFF) && !defined(EVG_MODE_SINGLE) && !defined(EVG_MODE_CCT) \
 && !defined(EVG_MODE_RGB) && !defined(EVG_MODE_RGBW) && !defined(EVG_MODE_WS2812) \
 && !defined(EVG_MODE_SK6812_RGB) && !defined(EVG_MODE_SK6812_RGBW)
#define EVG_MODE_RGBW
#endif




/* WS2812 type constants (used by mode switch below) */
#define WS2812_TYPE_WS2812      0   /* 3 bytes GRB (WS2812, SK6812 RGB) */
#define WS2812_TYPE_SK6812_RGBW 1   /* 4 bytes GRBW (SK6812 RGBW) */

/* Wire byte order of the strip. Most WS2812/SK6812 are GRB; many older
   WS2811 strips expect RGB. Orthogonal to WS2812_TYPE, so it applies to the
   3-byte and the 4-byte variants alike. Override with -DWS2812_WIRE_ORDER_RGB=1 */
#ifndef WS2812_WIRE_ORDER_RGB
#define WS2812_WIRE_ORDER_RGB 0
#endif

/* ── Mode → derived configuration ─────────────────────────────────
   DALI_DEVICE_TYPE:    6 (DT6 LED gear) or 8 (DT8 colour control)
   PWM_NUM_CHANNELS:    1–4 (PWM modes only)
   DIGITAL_LED_OUT:     defined for WS2812/SK6812 modes
   WS2812_TYPE:         byte format for digital LED modes
   EVG_NUM_COLOURS:     number of colour channels (1–4)
   EVG_HAS_DT8:         1 if DT8 extended commands are supported
   EVG_DT8_HAS_TC:      1 if colour temperature (Tc/mirek) is supported
   EVG_DT8_HAS_PRIMARY: 1 if RGBWAF primaries are supported
   ──────────────────────────────────────────────────────────────────── */
#if defined(EVG_MODE_ONOFF)
  #define EVG_MODE_NAME       "ONOFF"
  #define EVG_MODE_SERIAL     0x4F4E4F4646000000ULL  /* "ONOFF\0\0\0" */
  #define EVG_MODE_ID         0x01
  #define DALI_DEVICE_TYPE    6
  #define PWM_NUM_CHANNELS    0
  #define EVG_NUM_COLOURS     1
  #define EVG_HAS_DT8         0
  #define EVG_DT8_HAS_TC      0
  #define EVG_DT8_HAS_PRIMARY 0
  #define ONOFF_MODE                  /* Guards: skip TIM1, skip led_driver */
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

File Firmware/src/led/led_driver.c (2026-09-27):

/*
    led_driver.c - LED output driver implementations

    Contains two compile-time selectable LED drivers:

    Default (DIGITAL_LED_OUT not defined):
      TIM1 PWM on up to 4 channels (PD2, PA1, PC3, PC4).
      2400-step resolution at 20 kHz. Per-channel colour scaling
      for DT8 RGBW support. Direct register writes.

    DIGITAL_LED_OUT defined:
      WS2812 / SK6812 addressable LED strip via SPI1+DMA on PC6 (MOSI).
      Non-blocking DMA transfer. All LEDs output the same colour
      (DALI controls the entire fixture as one unit).
      Supports WS2812 (3-byte GRB) and SK6812 RGBW (4-byte GRBW).

    The driver is selected by DIGITAL_LED_OUT / ONOFF_MODE in hardware.h.
*/

#include "ch32fun.h"
#include "led_driver.h"
#include "../config/hardware.h"

#ifdef ONOFF_MODE
/* ********************************************************************
 * ON/OFF MODE — No LED driver, PSU_CTRL only (handled in main.c)
 * ******************************************************************** */
void led_driver_init(void) {}
void led_driver_apply(uint8_t dali_level, const volatile uint8_t *colour) { (void)dali_level; (void)colour; }
void led_driver_refresh(void) {}
int  led_driver_busy(void) { return 0; }

#else /* !ONOFF_MODE */

/* ====================================================================
 * IEC 62386-102 §9.3 Logarithmic Dimming Curve
 * ====================================================================
 * DALI specifies logarithmic light output (Weber-Fechner law).
 * Formula: X(level) = 10^((level - 1) × 3 / 253 - 1)
 *          output = X / 100 × full_scale
 *
 * Table maps DALI level 1–254 → PWM value 0–2399.
 * Level 0 = OFF (not in table, handled as special case).
 *
 * For WS2812: values are scaled to 0–255 at runtime.
 * ==================================================================== */
static const uint16_t dali_log_table[254] = {
       2,    2,    3,    3,    3,    3,    3,    3,    3,    3,    3,    3,    3,    3,    4,    4,
       4,    4,    4,    4,    4,    4,    4,    4,    5,    5,    5,    5,    5,    5,    5,    6,
       6,    6,    6,    6,    6,    7,    7,    7,    7,    7,    8,    8,    8,    8,    8,    9,
       9,    9,    9,   10,   10,   10,   10,   11,   11,   11,   12,   12,   12,   13,   13,   13,
      14,   14,   15,   15,   15,   16,   16,   17,   17,   18,   18,   19,   19,   20,   20,   21,
      21,   22,   23,   23,   24,   24,   25,   26,   27,   27,   28,   29,   30,   30,   31,   32,
      33,   34,   35,   36,   37,   38,   39,   40,   41,   42,   43,   45,   46,   47,   48,   50,
      51,   52,   54,   55,   57,   59,   60,   62,   64,   65,   67,   69,   71,   73,   75,   77,
      79,   81,   83,   86,   88,   91,   93,   96,   98,  101,  104,  107,  110,  113,  116,  119,
     122,  126,  129,  133,  136,  140,  144,  148,  152,  156,  161,  165,  170,  174,  179,  184,
     189,  195,  200,  206,  211,  217,  223,  229,  236,  242,  249,  256,  263,  270,  278,  285,
     293,  301,  310,  318,  327,  336,  345,  355,  365,  375,  385,  396,  407,  418,  430,  441,
     454,  466,  479,  492,  506,  520,  534,  549,  564,  580,  596,  613,  630,  647,  665,  683,
     702,  722,  742,  762,  783,  805,  827,  850,  874,  898,  923,  948,  974, 1001, 1029, 1058,
    1087, 1117, 1148, 1180, 1212, 1246, 1280, 1316, 1352, 1390, 1428, 1468, 1508, 1550, 1593, 1637,
    1682, 1729, 1777, 1826, 1876, 1928, 1982, 2036, 2093, 2151, 2210, 2272, 2334, 2399,
};


#ifndef DIGITAL_LED_OUT
/* ********************************************************************
 * PWM DRIVER — TIM1 on up to 4 channels
 * ******************************************************************** */

/* Minimum pulse clamp + dynamic frequency shifting.
 *
 * Pulses shorter than the digital isolator's minimum pulse width (pi160M,
 * ~100 ns) reach the gate driver as runts with degraded levels and park the
 * MOSFET in its linear region — this killed the red-channel FET on the 250W
 * load board. Two-stage defence:
 *
 * 1. Dynamic frequency shift: whenever the SHORTEST active channel would
 *    need a pulse below the shift threshold at 20 kHz, TIM1's prescaler is
 *    switched from /1 to /3 → 6.67 kHz base frequency. Compare values stay
 *    identical (duty, and thus brightness, is unchanged), every tick just
 *    becomes 3x longer, so the same request renders as a 3x wider pulse.
 *    Frequency choice is a perception trade-off at 100% PWM modulation:
 *    <2.5 kHz shows stroboscopic/phantom-array artifacts to sensitive eyes
 *    (250 Hz was clearly visible even at 0.1% brightness), 2-5 kHz is the
 *    ear's peak sensitivity (2 kHz MLCC whine was loud on real hardware).
 *    6.67 kHz sits above phantom-array visibility and past the ear's peak,
 *    and the shift zone only carries sub-1.5%-duty currents.
 *    PSC is shadow-buffered → the switch is glitch-free at a period edge.
 * 2. Clamp (safety net): anything still below 250 ns in the current mode is
 *    forced fully off; a low GAP below 250 ns is forced fully on (CVR >
 *    ATRLR = static high, no 20.8 ns runt at value 2399).
 */
#define PWM_PERIOD_TICKS    2400                            /* = ATRLR + 1 */
#define PWM_MIN_PULSE_NS    250   /* hardware blanking failsafe (isolator limit) */
#define PWM_MIN_TICKS_FAST  ((PWM_MIN_PULSE_NS * 48) / 1000)       /* 12: 20.8 ns ticks */
#define PWM_MIN_TICKS_SLOW  ((PWM_MIN_PULSE_NS * 48) / 3000 + 1)   /*  5: 62.5 ns ticks */

/* Frequency-shift threshold — independent of (and well above) the failsafe.
 * Below this pulse width the strip's distributed RC visibly distorts the
 * colour balance along its length and edge times eat into linearity, so we
 * render the same duty at 2 kHz instead (pulse becomes 10x wider). */
#define PWM_SHIFT_PULSE_NS  250
#define PWM_SHIFT_TICKS     ((PWM_SHIFT_PULSE_NS * 48) / 1000)    /* 12: 20.8 ns ticks */

/* Whine guard: the MLCC/inductor whine at 6.67 kHz scales with the switched
 * current — a second channel at 50% duty was clearly audible on real HW,
 * below ~5% it fades out (tested 2026-07-23). Only shift when EVERY active
 * channel stays at or below 90 ticks (3.75% duty, ~10x a typical trigger
 * channel); otherwise stay at 20 kHz and let the failsafe clamp drop the
 * sub-250 ns channel instead — its light share is <1/10 of the dominant
 * channel, so the colour error is invisible. */
#define PWM_SHIFT_MAX_TICKS 90

static uint8_t pwm_slow;    /* 0 = 20 kHz (PSC /1), 1 = 6.67 kHz (PSC /3) */

static void pwm_set_frequency(uint8_t slow) {
    if (slow == pwm_slow)
        return;
    pwm_slow = slow;
    TIM1->PSC = slow ? 2 : 0;   /* buffered, takes effect at next update event */
}
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

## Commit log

2026-03-09 Initial commit: DALI EVG firmware, simulations, and documentation
    - CH32V003 DALI-2 slave firmware (IEC 62386-101/102)
    - LTspice PHY simulations (isolated + non-isolated)
    - IDEAL_DCDC behavioral model for bus-powered supply
    - Test cases and architecture documentation
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2026-03-19 added first revision of hardware
    [JLC_PCBA_BOM-DALI_EVG_Controller(V0.1).xlsx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]
2026-03-23 Added 250W LoadBoard
    [JLC_PCBA_BOM-DALI_EVG_Controller(V0.1).xlsx, JLC_PCBA_BOM-DALI_EVG_LoadBoard(V0.1).xlsx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]
2026-03-24 Updated J2
    [JLC_PCBA_BOM-DALI_EVG_Controller(V0.1).xlsx, JLC_PCBA_BOM-DALI_EVG_LoadBoard(V0.1).xlsx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]
2026-03-28 Corrected BOM
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2026-03-30 Changed EEPROM to 256kbit one for futureoroofing A/B Safe Bootloader
    [JLC_PCBA_BOM-DALI_EVG_Controller(V0.1).xlsx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]
2026-03-31 Renamed LoadBoard
    [JLC_PCBA_BOM-DALI_EVG_Controller(V0.1).xlsx, JLC_PCBA_BOM-DALI_EVG_LoadBoard(V0.1).xlsx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]
2026-04-16 Remapped pins to have WS2812 DOUT and PWM CH1 on the same pin
    [JLC_PCBA_BOM-DALI_EVG_Controller(V0.1).xlsx, JLC_PCBA_BOM-DALI_EVG_LoadBoard(V0.1).xlsx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]
2026-05-05 Fixed PA1 Boot-button evaluation
    [dali_bootloader.c, main.c]
2026-07-23 added LED-Driver failsafes
2026-08-25 Move bootloader replacement out of the application firmware
    Writing the CH32V003 BOOT area from user code only works while a debug
    module is active. Without one the FPEC reports success — EOP set, no
    error flag — and changes nothing at all, so the application firmware can
    never replace the bootloader in the field. dali_bl_update.c is therefore
    removed from it, freeing ~1.7 KB of flash (83.7% -> 72.1%).
    Bootloader replacement becomes an emergency procedure instead. The new
    BL-Emergency-Flasher project builds a throw-away firmware that carries the
    bootloader compiled in — embed_bootloader.py pulls the binary from
    ../Bootloader at build time — and programs the boot area itself, enablin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
    [main.c]
2026-08-25 Adopt the optimised bootloader (1908 B, HIL-verified)
    Frees 56 B and spends 52 of them on three robustness fixes that did not
    fit before:
    - Read-back verify after the EEPROM -> flash copy. Previously only the
    received DALI bytes were checksummed; the commit path itself was
    unverified, so an I2C glitch or a failed flash write still produced a
    written vector page and a device that boots corrupt code. On mismatch
    the vector page is erased again, 0xFF is sent, and the device resets
    back into the bootloader for an immediate retry.
    - Erase the full 16 KB. The old NUM_PAGES subtracted the bootloader size
    from the user flash even though the bootloader lives in the separate
    boot area,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
    [dali_bootloader.c]
2026-08-25 Fix the WS2812 output path
    The strip showed wrong colours on its first LEDs — LED 1 badly, LED 2
    slightly, LED 3 onwards correct — and only ever after a periodic refresh;
    the first frame following boot was always right. A logic analyser on the
    data line plus a shadow copy of the DMA buffer read back over SWD showed
    the RAM contents were correct while the wire was not, which ruled out the
    fill code and pointed at the transfer itself.
    Root cause: __WFI() stalls SPI1 and DMA, contrary to the comment claiming
    all peripherals keep running. The DMA fills the SPI pipeline with two
    halfwords, the core sleeps, and MOSI freezes at its current level for
    ~977 us until the next SysTick. A 256 us fra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
    [hardware.h, led_driver.c, main.c]
2026-08-25 Keep the bootloader emergency flasher out of the repository
    The path is not being pursued for now: the bootloader is validated once and
    flashed with the WCH-LinkE during commissioning, so a field-update route is
    not needed. The project stays on disk but is gitignored, and the work gets
    picked up again only if a deployed bootloader ever actually needs fixing.
    It was never functional anyway. Both installation attempts failed — not
    because of the flasher, but because the bootloader in the boot area at the
    time still had the i2c_init() nibble bug and hung before it could receive
    the image. What was demonstrated on hardware is the underlying mechanism:
    writing the BOOT area from user code work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
    [main.c]
2026-08-25 Remove the "Update BL..." button from the updater GUI
    The bootloader emergency path is shelved, so the button has nothing to
    offer: it would install a flasher image that is no longer part of the
    repository. Removing it also takes the risk out of the GUI — the button
    replaced the running application firmware, which is not something to have
    one click away in a dialog meant for ordinary updates.
    The flashbl CLI command stays for the day the path is picked up again.
2026-08-27 Bring the documentation back in line with the code
    A consistency pass over all markdown files after the bootloader and
    WS2812 work:
    - Bootloader size was still quoted as 1,840 B in four places; it is 1,908 B
    since the optimised version was adopted.
    - Bootloader/README described neither the commit marker nor the three
    safeguards on the commit path, and still claimed a power loss mid-commit
    leaves the device unbootable and needing a WCH-Link. With the vector page
    written last that is no longer true: the next power-on lands back in the
    bootloader with the EEPROM staging intact. Phase 4 now also mentions the
    read-back verify, the full 16 KB erase and the empty-update rejection,
    ea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
2026-09-03 Add the Digital LED load board and align the documentation
    - New Hardware/DALI_Load_250W_DigitalLED with the V0.1 fabrication data and
    a Readme covering the connectors, the strip supply and the isolation barrier
    - Controller Readme links the two load boards from the actuation paths they
    implement, instead of only describing the options in the abstract
    - Root README corrections against the sub-READMEs: Controller is V0.3, the
    bootloader is 1908 / 1920 B, there are 8 output modes (ONOFF was missing),
    and both load boards are listed
    - Drop the user-flash size figures from the firmware docs; the boot-area
    figures stay, because that limit is a real constraint
    - Refresh the Controller V0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
    [DALI_LOAD_DigitalLED(V0.1).step, DALI_LOAD_DigitalLED(V0.1).x_t, JLC_PCBA_BOM-DALI_EVG_Controller(V0.3).xlsx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]
2026-09-03 Refresh the fabrication exports
    Regenerated output job data, mostly for the Digital LED load board
    (Gerbers, BOM and the JLC BOM/CPL pair). The Controller and RGBW Gerber
    archives only differ in their zip timestamps.
    [JLC_PCBA_BOM-DALI_LOAD_DigitalLED(V0.1).xlsx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]
2026-09-03 Update the Digital LED load board schematic export
    The Gerber archives alongside it differ only in their zip timestamps.
2026-09-03 Spell out the ribbon usage and the strip supply range
    Only PWM_CH1 carries data; GND, +3V3-PRI and PSU-CTRL are the only other
    signals the board taps. The remaining six reach the connector unconnected.
    The 5 V ... 24 V strip supply now appears in the feature list and as a
    callout, since it decides which strip and PSU pair with the board.
2026-09-27 Widen the WS2812 one-bit pulse and make the wire order switchable
    The 1110 encoding put T1H at 989 ns, measured on the strip data line at a
    1 ns sample interval. WS2812B allows 800 ns +/- 150 ns, so that sat 39 ns
    over the limit and further outside the tighter windows of WS2811, WS2812
    non-B and SK6812. 1100 moves it to 660 ns, inside all of them. T1L grows
    to 659 ns in exchange, which only has to stay far below the 50 us latch
    time - the parameter that decides the bit value is the high time.
    Byte order becomes a compile-time option instead of a hardcoded GRB.
    Older WS2811 strips expect RGB, which showed as red and green swapped:
    the hue sweep ran green, then red, then blue. EVG_WS2811_RGB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
    [hardware.h, led_driver.c]
2026-09-27 Replace the PowerShell flasher with EVG-Flasher, port the updater to Avalonia
    EVG-Flasher runs the same four-step provisioning sequence as the former
    flash_blank_evg.ps1 - bootloader, option bytes, firmware, option-byte
    read-back - and adds an auto mode that picks up each chip as it is
    connected. The configuration dropdown is read from Firmware/platformio.ini
    at runtime, so a new [env:...] section shows up without touching the app,
    and the strip length reaches the build through PLATFORMIO_BUILD_FLAGS
    instead of editing the .ini.
    EVG-Updater moves off WinForms. Only MainForm carried UI code; the
    gateway, bootloader and scanner classes are unchanged. Every CLI
    subcommand keeps working, and th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
2026-09-28 Add the 3D-printable enclosure
    Fusion 360 archive plus a neutral STEP export. One enclosure takes the
    Controller together with any of the load boards, so it does not need a
    variant per load board.
    [DALI_EVG.f3z, DALI_EVG.step]
2026-09-28 Add the printable enclosure parts
    Bot, Mid and Top as STL, sliced straight from the Fusion model already in
    this folder.
    [Bot.stl, Mid.stl, Top.stl]
2026-09-28 Show the enclosure as an exploded view
    Renders the three printed parts with the Controller and a load board
    stacked between them, which says more about how the housing goes together
    than the part list does.
2026-09-28 Name the screws and the FFC variant
    The cable was documented as 10-pin, 0.5 mm pitch, but neither its length
    nor the contact orientation appeared anywhere - and the reverse variant is
    what makes the pinout come out the right way round.
2026-09-28 Correct why a same-side FFC will not do
    It is not that the pin order comes out mirrored - the cable simply makes
    no contact, because at one end the exposed side faces away from the
    connector.
2026-09-28 Correct the screw length to M2.5 x 10
2026-09-28 Show where the eight screws go
    Four enter from each side, which is what the length is for. The exploded
    view alone does not show the fasteners, so the assembled render sits next
    to the count.
2026-09-28 Draw the FFC cable
    The side view carries the point: exposed contacts on top at one end and
    on the bottom at the other. Deliberately without pin numbers - which
    conductor lands on which connector pin follows from the board layout, not
    from the cable.
2026-09-28 Allow shorter FFC cables: 25-50 mm
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2026-09-28 Add a photo of the assembled unit
    Shows the printed enclosure as it actually comes out - screws, terminal
    blocks and the FFC in its side slot - next to the renders, and once on the
    front page.
2026-09-28 Let the updater reflash an EVG to a different mode
    The bootloader validates Block 0 against the EVG mode the running firmware
    wrote into the EEPROM identity block, so switching a device from, say,
    WS2812 to SK6812 RGBW means announcing the mode it has now - not the one
    it is about to get. The new firmware rewrites the identity block on its
    first boot.
    The new checkbox takes that current mode from the scan instead of the
    input field, which removes the trap of passing the target mode and getting
    a Block 0 fault. "Update All" already resolved the mode per row and is
    unaffected.
2026-09-28 Size the device grid columns to their content
    SK68RGBW was clipped mid-glyph and read as SK68RGBV - a wrong mode name,
    not just an ugly one. Auto width with a minimum per column fixes it for
    every column at once instead of guessing a new pixel value for this one.
2026-09-28 Swap the Digital LED buck to the ME3116
    The LGS5145 refused to start below 5.2 V on the bench, a full volt above
    the 4.2 V UVLO its datasheet gives, so a 5 V PSU never brought the rail up.
    Its frequency fold-back at low feedback voltage is the likely reason: at
    start-up FB is low by definition, and with little input headroom the part
    never gathers enough volt-seconds to leave the hiccup.
    The ME3116 is a drop-in - same SOT23-6 pinout, and with a 0.8 V reference
    instead of 0.812 V the existing 51k/10k divider lands at 4.88 V. Measured
    4.44 V out at 5 V in, which clears the 3.5 V the strip needs on its data
    line, so one assembly now covers 5 V to 24 V and R7 stays not fitted.
    [JLC_PCBA_BOM-DALI_LOAD_DigitalLED(V0.1).xlsx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]
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2026-10-02 Add printable enclosure top labels for both load boards
    A 40 x 24 mm landscape label that clamps under the four M2.5 screws on the
    enclosure top, printed on the 33.15 x 17 mm hole pattern. Shows both ends of
    the stack: LED connector and DC input on one side, DALI and mains on the
    other, plus a write-in field for the short address.
    Shipped as an 80 x 66 mm sheet with crop marks and a 20 mm scale bar, so a
    printer that silently rescales can be spotted before cutting.
2026-10-03 Digital LED board: 250 V rated mains fuse
    F1 was a Littelfuse 0154 in 1808, rated 125 V only. Replaced by a 1032
    ceramic SMD fuse rated 250 V. The old part sat in a holder, so the
    footprint stays practically the same. Fab outputs regenerated, ODB++ added.
    [DALI_LOAD_DigitalLED(V0.1).step, DALI_LOAD_DigitalLED(V0.1).x_t, JLC_PCBA_BOM-DALI_LOAD_DigitalLED(V0.1).xlsx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]
2026-10-03 RGBW board V0.3, creepage slots, mains-safety note on enclosure screws
    RGBW load board moves to V0.3: 1032 ceramic fuse rated 250 V in place of
    the 125 V Littelfuse 0154, and a pinout drawing for the first time. Both
    load boards get slots that lengthen the creepage path from the mains copper
    to the enclosure screws, and a 3.9 mm AC-to-LV clearance rule that checks
    the air gap across those slots.
    The screws only keep the required distance from the mains side when the
    head rests on the plastic housing, never on the PCB itself. The Hardware
    README and both load-board READMEs now say so.
    [DALI_LOAD_DigitalLED(V0.1).step, DALI_LOAD_DigitalLED(V0.1).x_t, DALI_Load_250W_RGBW(V0.3).step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]
2026-10-03 RGBW V0.3: regenerate fab data after a layout fix
    Gerber, drill, outline, STEP/Parasolid, pinout and assembly drawings
    re-exported. The Controller and Digital LED gerber archives were only
    re-exported; their content is unchanged.
    [DALI_Load_250W_RGBW(V0.3).step, DALI_Load_250W_RGBW(V0.3).x_t]
2026-10-11 Digital LED board V0.2, LCSC-filled BOMs, opto-triac driven from the bus
    Digital LED load board moves to V0.2. The B0505S feedback rail is gone on
    both load boards: DALI is FELV per IEC 62386-101 4.9.2, so the barrier to
    the touchable LED side needs supplementary insulation for 230 V, and the
    module was only specified for 1.5 kV DC. The opto-triac is now an IL4118
    (1.3 mA trigger current) driven straight from the bus. The READMEs give the
    measured bus current at 16 V: 1.67 mA with the LED supply off, 3.9 mA on.
    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
2026-10-11 Load boards: continuous bus current above the 2 mA budget while lit
    With the feedback rail gone, the IL4118 opto-triac draws from the DALI bus
    for as long as the LED supply is on, so the 2 mA budget is exceeded
    continuously, not just at turn-on. Expected bus current at 16 V is about
    2.6 mA; this is an estimate until the IL4118 is measured. 1.67 mA with the
    LED supply off is measured. The 3.9 mA in the previous commit were taken
    with the old MOC3043.
2026-10-11 RGBW V0.3: layout fixes for the DALI-to-LED-side clearance
    The RGBW board now has a 2.5 mm clearance rule between the DALI side and
    the LED side (supplementary insulation, DALI being FELV). Copper, drill,
    legend, paste and solder mask regenerated after fixing the spots it
    flagged.
    Controller and Digital LED gerbers were re-exported alongside; only the
    export ID and checksum headers changed there, no geometry. The JLC BOM and
    CPL spreadsheets of all three boards are re-saved with unchanged content.
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2026-10-12 Fade to off on DAPC(0) and scene recall instead of switching off instantly
    IEC 62386-102 requires DAPC(0) to use the fade time like any other level:
    dim down to minLevel, then switch off as the last step at the end of the
    fade. The firmware special-cased level 0 in three places (DAPC, scene
    recall, dali_fade_start) and jumped straight to 0. OFF and STEP DOWN AND
    OFF still switch off immediately, as specified.
    Verified on an RGBW EVG with fade time 1.0 s: QUERY ACTUAL LEVEL after
    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
2026-10-12 Make DT8 colour queries and temporaries conform to IEC 62386-209
    A beta tester's DALI master refused to set colours: QUERY COLOUR TYPE
    FEATURES reported 0 RGBWAF channels and QUERY COLOUR STATUS claimed
    "auto calibration running". The DT8 query answers used the wrong bit
    layouts throughout:
    - 249 COLOUR TYPE FEATURES: Tc bit + number of RGBWAF channels in
    bits 5-7 (0x82 for RGBW) instead of a bogus "primary N" flag (0x06)
    - 248 COLOUR STATUS: active colour type in bits 5/7 (+ bit 1 when a Tc
    was clamped) instead of the xy-out-of-range / calibration bits
    - 250 COLOUR VALUE: selectors per Table 11 (Tc, RGBWAF levels, control,
    Tc limits 154/370 mirek, temporary and report values), 16-bit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
2026-10-12 EVG-Updater: show and verify the firmware build from memory bank 2
    A FINISH whose fault answer got lost looked like success: the updater
    reported SUCCESS while the bootloader had resumed the old firmware.
    - Phase 5 after FINISH: wait for the reboot, read the build identity
    from bank 2 and compare it with the EVGBUILD record in the flashed
    image. Mismatch or no answer -> FAILED with the build actually
    running. Images without a record skip the check with a warning.
    - Scan: new Build column (local build time + git commit, "+" = dirty)
    in the GUI grid and the CLI table. DTR1/DTR0 are now selected per
    gear, since the bank-2 read moves them for every gear on the bus.
    Verified: scan of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
2026-10-12 EVG-Updater: leave the bootloader time to write each EEPROM page
    About every third DALI update failed with a Fletcher-16 mismatch at
    FINISH. A passive bus recorder (second EVG timestamping every edge)
    showed the frames byte-perfect on the wire and the Fletcher matching in
    the failed runs too, so the updated EVG itself lost a frame.
    The bootloader stages the payload in 64-byte EEPROM pages and is deaf
    while it writes one: ~0.6 ms after the frame, ~6 ms of I2C at 100 kHz,
    then ACK polling for the write cycle (up to 5 ms) - up to ~11.7 ms. The
    gateway's frame gap is only 11.2-12 ms, so a slow write cycle made the
    bootloader miss the next start bit and drop that frame.
    After every frame that c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
